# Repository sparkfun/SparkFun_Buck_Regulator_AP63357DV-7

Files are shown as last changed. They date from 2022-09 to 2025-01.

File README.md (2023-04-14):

SparkFun 5V Buck Regulator Breakouts - AP63357
========================================

<p align="center">
  <a href="https://github.com/sparkfun/SparkFun_Buck_Regulator_AP63357DV-7/issues" alt="Issues">
    </a>
  <a href="https://github.com/sparkfun/SparkFun_Buck_Regulator_AP63357DV-7/actions" alt="Actions">
    </a>
  <a href="https://github.com/sparkfun/SparkFun_Buck_Regulator_AP63357DV-7/blob/main/LICENSE.md" alt="License">
    </a>
  <a href="https://twitter.com/intent/follow?screen_name=sparkfun">
    </a>
</p>

These buck regulator boards feature the AP63357 from [Diodes Inc.](https://www.diodes.com/), a 3.5A synchronous buck converter with a wide input voltage range of 3.8V to 32V. The fully integrated 74m&ohm; high-side power MOSFET/40m low-side power MOSFET provide a high-efficiency step-down DC/DC conversion. The boards are configured to provide a regulated **5V** output and feature a high-voltage `EN` *(enable)* control pin that is rated up to 32V. The boards also include 0.1" spaced PTH pins to connect the input and output power and a copper pad is provided to attach a heat sink to the bottom of the board; to dissipate excess heat.

| [5V Buck Regulator (COM-21255)](https://www.sparkfun.com/products/21255) | [5V BabyBuck Regulator (COM-21256)](https://www.sparkfun.com/products/21256) |
| --- | --- |
| SparkFun Buck Regulator Breakout - 5V (AP63357DV) (https://www.sparkfun.com/products/21255) | SparkFun BabyBuck Regulator Breakout - 5V (AP63357DV) (https://www.sparkfun.com/products/21256) |
| The [Buck regulator breakout board](https://www.sparkfun.com/products/21255), has additional options for connecting input and output power. There is a pre-assembled screw terminal for a non-permanent connection and the option to solder on a [barrel jack](https://www.sparkfun.com/products/119) for an [external power supply](https://www.sparkfun.com/categories/308). The board also includes and red, power indication LED for when the power output is enabled. | Unlike its sibling, the [BabyBuck](https://www.sparkfun.com/products/21256) is a minimalistic board that sacrifices the connection options for space. Don't worry, though, because the PTH pins are still available to connect the input and output power. All of this snuggled up in a low-profile, .63" x .52" board. |

Repository Contents
-------------------

* **[/docs](/docs/)** - Online documentation files
    * [board_files](/docs/board_files/) - Files for the product design
        * [Eagle design files](/docs/board_files/eagle_files.zip) (.zip)
        * [Schematic](/docs/board_files/schematic.pdf) (.pdf)
        * [Dimensions](/docs/board_files/dimensions.pdf) (.pdf)
    * [component_documentation](/docs/component_documentation/) - Datasheets for hardware components
    * [img/hookup_guide/](/docs/img/hookup_guide/) - Images for hookup guide documentation
* **[/Hardware](/Hardware/)** - Eagle design files (.brd, .sch)

Documentation
--------------
* **[Hookup Guide (mkdocs)](http://docs.sparkfun.com/SparkFun_Buck_Regulator_AP63357DV-7/)** - Hookup Guide for the 5V Buck Regulator Breakouts

Product Variants
----------------
* **AP63357 - 5V Buck Regulators**
    * COM-21255: [SparkFun Buck Regulator Breakout - 5V (AP63357DV)](https://www.sparkfun.com/products/21255)
    * COM-21256: [SparkFun BabyBuck Regulator Breakout - 5V (AP63357DV)](https://www.sparkfun.com/products/21256)
* **AP63203 - 3.3V Buck Regulators**
    * COM-18356: [SparkFun Buck Regulator Breakout - 3.3V (AP63203)](https://www.sparkfun.com/products/18356)
    * COM-18357: [SparkFun BabyBuck Regulator Breakout - 3.3V (AP63203)](https://www.sparkfun.com/products/18357)
* **AP3429A - 3.3V & 1.8V Buck Regulators**
    * COM-21337: [SparkFun Buck Regulator Breakout - 3.3V (AP63203)](https://www.sparkfun.com/products/21337)
    * COM-21338: [SparkFun Buck Regulator Breakout - 1.8V (AP63203)](https://www.sparkfun.com/products/21338)

Version History
---------------
* [v01](https://github.com/sparkfun/SparkFun_Buck_Regulator_AP63357DV-7/releases/tag/v01) - Initial Release

License Information
-------------------

This product is _**open source**_! 

Please review the LICENSE.md file for license information. 

If you have any questions or concerns about licensing, please contact technical support on our [SparkFun forums](https://forum.sparkfun.com/viewforum.php?f=152).

Distributed as-is; no warranty is given.

- Your friends at SparkFun.

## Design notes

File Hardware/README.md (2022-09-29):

SparkFun <PRODUCT NAME> Design Files
=====================================

The .sch and .brd files hare are Eagle CAD schematic and PCB design files from SparkFun Electronics.
A freeware version of Autodesk Eagle can be found [here](https://www.autodesk.com/products/eagle/free-download).

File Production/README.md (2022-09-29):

SparkFun <PRODUCT NAME> Production Files
=========================================

These are the production files SparkFun uses for printing PCBs.

License Information
-------------------
This product is open source! 

The hardware is released under [Creative Commons ShareAlike 4.0 International](https://creativecommons.org/licenses/by-sa/4.0/).

Please use, reuse, and modify these files as you see fit. Please maintain attribution to SparkFun Electronics and release anything derivative under the same license.

Distributed as-is; no warranty is given.

- Your friends at SparkFun.

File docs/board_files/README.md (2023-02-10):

board_files directory
====================

1. A `dimensions.pdf` file containing the boards' measurements.
2. A `schematic.pdf` file containing the boards' schematics.
3. An `eagle_files.zip` folder containing the Eagle CAD schematics (`*.sch`) and PCB design (`*.brd`) files.
    * A freeware version of Autodesk Eagle can be found [here](https://www.autodesk.com/products/eagle/free-download).

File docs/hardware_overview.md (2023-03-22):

---
icon: material/cog
---

!!! hot "**Danger:** These boards can get <span style="color: #ff1744;">extremely **HOT** :material-thermometer-alert:</span>"
	
	Please handle these boards with the utmost caution. Users can easily burn themselves when the board outputs anything over 2A. 

## Board Dimensions
The board dimensions are illustrated in the drawing below; the listed measurements are in inches.

<figure markdown>
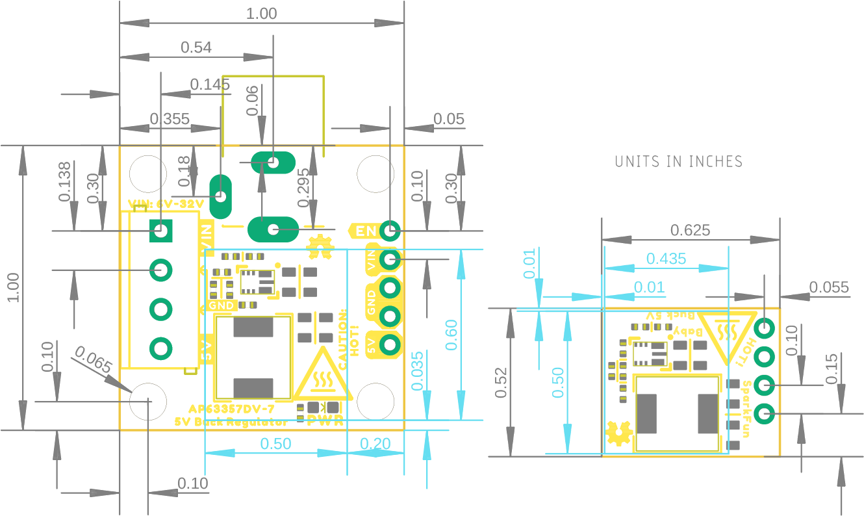
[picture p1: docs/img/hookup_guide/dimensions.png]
Board Dimensions

<figcaption markdown>
[Board dimensions (PDF)](../board_files/dimensions.pdf) for the 5V buck regulator breakouts (AP63357), in inches.
</figcaption>
</figure>

??? tip "Need more measurements?"
	For more information about the board's dimensions, users can download the [eagle files](../board_files/eagle_files.zip) for the board. These files can be opened in Eagle and additional measurements can be made with the dimensions tool.

	??? info ":octicons-download-16:{ .heart } Eagle - Free Download!"
		Eagle is a [CAD]("computer-aided design") program for electronics that is free to use for hobbyists and students. However, it does require an account registration to utilize the software.

		<center>
		[Download from<br>:autodesk-primary:{ .autodesk }](https://www.autodesk.com/products/eagle/free-download "Go to downloads page"){ .md-button .md-button--primary width="250px" }
		</center>
	
	??? info ":straight_ruler: Dimensions Tool"
		This video from Autodesk demonstrates how to utilize the dimensions tool in Eagle, to include additional measurements:

		<center>
		<div class="video">
		<iframe src="https://www.youtube.com/embed/dZLNd1FtNB8" title="EAGLE Dimension Tool" frameborder="0" allow="accelerometer; autoplay; clipboard-write; encrypted-media; gyroscope; picture-in-picture" allowfullscreen></iframe>
		</div>
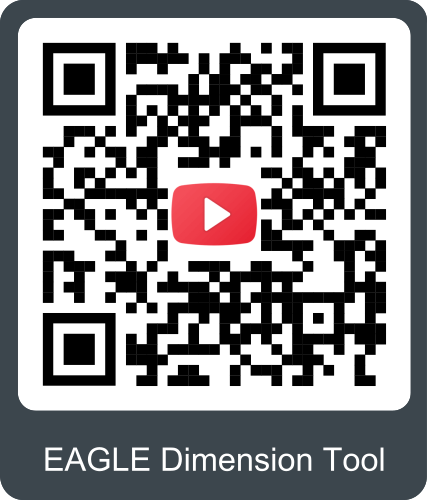
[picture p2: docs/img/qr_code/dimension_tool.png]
QR code to play video
		
		</center>

## Power
Users are provided with [PTH](https://en.wikipedia.org/wiki/Through-hole_technology "Plated Through Holes") to connect their external power supply, the output voltage from the board, and the [`EN`](#power-control "Enable") power control pin for the buck regulator. The AP63357 buck regulator has an input voltage range is **3.8V** to **32V**. However, the boards require a **6V** minimum power supply to operate; as it is a step-down DC/DC converter with a 5V output. *(i.e. The boards cannot step-up or boost the voltage output.)*

<center>
<table class="pdf">
	<tr>
		<td align="center">
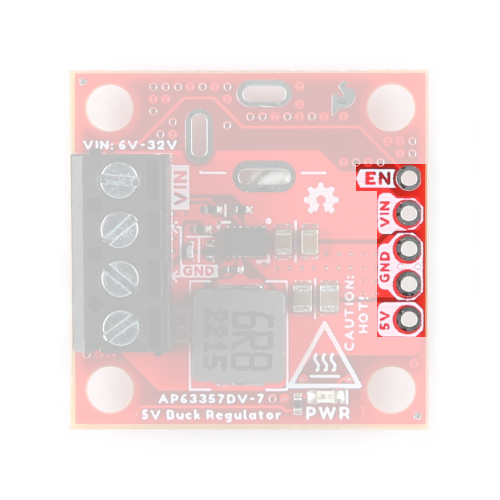
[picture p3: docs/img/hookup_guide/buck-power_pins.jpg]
			<br>
			<i>The PTH power pins on the 5V Buck Regulator (AP63357DV).</i>
		</td>
		<td align="center">
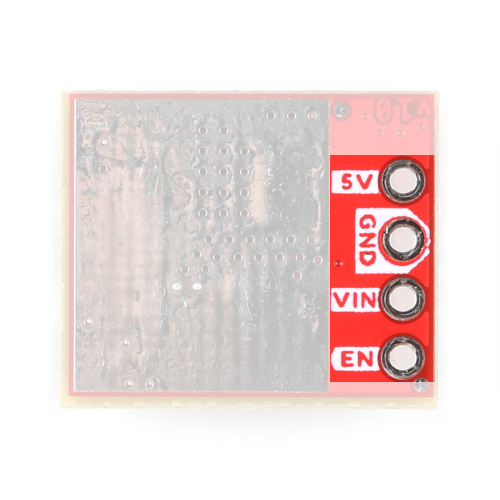
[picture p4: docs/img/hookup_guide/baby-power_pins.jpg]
			<br>
			<i>The PTH power pins on the 5V Baby Buck Regulator (AP63357DV), viewed from the bottom.</i>
		</td>
	<tr>
</table>
</center>

<div class="grid cards hide" markdown>

-   <figure markdown>
	
	<figcaption markdown>
	The PTH power pins on the 5V Buck Regulator (AP63357DV).
	</figcaption>
	</figure>

-   <figure markdown>
	
	<figcaption markdown>
	The PTH power pins the 5V Baby Buck Regulator (AP63357DV), viewed from the bottom.
	</figcaption>
	</figure>

</div>

Below, is a general summary of the circuitry on the board:

* **`VIN`** - Power supply input *(**6V to 32V**)*
    * The [undervoltage lockout](#undervoltage-lockout "UVLO") will engage intermittently if the input voltage is below **6V**.
* **`EN`** - Enables the power output of the board
	* Has an input voltage range up to **32V** 
	* Must be pulled `HIGH` above **1.18V** to enable the power output.
* **`5V`** - Regulated 5V output *(up to 3.5A)*
* **`GND`** - The common ground or the 0V reference for the board

!!! info
	For more details, users can reference the [schematic](../board_files/schematic.pdf) and the [datasheets of the individual components](../component_documentation.md) in the power circuitry.

!!! tip "Limitations - Load Current"
	* While the IC is rated up to 3.5A, users may experience thermal limitations towards that maximum.
		* Users should reasonably expect to be able to place a maximum 3A load on the boards when using a heat sink and active cooling (i.e. fan). 
		* At the peak load of 3.5A, users will need sufficient cooling to prevent the IC's [thermal shutdown](#thermal-characteristics "The AP63357 has a 170&deg;C (338&deg;F) thermal shutdown temperature.")
	* With a heat sink, we have found users can expect to draw up to 2.5A
	* Without a heat sink or active cooling, we recommend users not load the boards with more than 1.5A.

??? tip "Quiescent Current Draw"
    Users should expect a maximum quiescent current draw of ~365&micro;A from the board due to the voltage divider for the [UVLO](#undervoltage-lockout "Undervoltage Lockout"). For a lower quiescent current, users can modify the board by removing the voltage divider's resistors.

	<div class="grid cards" markdown>

	-	Measured Values

		---

		<center>
		
		| Input Voltage (V) | I~q~ (&micro;A) | I~q~ - Power Enabled (&micro;A) |
		| :-: | :-: | :-: |
		| 6 | 65 | 196 |
		| 12 | 129 | 209 |
		| 24 | 260 | 290.5 |
		| 32 | 330 | 355 |

		</center>

		!!! info
			For more information about the measured values for the quiescent current, please refer to this [GitHub issue](https://github.com/sparkfun/SparkFun_Buck_Regulator_AP63357DV-7/issues/1).

	-	=== "Buck Regulator"
			
			<figure markdown>
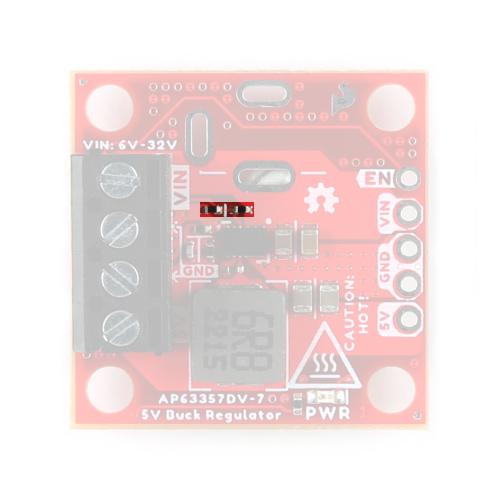
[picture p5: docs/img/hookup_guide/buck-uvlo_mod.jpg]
			
			<figcaption markdown>
			Resistors for the UVLO on the 5V Buck Regulator (AP63357DV).
			</figcaption>
			</figure>
	
		=== "BabyBuck Regulator"
			
			<figure markdown>
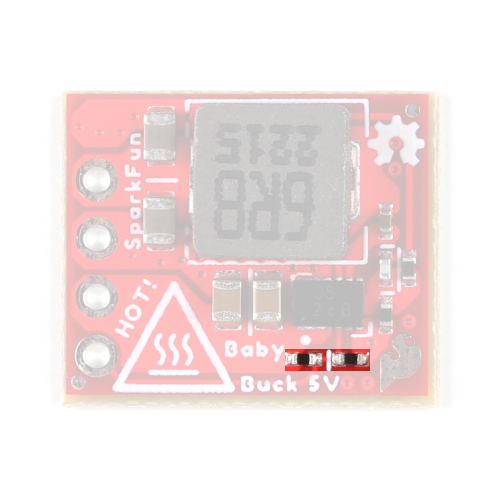
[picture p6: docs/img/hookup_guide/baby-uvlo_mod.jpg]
			
			<figcaption markdown>
			Resistors for the UVLO on the 5V Baby Buck Regulator (AP63357DV).
			</figcaption>
			</figure>
		
		!!! danger
			Modifying a board to remove the voltage divider, requires advanced soldering skills. Users should **not** attempt this modification unless it is absolutely, necessary and they are confident in their skills because the board can be permanently damaged.

	</div>

### Alternative Connections

!!! info  "Buck Regulator *(only)*"
	!!! warning "The following features are only available on the Buck Regulator and are <u>not</u> available on BabyBuck Regulator."

	=== "Barrel Jack"
		PTH *(slots)* are provided for users to add a [barrel jack connector](https://www.sparkfun.com/products/119) to the top or bottom of the board. This provides users with an alternative method to connect a power supply to their board.

		<figure markdown>
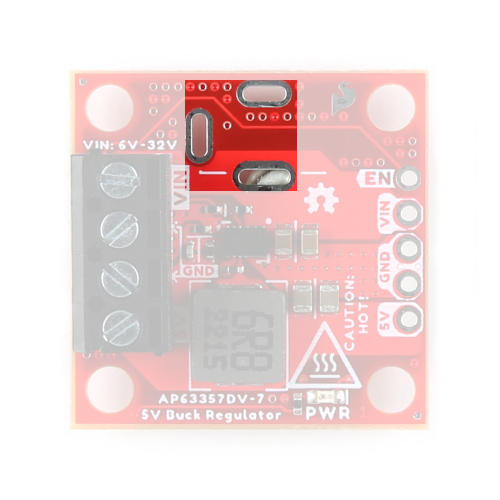
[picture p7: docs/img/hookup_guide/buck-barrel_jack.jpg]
		
		<figcaption markdown>The plated slots for a barrel jack connector on the 5V Buck Regulator (AP63357DV).</figcaption>
		</figure>

	=== "Screw Terminals"
		A screw terminal is provided for users, as a non-permanent solution, to easily connect wires to the board. The screw terminal is compatible with the following wire sizes from **26AWG** to **16AWG**.

		<figure markdown>
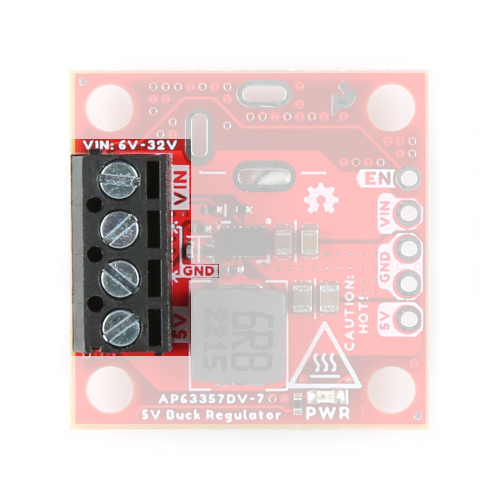
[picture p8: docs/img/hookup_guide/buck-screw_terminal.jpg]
		
		<figcaption markdown>The screw terminal on the 5V Buck Regulator (AP63357DV).</figcaption>
		</figure>

### Power LED
The red, power (`PWR`) LED will light up when the switching power output is enabled. *(Not available on baby buck regulator board.)*

<figure markdown>
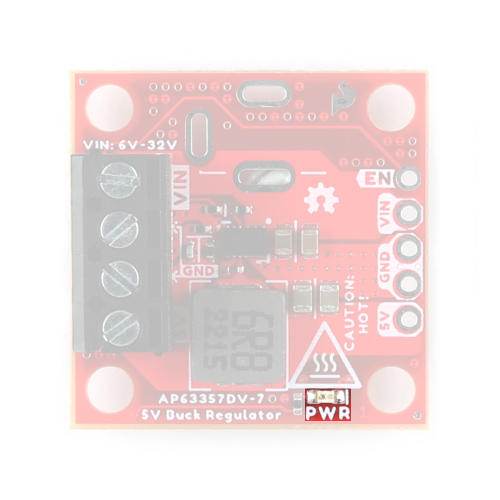
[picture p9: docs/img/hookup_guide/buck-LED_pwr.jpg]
Power LED

<figcaption markdown>
The `PWR` status LED indicator for the 5V Buck Regulator (AP63357DV).
</figcaption>
</figure>

### Power Control
There is a high-voltage enable pin (`EN`) to control the output voltage *(i.e. on/off)*, with a typical threshold voltage of **1.18V** and a range up to **32V**

* Users should pull the `EN` pin high *(above 1.18V)* to enable the switching power output and pull the pin low to disable it.
* As a high-voltage pin, users can also connect the `EN` pin to `VIN` to automatically start up the device.
* Users can also configure the `EN` pin to set the [UVLO](#undervoltage-lockout "Undervoltage Lockout") threshold.

!!! info "Default Configuration"
	On our boards, the `EN` pin is used to set the [UVLO](#undervoltage-lockout "Undervoltage Lockout") threshold. Therefore, the power output from the board is enabled by default.

<center>
<table class="pdf">
	<tr>
		<td align="center">
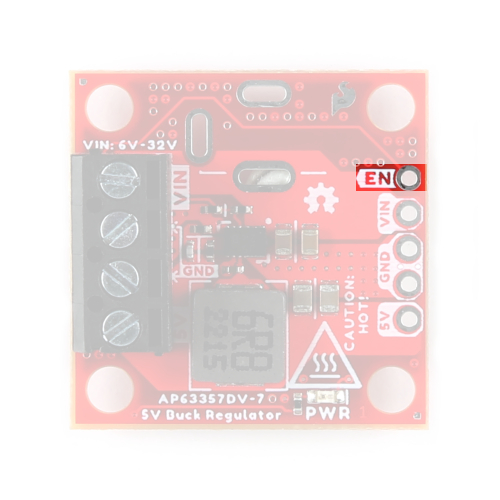
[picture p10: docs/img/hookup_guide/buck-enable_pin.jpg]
			<br>
			<i>Enable pin on the 5V Buck Regulator (AP63357DV).</i>
		</td>
		<td align="center">
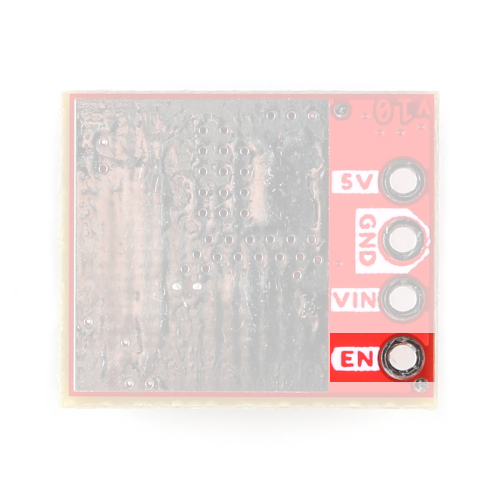
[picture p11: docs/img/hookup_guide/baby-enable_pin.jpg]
			<br>
			<i>Enable pin on the 5V Baby Buck Regulator (AP63357DV), viewed from the bottom.</i>
		</td>
	<tr>
</table>
</center>

<div class="grid cards hide" markdown>

-   <figure markdown>
	
	<figcaption markdown>
	Enable pin on the 5V Buck Regulator (AP63357DV).
	</figcaption>
	</figure>

-   <figure markdown>
	
	<figcaption markdown>
	Enable pin on the 5V Baby Buck Regulator (AP63357DV), viewed from the bottom.
	</figcaption>
	</figure>

</div>

## AP63357
The [AP63357](../component_documentation/AP63356-AP63357.pdf) from [Diodes Incorporated](https://www.diodes.com/), is a 3.5A, synchronous buck converter with a wide input voltage range of 3.8V to 32V. The device fully integrates a 74m&ohm; high-side power MOSFET and a 40m&ohm; low-side power MOSFET to provide high-efficiency step-down DC-DC conversion. When operating in PFM during light load conditions, the AP63357 can achieve a power efficiency of up to 86% with a 5mA load. Additionally, under a no-load, non-switching condition, the quiescent current is typically 22&micro;A; and when disabled, the device shutdown supply current is only 1μA.

The AP63357 features a high-voltage `EN` pin that can be directly connected to `VIN` to automatically start up the device. To prevent output voltage overshoot and inrush current, the AP63357 also has a built-in 4ms soft-start time. Users can also configure the `EN` pin to set the [undervoltage lockout](#undervoltage-lockout "UVLO") threshold.

<center>
<table class="pdf" markdown="1">
<tr markdown="1">
<td rowspan="2" markdown="block">
Features:

* VIN 3.8V to 32V
* 3.5A Continuous Output Current
* 0.8V ± 1% Reference Voltage
* 22&micro;A Low Quiescent Current (Pulse Frequency Modulation)
* 450kHz Switching Frequency
* Supports Pulse Frequency Modulation (PFM)
	* Up to 86% Efficiency at 5mA Light Load
* Proprietary Gate Driver Design for Best EMI Reduction
* Frequency Spread Spectrum (FSS) to Reduce EMI
* Low-Dropout (LDO) Mode
* Power Good Indicator with 5MΩ Internal Pull-up
* Precision Enable Threshold to Adjust UVLO
* Protection Circuitry
	* Undervoltage Lockout (UVLO)
	* Output Undervoltage Protection (UVP)
	* Cycle-by-Cycle Peak Current Limit
	* Thermal Shutdown
</td>
<td align="center">
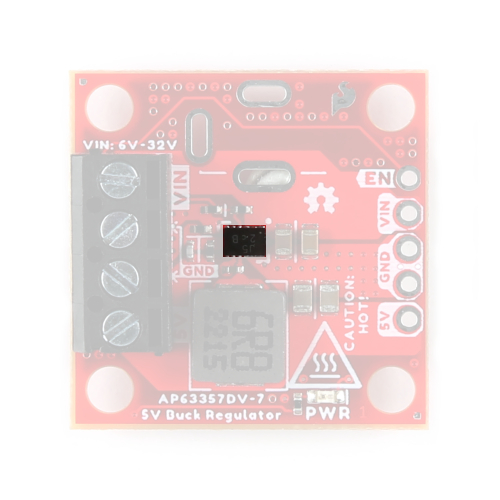
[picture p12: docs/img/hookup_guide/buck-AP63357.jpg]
<br>
<i>AP63357 chip on the 5V Buck Regulator (AP63357DV).</i>
</td>
</tr>
<tr>
<td align="center">
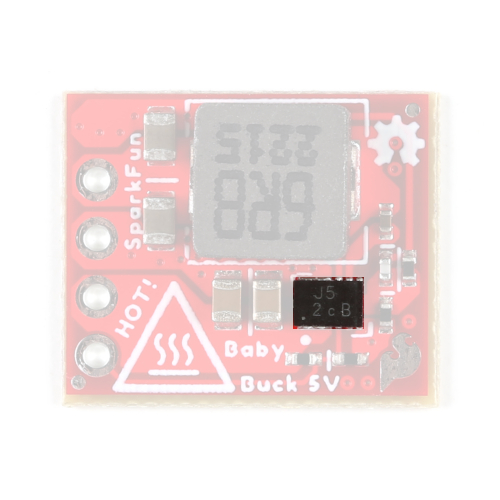
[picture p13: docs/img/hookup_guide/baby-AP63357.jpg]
<br>
<i>AP63357 chip on the 5V Baby Buck Regulator (AP63357DV).</i>
</td>
<tr>
</table>
</center>

<div class="grid cards hide" markdown>

-   Features:

	* VIN 3.8V to 32V
	* 3.5A Continuous Output Current
	* 0.8V ± 1% Reference Voltage
	* 22&micro;A Low Quiescent Current (Pulse Frequency Modulation)
	* 450kHz Switching Frequency
	* Supports Pulse Frequency Modulation (PFM)
		* Up to 86% Efficiency at 5mA Light Load
	* Proprietary Gate Driver Design for Best EMI Reduction
	* Frequency Spread Spectrum (FSS) to Reduce EMI
	* Low-Dropout (LDO) Mode
	* Power Good Indicator with 5MΩ Internal Pull-up
	* Precision Enable Threshold to Adjust UVLO
	* Protection Circuitry
		* Undervoltage Lockout (UVLO)
		* Output Undervoltage Protection (UVP)
		* Cycle-by-Cycle Peak Current Limit
		* Thermal Shutdown

<section class="grid cards" markdown>

-	<figure markdown>
	
	<figcaption markdown>
	AP63357 chip on the 5V Buck Regulator (AP63357DV).
	</figcaption>
	</figure>

-   <figure markdown>
	
	<figcaption markdown>
	AP63357 chip on the 5V Baby Buck Regulator (AP63357DV).
	</figcaption>
	</figure>

</section>

</div>

??? tip "Power Efficiency"
	Users should expect a power efficiency close to the charts presented in Figures 3, 25, and 26 in the [datasheet](../component_documentation/AP63356-AP63357.pdf) *(i.e. 70% with smaller loads and up to 95% with larger loads)*. While the efficiency varies with the load current and cooling, we didn't see anything below 85% for most of our [test cases](#thermal-characteristics "from 100 mA to 3A").

	<figure markdown>
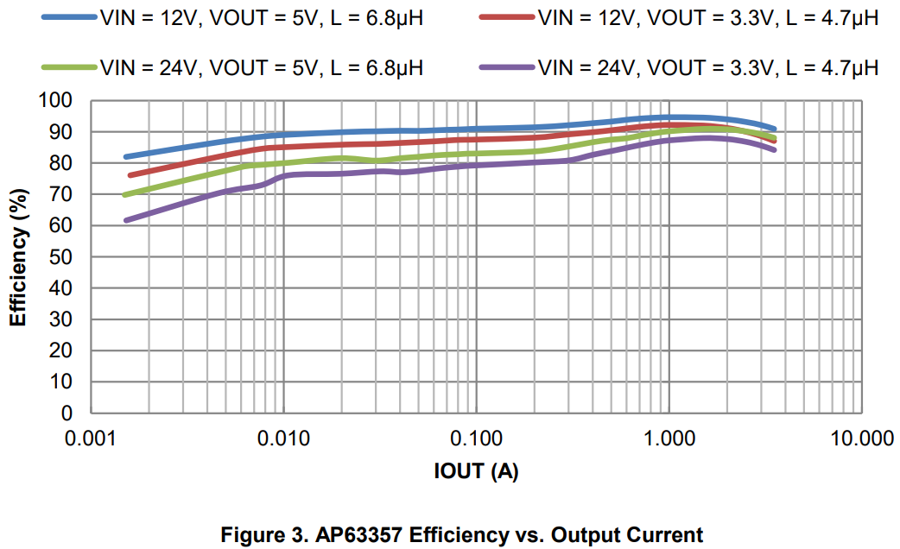
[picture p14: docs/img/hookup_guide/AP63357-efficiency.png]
	
	<figcaption markdown>
	Figure 3 from the [datasheet](../component_documentation/AP63356-AP63357.pdf).
	</figcaption>
	</figure>

??? tip "Line and Load Regulation"
	Users should expect a line and load regulation close to the charts presented in Figures 27 and 28 in the [datasheet](../component_documentation/AP63356-AP63357.pdf) *(i.e. 5.0 &plusmn;0.2V)*. While these vary with the load current and cooling, we didn't see an output voltage below 5V in our tests.
	
	Additionally, we will note that there is some noise in the output voltage, due to the switching of the regulator. While this increases with the load current, for most users it won't be relevant to their use case.

	<figure markdown>
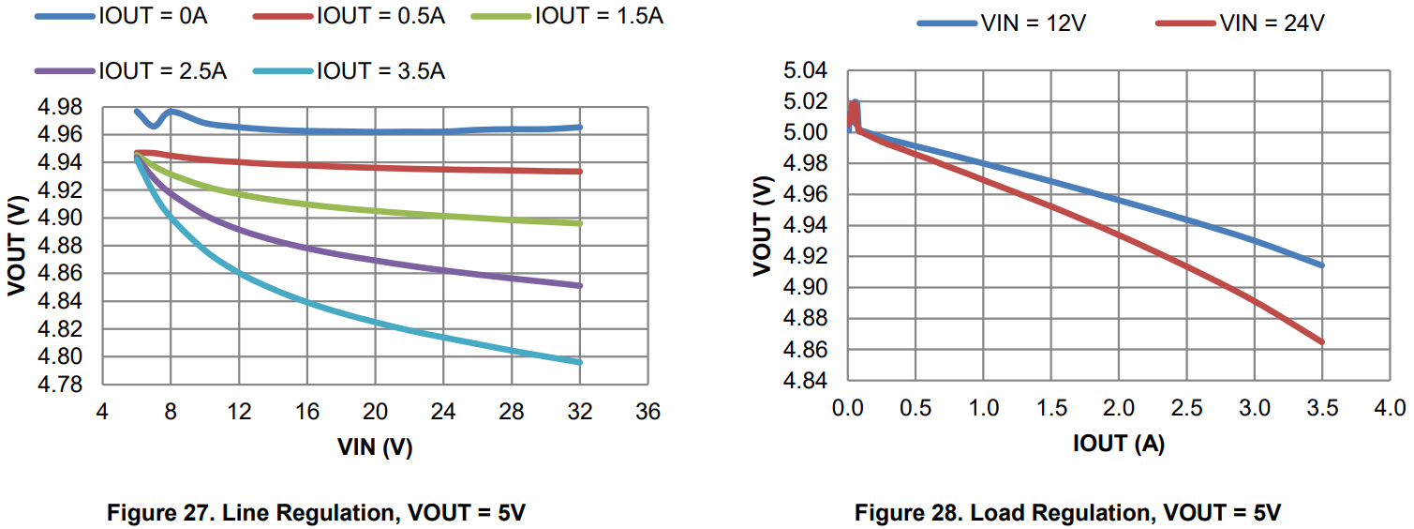
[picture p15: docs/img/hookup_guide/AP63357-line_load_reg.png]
	
	<figcaption markdown>
	Figures 27 and 28 from the [datasheet](../component_documentation/AP63356-AP63357.pdf).
	</figcaption>
	</figure>

###  Undervoltage Lockout
An undervoltage lockout is implemented to prevent the IC from insufficient input voltages. The AP63357 device has a UVLO comparator that monitors the input voltage and disables it when the input voltage falls below 3.08V. Some applications may desire higher `VIN` UVLO threshold voltages than is provided by the default setup. A pull-up current source on the `EN` pin, along with an external resistive divider (R3 and R4) configure the `VIN` UVLO threshold voltage, as shown in **Figure 37** of section **5 - Adjusting Undervoltage Lockout (UVLO)** of the [datasheet](../component_documentation/AP63356-AP63357.pdf).

The resistive divider's resistor values are calculated by:

\begin{align}
    R3 = \frac{ 0.915 * V_{ON} - V_{OFF} }{ 4.127 \mu A } \tag{ Eq. 2 } \label{eq:2} \\
    R4 = \frac{ 1.08 * R3 }{ V_{OFF} - 1.08V + 5.5 \mu A * R3 } \tag{ Eq. 3 } \label{eq:3}
\end{align}

Where:

(1) V~ON~ is the rising edge VIN voltage to enable the regulator and is greater than 3.6V<br>
(2) V~OFF~ is the falling edge VIN voltage to disable the regulator and is greater than 3.18V
{ .annotate }

1.	Configured at 5.6V
2.	Configured at 5.18V

!!! tip
	While the undervoltage lockout is configured for **5.6V** on the high end, users should provide at least **6V** for the input voltage. Based on testing, we found **6V** to be a more realistic expectation to avoid an undervoltage lockout from the boards.

## Heat Sink Pad
!!! hot "**Danger:** These boards can get <span style="color: #ff1744;">extremely **HOT** :material-thermometer-alert:</span>"
	
	Please handle these boards with the utmost caution. Users can easily burn themselves when the board outputs anything over 2A. 

A platted copper pad is provided on the back of the boards, where users can add a heat sink to dissipate excess heat generated by the AP63357. While the pad size is slightly different between each board, they both can accommodate the [copper heatsink](https://www.sparkfun.com/products/18704) in our catalog.

* Buck: 0.5" x 0.6"
* BabyBuck: 0.435" x 0.5"

<center>
<table class="pdf">
	<tr>
		<td align="center">
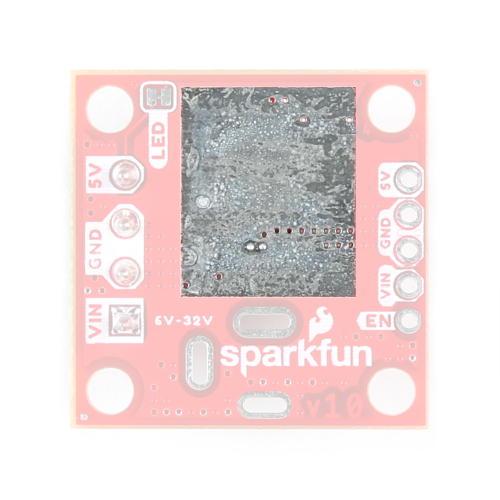
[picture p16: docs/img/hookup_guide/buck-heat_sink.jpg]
			<br>
			<i>Heat sink pad on the back of the 5V Buck Regulator (AP63357DV).</i>
		</td>
		<td align="center">
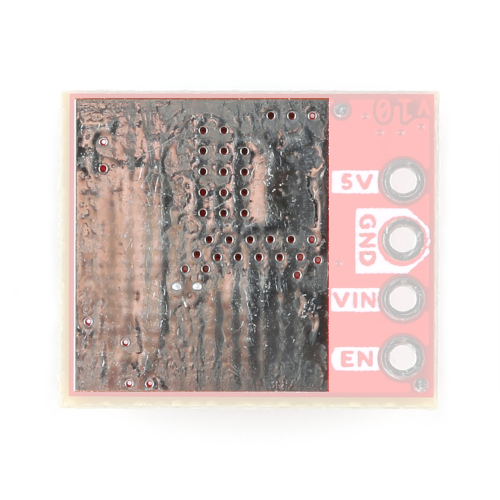
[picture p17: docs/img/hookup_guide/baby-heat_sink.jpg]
			<br>
			<i>Heat sink pad on the back of the 5V Baby Buck Regulator (AP63357DV).</i>
		</td>
	<tr>
</table>
</center>

<div class="grid cards hide" markdown>

-   <figure markdown>
	
	<figcaption markdown>
	Heat sink pad on the back of the 5V Buck Regulator (AP63357DV).
	</figcaption>
	</figure>

-   <figure markdown>
	
	<figcaption markdown>
	Heat sink pad on the back of the 5V Baby Buck Regulator (AP63357DV).
	</figcaption>
	</figure>

</div>

### Thermal Characteristics
??? info "Thermal Shutdown Temperature"
	The AP63357 has a 170&deg;C (338&deg;F) thermal shutdown temperature.

The thermal limitations of the board will dictate the maximum load current our boards can provide. Below is a chart of some testing we have performed using the full-size, [5V Baby Buck Regulator](https://www.sparkfun.com/products/21255) with a [heat sink](https://www.sparkfun.com/products/18704) attached to the back of the board.

<figure markdown>
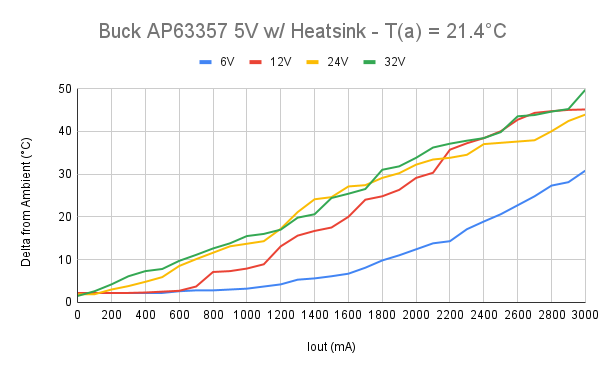
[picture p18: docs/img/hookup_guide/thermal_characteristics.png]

<figcaption markdown>
Thermal characteristics for the [5V Baby Buck Regulator](https://www.sparkfun.com/products/21255) with a [heat sink](https://www.sparkfun.com/products/18704).
</figcaption>
</figure>

!!! info
	For more information on the thermal characteristics of the AP63357, please refer to the [datasheet](../component_documentation/AP63356-AP63357.pdf).

	??? tip "Thermal Limitations on Load Current"
		* Without a heat sink or active cooling, we recommend users not load the boards with more than 1.5A.
		* With a heat sink, we have found users can expect to draw up to 2.5A
		* While the IC is rated up to 3.5A, users may experience thermal limitations towards that maximum.
			* Users should reasonably expect to be able to place a maximum 3A load on the boards when using a heat sink and active cooling (i.e. fan). 
			* At the peak load of 3.5A, users will need sufficient cooling to prevent the IC's [thermal shutdown](#thermal-characteristics "The AP63357 has a 170&deg;C (338&deg;F) thermal shutdown temperature.").

## Jumper
??? note "Never modified a jumper before?"
	Check out our <a href="https://learn.sparkfun.com/tutorials/664">Jumper Pads and PCB Traces tutorial</a> for a quick introduction!
	<p align="center">
		<a href="https://learn.sparkfun.com/tutorials/664">How to Work with Jumper Pads and PCB Traces<br>
		</a>
	</p>

There is a jumper on the back of the board that can be used to easily modify a hardware connection on the board. *(Not available on baby buck regulator board.)*

* **PWR** - This jumper can be used to remove power to the `PWR` LED. 

<figure markdown>
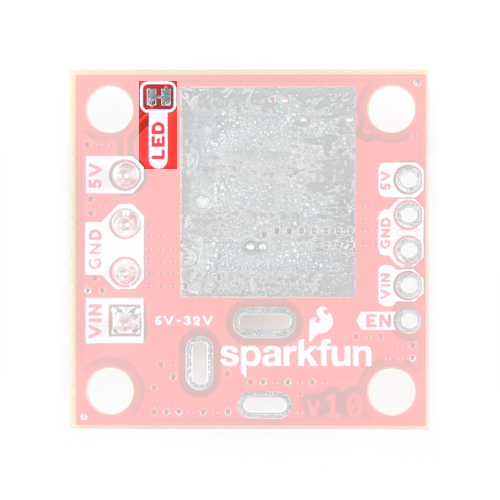
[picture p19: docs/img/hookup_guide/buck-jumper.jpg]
Jumpers

<figcaption markdown>
The LED jumper on the back of the 5V Buck Regulator (AP63357DV).
</figcaption>
</figure>

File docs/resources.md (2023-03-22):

## Product Resources

<section class="grid cards col-3" style="grid-template-columns: repeat(auto-fit,minmax(8rem,1fr));" markdown>

- **Composite (Both Boards)**

    ---

    * :sfe-logo: [Product Category](https://www.sparkfun.com/categories/tags/buck-)
    * :fontawesome-solid-file-pdf: [Board Dimensions](./board_files/dimensions.pdf)
    * :fontawesome-solid-file-pdf: [AP63357 Datasheet](./component_documentation/AP63356-AP63357.pdf)
    * :material-folder-cog: Design Files:
        * :fontawesome-solid-file-pdf: [Schematic](./board_files/schematic.pdf)
        * :material-folder-zip: [Eagle Files](./board_files/eagle_files.zip)

- **Buck Regulator Breakout - 5V (AP63357)**

    ---

    * :sfe-logo: [5V Buck Regulator](https://www.sparkfun.com/products/21255)
    * :fontawesome-solid-file-pdf: [Schematic](./board_files/schematic-Buck5V.pdf)
    * :material-folder-zip: [Eagle Files](./board_files/eagle_files-Buck5V.zip)
    * :fontawesome-solid-file-pdf: [Board Dimensions](./board_files/dimensions-Buck5V.pdf)

- **BabyBuck Regulator Breakout - 5V (AP63357)**

    ---

    * :sfe-logo: [5V BabyBuck Regulator](https://www.sparkfun.com/products/21256)
    * :fontawesome-solid-file-pdf: [Schematic](./board_files/schematic-BabyBuck5V.pdf)
    * :material-folder-zip: [Eagle Files](./board_files/eagle_files-BabyBuck5V.zip)
    * :fontawesome-solid-file-pdf: [Board Dimensions](./board_files/dimensions-BabyBuck5V.pdf)

</section>

* :material-youtube: [SFE Product Showcase Video](https://youtu.be/g2MgO2fjqsw)
* :material-github: [GitHub Hardware Repo](https://github.com/sparkfun/SparkFun_Buck_Regulator_AP63357DV-7)

## Additional Resources

* [DC/DC Converter Product Category](https://www.sparkfun.com/categories/tags/dc-dc-converter)
* :material-account-supervisor: [SparkFun Technical Assistance](https://www.sparkfun.com/technical_assistance)

## 🏭&nbsp;Manufacturer's Resources
Diodes Incorporated also provides great resources for the AP63357 Buck Regulator: 

* [AP63357 Product Page](https://www.diodes.com/part/view/AP63357/)
    * :material-file-document-multiple: [Technical Documentation](https://www.diodes.com/part/view/AP63357/#tab-details)
* :material-head-question: [Technical Support Page](https://www.diodes.com/about/contact-us/technical-support/)

<center>
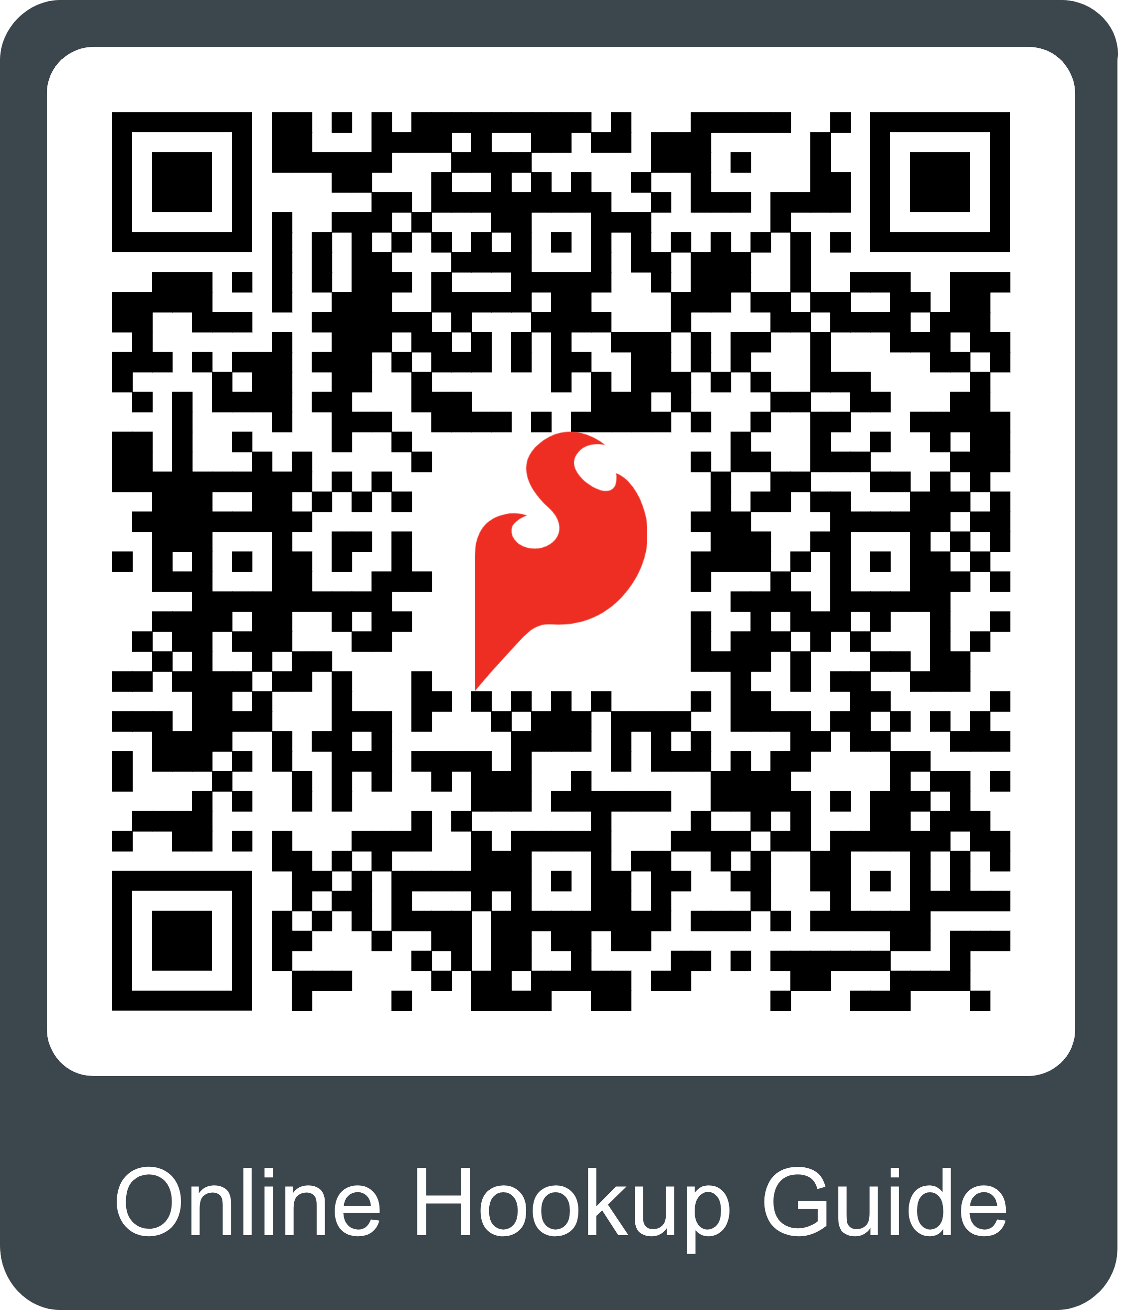
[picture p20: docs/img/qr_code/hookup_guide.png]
QR code to the hookup guide

</center>

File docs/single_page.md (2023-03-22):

---
hide:
  - navigation
  - toc
icon: fontawesome/solid/scroll
---

--8<-- "./docs/getting_started.md:5"

# Hardware Overview
--8<-- "./docs/hardware_overview.md:5"

# Hardware Assembly
--8<-- "./docs/hardware_assembly.md:5"

# Troubleshooting Tips
--8<-- "./docs/troubleshooting_tips.md:5"

# Test Setup
--8<-- "./docs/load_test.md:5"

# Resources:
--8<-- "./docs/resources.md"

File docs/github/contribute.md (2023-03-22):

# Contribute: Make an Augmentation!
Spot an improvement opportunity? Feel free to contribute to our open-source design and documentation. 

## :material-file-document-multiple:&nbsp;Improve our Documentation
All of this documentation can be modified by you! Please help us make it better.

* These pages are contained in the [`docs` folder](https://github.com/sparkfun/SparkFun_Buck_Regulator_AP63357DV-7/tree/main/docs) of the [SparkFun Buck Regulator AP63357DV-7 repository](https://github.com/sparkfun/SparkFun_Buck_Regulator_AP63357DV-7).

### Submit a Correction

1. With a GitHub account, [fork this repository](https://github.com/sparkfun/SparkFun_Buck_Regulator_AP63357DV-7/fork).
2. Add your corrections or improvements to the markdown file.
3. File a pull request with your changes, and enjoy making the ~~words~~ ~~worlds~~ world a better place.
	* Once received, the documentation specialist will automatically be notified.
	* We will review your suggested improvements to make sure they are correct and fit within our documentation standards.

## :material-cog:&nbsp;Improve our Hardware Design
All of our designs are open-source! Please help us make it better.

* Our board design files are contained in the [`Hardware` folder](https://github.com/sparkfun/SparkFun_Buck_Regulator_AP63357DV-7/tree/main/Hardware) of the [SparkFun Buck Regulator AP63357DV-7 repository](https://github.com/sparkfun/SparkFun_Buck_Regulator_AP63357DV-7).

1. With a GitHub account, [fork this repository](https://github.com/sparkfun/SparkFun_Buck_Regulator_AP63357DV-7/fork).
2. Add your design augmentation(s)
3. File a pull request with your changes, and enjoy making the ~~words~~ ~~worlds~~ world a better place.
	1. Once received, the engineer in charge of the original design will automatically be notified.
	2. We will review your suggested improvement(s) to verify that they are within our board design standards and meet our product design requirements.
	3. If approved, we will flag these changes for our next board revision. Congrats! 🍻

		!!! info
			Even if your suggestion is accepted, these changes may not be immediately available for purchase. We may have to cycle through our current product inventory first.

## Contributors&nbsp;:clap:
Let's provide some recognition to the contributors for this project!

GitHub Contributors Image
<br>


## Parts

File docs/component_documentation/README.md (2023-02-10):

component_documentation directory
====================

A copy of the datasheets, user manuals, programming guides, etc. of the major electrical components on the board.

* 5V Buck Regulator: [AP63357](../component_documentation/AP63356-AP63357.pdf) (PDF)

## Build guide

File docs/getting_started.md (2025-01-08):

---
icon: material/book-open-page-variant
---

# Getting Started

!!! hot "**Danger:** These boards can get <span style="color: #ff1744;">extremely **HOT** :material-thermometer-alert:</span>"
	
	Please handle these boards with the utmost caution. Users can easily burn themselves; especially, when the board outputs anything over 2A. 

!!! note
	The SparkFun [Buck Regulator Breakout - 5V (AP63357DV)](https://www.sparkfun.com/products/21255) and [BabyBuck Regulator Breakout - 5V (AP63357DV)](https://www.sparkfun.com/products/21256) have similar features to our previous [3.3V buck regulators (AP63203)](https://learn.sparkfun.com/tutorials/buck-regulator-hookup-guide).

## Introduction
These boards feature the AP63357 from [Diodes Inc.](https://www.diodes.com/), a 3.5A synchronous buck converter with a wide input voltage range of 3.8V to 32V. The fully integrated 74m&ohm; high-side power MOSFET/40m low-side power MOSFET provide a high-efficiency step-down DC/DC conversion. The boards are configured to provide a regulated **5V** output and feature a high-voltage `EN` *(enable)* control pin that is rated up to 32V. The boards also include 0.1" spaced PTH pins to connect the input and output power and a copper pad is provided to attach a heat sink to the bottom of the board; to dissipate excess heat.

<section class="grid cards" style="grid-template-columns: repeat(auto-fit,minmax(8rem,1fr));" markdown>

-	<a href="https://www.sparkfun.com/products/21255">
	**5V Buck Regulator**<br>
	**SKU:** COM-21255

	---

	<figure markdown>
	Product image
	</figure></a>

	The [Buck regulator breakout board](https://www.sparkfun.com/products/21255), has additional options for connecting input and output power. There is a pre-assembled screw terminal for a non-permanent connection and the option to solder on a [barrel jack](https://www.sparkfun.com/products/119) for an [external power supply](https://www.sparkfun.com/categories/308). The board also includes and red, power indication LED for when the power output is enabled.

	<center>
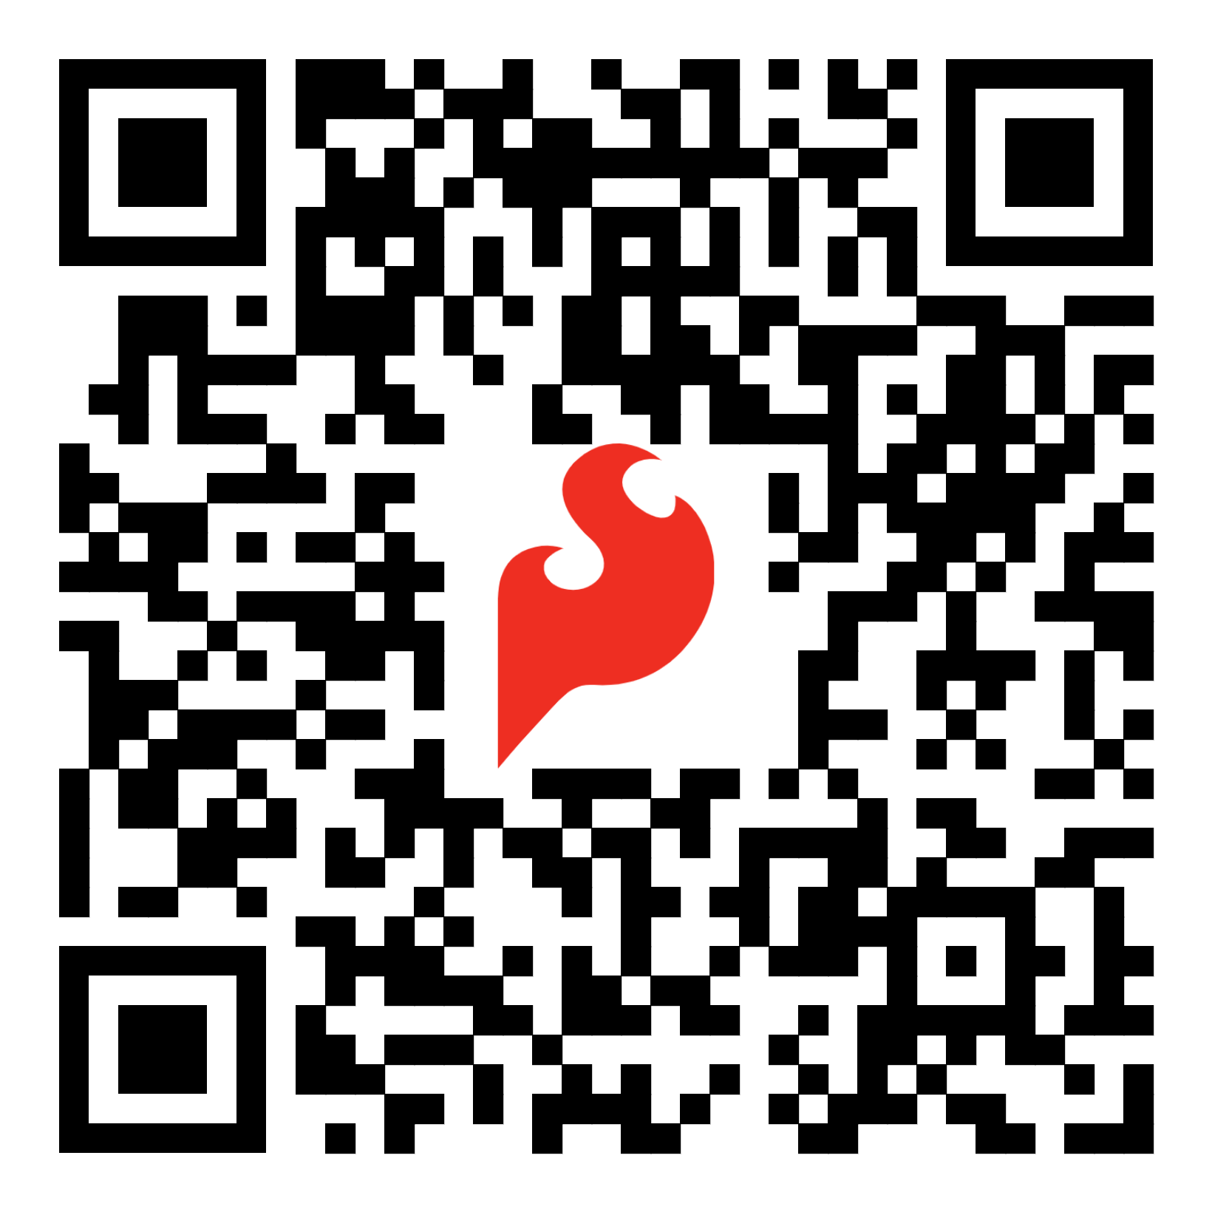
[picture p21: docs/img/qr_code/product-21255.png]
QR code to product page
	[&nbsp;&nbsp;&nbsp;Purchase from SparkFun :fontawesome-solid-cart-plus:{ .heart }](https://www.sparkfun.com/products/21255){ .md-button .md-button--primary }
	</center>

-	<a href="https://www.sparkfun.com/products/21256">
	**5V BabyBuck Regulator**<br>
	**SKU:** COM-21256

	---

	<figure markdown>
	Product image
	</figure></a>

	Unlike its sibling, the [BabyBuck](https://www.sparkfun.com/products/21256) is a minimalistic board that sacrifices the connection options for space. Don't worry, though, because the PTH pins are still available to connect the input and output power. All of this snuggled up in a low-profile, .63" x .52" board.

	<center>
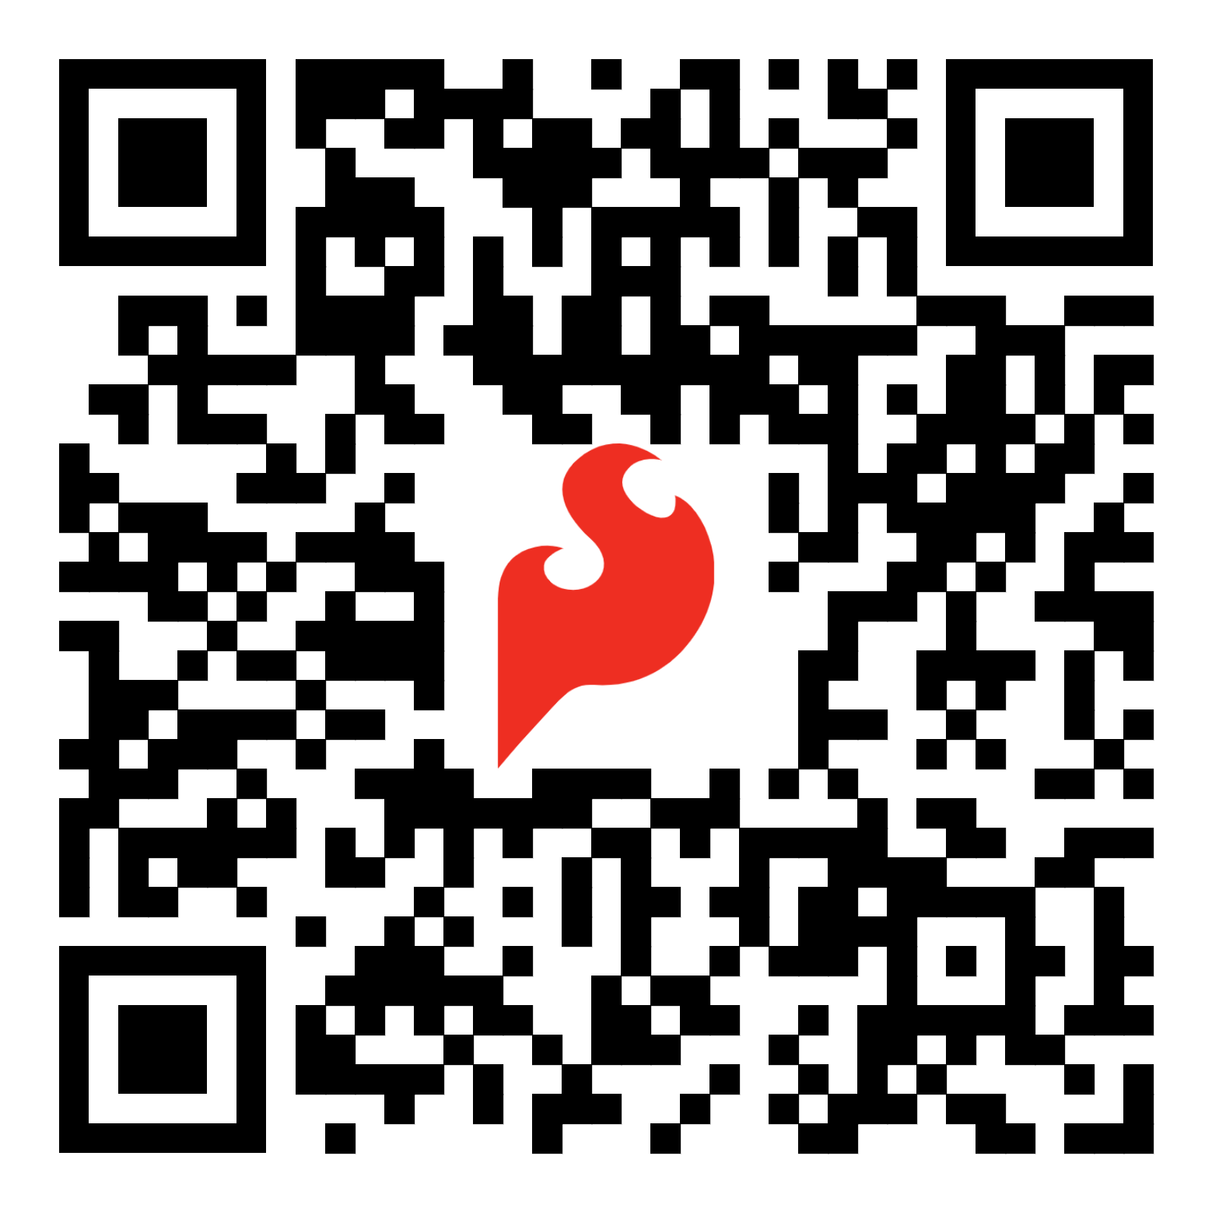
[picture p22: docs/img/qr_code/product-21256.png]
QR code to product page
	[&nbsp;&nbsp;&nbsp;Purchase from SparkFun :fontawesome-solid-cart-plus:{ .heart }](https://www.sparkfun.com/products/21256){ .md-button .md-button--primary }
	</center>

</section>

## :fontawesome-solid-list-check:&nbsp;Required Materials
To get started, users will need a few items. Now some users may already have a few of these items, feel free to modify your cart accordingly.

* [SparkFun Buck Regulator Breakout - 5V (AP63357DV)](https://www.sparkfun.com/products/21255)
* [Heat Sink](https://www.sparkfun.com/products/18704 "Thermal tape is included") - Used to help dissipate excess heat
    * [Thermal Tape](https://www.sparkfun.com/products/17054) - To attach a heat sink to the board
* [Power Supply](https://www.sparkfun.com/categories/307 "Click here for a full selection of our available power supplies")
* Soldering Tools (1)
{ .annotate }

	1.	Check out the beginner tool kit below; otherwise, click here for a full selection of our available [soldering tools](https://www.sparkfun.com/categories/49).

* [Hookup Wire](https://www.sparkfun.com/categories/141 "Click here for a full selection of our available wires") - May be used to connect the external power or power output
* [Headers](https://www.sparkfun.com/categories/381 "Click here for a full selection of our available headers")  - May be used to connect the external power or power output
* [DC Barrel Jack Adapter](https://www.sparkfun.com/products/119) - *(Optional - Not necessary for the BabyBuck Regulator)*
* [Small Flathead Screw Driver](https://www.sparkfun.com/categories/376 "Click here for a full selection of our available screwdrivers")  - *(Optional - Not necessary for the BabyBuck Regulator)*

<table class="pdf">
	<tr>
		<td>
			<a href="https://www.sparkfun.com/products/21256">
				<center>SparkFun Buck Regulator Breakout - 5V (AP63357DV)
				</center>
				<h3 class="title">SparkFun BabyBuck Regulator Breakout - 5V (AP63357DV)</h3>
			</a>
			COM-21256
		</td>
		<td>
			<a href="https://www.sparkfun.com/products/21255">
				<center>SparkFun Buck Regulator Breakout - 5V (AP63357DV)
				</center>
				<h3 class="title">SparkFun Buck Regulator Breakout - 5V (AP63357DV)</h3>
			</a>
			COM-21255
		</td>
		<td>
			<a href="https://www.sparkfun.com/products/18704">
				<center>
				Product image
				</center>
				<h3 class="title">Heatsink - 13.20 x 12.10 mm (Copper)</h3>
			</a>
			PRT-18704
		</td>
		<td>
			<a href="https://www.sparkfun.com/products/17054">
				<center>
				Product image
				</center>
				<h3 class="title">Thermal Tape 4x4" Square</h3>
			</a>
			PRT-17054
		</td>
	</tr>
	<tr>
		<td>
			<a href="https://www.sparkfun.com/products/14681">
				<center>
				Product image
				</center>
				<h3 class="title">SparkFun Beginner Tool Kit</h3>
			</a>
			TOL-14681
		</td>
		<td>
			<a href="https://www.sparkfun.com/products/11367">
				<center>
				Product image
				</center>
				<h3 class="title">Hook-Up Wire - Assortment (Solid Core, 22 AWG)</h3>
			</a>
			PRT-11367
		</td>
		<td>
			<a href="https://www.sparkfun.com/products/116">
				<center>
				Product image
				</center>
				<h3 class="title">Break Away Headers - Straight</h3>
			</a>
			PRT-00116
		</td>
		<td>
			<a href="https://www.sparkfun.com/products/119">
				<center>
				Product image
				</center>
				<h3 class="title">DC Barrel Power Jack/Connector</h3>
			</a>
			PRT-00119
		</td>
	</tr>
    <tr>
		<td>
			<a href="https://www.sparkfun.com/products/12891">
				<center>
				Product image
				</center>
				<h3 class="title">Pocket Screwdriver Set</h3>
			</a>
			TOL-12891
		</td>
    </tr>
</table>

<div class="pdf" markdown>
!!! note "New to soldering?"
	Check out our [Through-Hole Soldering Tutorial](https://learn.sparkfun.com/tutorials/5) for a quick introduction!
	<p align="center">
		<a href="https://learn.sparkfun.com/tutorials/5">How to Solder: Through-Hole Soldering<br>
		Tutorial's thumbnail</a>
	</p>
</div>

<div class="grid cards hide col-4" markdown>

-   <a href="https://www.sparkfun.com/products/21255">
	**Buck Regulator Breakout - 5V (AP63357DV)**<br>
	COM-21255

	---

	<figure markdown>
	SparkFun Buck Regulator Breakout - 5V (AP63357DV)
	</figure></a>

-   <a href="https://www.sparkfun.com/products/21256">
	**BabyBuck Regulator Breakout - 5V (AP63357DV)**<br>
	COM-21256

	---

	<figure markdown>
	SparkFun BabyBuck Regulator Breakout - 5V (AP63357DV)
	</figure></a>

-   <a href="https://www.sparkfun.com/products/18704">
	**Heatsink - 13.20 x 12.10 mm (Copper)**<br>
	PRT-18704

	---

	<figure markdown>
	Product image
	</figure></a>

	!!! tip "Fits both boards"
	!!! info "Thermal tape is included"

-   <a href="https://www.sparkfun.com/products/17054">
	**Thermal Tape 4x4" Square**<br>
	PRT-17054

	---

	<figure markdown>
	Product image
	</figure></a>

-   <a href="https://www.sparkfun.com/products/14681">
	**SparkFun Beginner Tool Kit**<br>
	TOL-14681

	---

	<figure markdown>
	Product image
	</figure></a>

	??? note "New to soldering?"
		Check out our [Through-Hole Soldering Tutorial](https://learn.sparkfun.com/tutorials/5) for a quick introduction!
		<p align="center">
			<a href="https://learn.sparkfun.com/tutorials/5">How to Solder: Through-Hole Soldering<br>
			Tutorial's thumbnail</a>
		</p>

-   <a href="https://www.sparkfun.com/products/11367">
	**Hook-Up Wire - Assortment (Solid Core, 22 AWG)**<br>
	PRT-11367

	---

	<figure markdown>
	Product image
	</figure>
	</a>

-   <a href="https://www.sparkfun.com/products/116">
	**Break Away Headers - Straight**<br>
	PRT-00116

	---

	<figure markdown>
	Product image
	</figure>
	</a>

-   <a href="https://www.sparkfun.com/products/119">
	**DC Barrel Power Jack/Connector**<br>
	PRT-00119

	---

	<figure markdown>
	Product image
	</figure>
	</a>

-   <a href="https://www.sparkfun.com/products/12891">
	**Pocket Screwdriver Set**<br>
	TOL-12891

	---

	<figure markdown>
	Product image
	</figure>
	</a>

</div>

??? note "Jumper Modification"
	!!! tip "New to jumper pads?"
		Check out our [Jumper Pads and PCB Traces Tutorial](https://learn.sparkfun.com/tutorials/664) for a quick introduction!
		<p align="center">
			<a href="https://learn.sparkfun.com/tutorials/664">How to Work with Jumper Pads and PCB Traces<br>
			Tutorial's thumbnail</a>
		</p>

	To modify the [jumper](hardware_overview/#jumper), users will need [soldering equipment](https://www.sparkfun.com/categories/49) and/or a [hobby knife](https://www.sparkfun.com/categories/379).

	<table class="pdf">
		<tr>
			<td>
				<a href="https://www.sparkfun.com/products/9325">
					<center>
					Product image
					</center>
					<h3 class="title">Solder Lead Free - 100-gram Spool</h3>
				</a>
				TOL-09325
			</td>
			<td>
				<a href="https://www.sparkfun.com/products/14228">
					<center>
					Product image
					</center>
					<h3 class="title">Weller WLC100 Soldering Station</h3>
				</a>
				TOL-14228
			</td>
			<td>
				<a href="https://www.sparkfun.com/products/14579">
					<center>
					Product image
					</center>
					<h3 class="title">Chip Quik No-Clean Flux Pen - 10mL</h3>
				</a>
				TOL-14579
			</td>
			<td>
				<a href="https://www.sparkfun.com/products/9200">
					<center>
					Product image
					</center>
					<h3 class="title">Hobby Knife</h3>
				</a>
				TOL-09200
			</td>
		</tr>
	</table>

	<div class="grid cards hide col-4" markdown>

	-   <a href="https://www.sparkfun.com/products/9325">
		**Solder Lead Free - 100-gram Spool**<br>
		TOL-09325

		---

		<figure markdown>
		Product image
		</figure></a>

	-   <a href="https://www.sparkfun.com/products/14228">**Weller WLC100 Soldering Station**<br>
		TOL-14228

		---
		
		<figure markdown>
		Product image
		</figure></a>

	-   <a href="https://www.sparkfun.com/products/14579">
		**Chip Quik No-Clean Flux Pen - 10mL**<br>
		TOL-14579

		---

		<figure markdown>
		Product image
		</figure></a>

	-   <a href="https://www.sparkfun.com/products/9200">
		**Hobby Knife**<br>
		TOL-09200

		---

		<figure markdown>
		Product image
		</figure>
		</a>
	</div>

## :material-bookshelf:&nbsp;Suggested Reading

Below, are a few tutorials that may help users familiarize themselves with various aspects of this product:

<table class="pdf">
	<tr>
		<td align="center">
			<a href="https://learn.sparkfun.com/tutorials/72">Electric Power<br>
			</a>
		</td>
		<td align="center">
			<a href="https://learn.sparkfun.com/tutorials/18">Connector Basics<br>
			</a>
		</td>
        <td align="center">
			<a href="https://learn.sparkfun.com/tutorials/41">Working with Wire<br>
			</a>
		</td>
		<td align="center">
			<a href="https://learn.sparkfun.com/tutorials/36">How to Power a Project<br>
			</a>
		</td>
    </tr>
	<tr>
		<td align="center">
			<a href="https://learn.sparkfun.com/tutorials/26">What is a Circuit?<br>
			</a>
		</td>
		<td align="center">
			<a href="https://learn.sparkfun.com/tutorials/115">Alternating Current (AC) vs. Direct Current (DC)<br>
			</a>
		</td>
        <td align="center">
			<a href="https://learn.sparkfun.com/tutorials/75">Polarity<br>
			</a>
		</td>
		<td align="center">
			<a href="https://learn.sparkfun.com/tutorials/62">Logic Levels<br>
			</a>
		</td>
	</tr>
    <tr>
		<td align="center">
			<a href="https://learn.sparkfun.com/tutorials/1890">Buck Regulator Hookup Guide<br>
			</a>
		</td>
		<td align="center">
			<a href="https://docs.sparkfun.com/SparkFun_Buck_Regulator_AP3429A">AP3429A - 1.8/3.3V Buck Regulator Hookup Guide<br>
			</a>
		</td>
		<td align="center">
			<a href="https://learn.sparkfun.com/tutorials/5">How to Solder: Through-Hole Soldering<br>
			Tutorial's thumbnail</a>
		</td>
		<td align="center">
			<a href="https://learn.sparkfun.com/tutorials/664">How to Work with Jumper Pads and PCB Traces<br>
			Tutorial's thumbnail</a>
		</td>
	</tr>
</table>

<div class="grid cards hide col-4" markdown align="center">

-   <a href="https://learn.sparkfun.com/tutorials/72">
	**Electric Power**

	---
	
	<figure markdown>
	Electric Power
	</figure></a>

-   <a href="https://learn.sparkfun.com/tutorials/18">
	**Connector Basics**

	---
	
	<figure markdown>
	Connector Basics
	</figure></a>

-   <a href="https://learn.sparkfun.com/tutorials/41">
	**Working with Wire**

	---
	
	<figure markdown>
	Working with Wire
	</figure></a>

-   <a href="https://learn.sparkfun.com/tutorials/36">
	**How to Power a Project**

	---
	
	<figure markdown>
	IHow to Power a Project
	</figure></a>

-   <a href="https://learn.sparkfun.com/tutorials/26">
	**What is a Circuit?**

	---
	
	<figure markdown>
	What is a Circuit?
	</figure></a>

-   <a href="https://learn.sparkfun.com/tutorials/115">
	**Alternating Current (AC) vs. Direct Current (DC)**

	---
	
	<figure markdown>
	Alternating Current (AC) vs. Direct Current (DC)
	</figure></a>

-   <a href="https://learn.sparkfun.com/tutorials/75">
	**Polarity**

	---
	
	<figure markdown>
	Polarity
	</figure></a>

-   <a href="https://learn.sparkfun.com/tutorials/62">
	**Logic Levels**

	---
	
	<figure markdown>
	Logic Levels
	</figure></a>

-   <a href="https://learn.sparkfun.com/tutorials/1890">
	**Buck Regulator Hookup Guide**

	---

	<figure markdown>
	Buck Regulator Hookup Guide
	</figure></a>

-   <a href="https://docs.sparkfun.com/SparkFun_Buck_Regulator_AP3429A">
	**AP3429A - 1.8/3.3V Buck Regulator Hookup Guide**

	---

	<figure markdown>
	AP3429A Buck Regulators Hookup Guide
	</figure></a>

-   <a href="https://learn.sparkfun.com/tutorials/5">
	**How to Solder: Through-Hole Soldering**

	---
	
	<figure markdown>
	How to Solder: Through-Hole Soldering
	</figure></a>

-   <a href="https://learn.sparkfun.com/tutorials/664">
	**How to Work with Jumper Pads and PCB Traces**

	---
	
	<figure markdown>
	How to Work with Jumper Pads and PCB Traces
	</figure></a>

</div>

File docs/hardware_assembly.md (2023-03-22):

---
icon: material/tools
---

!!! hot "**Danger:** These boards can get <span style="color: #ff1744;">extremely **HOT** :material-thermometer-alert:</span>"
	
	Please handle these boards with the utmost caution. Users can easily burn themselves when the board outputs anything over 2A. 

## :material-soldering-iron:&nbsp;Headers

??? note "New to soldering?"
	If you have never soldered before or need a quick refresher, check out our [How to Solder: Through-Hole Soldering](https://learn.sparkfun.com/tutorials/how-to-solder-through-hole-soldering) guide.
	<p align="center">
		<a href="https://learn.sparkfun.com/tutorials/5">How to Solder: Through-Hole Soldering<br>
		</a>
	</p>

The pins for the SparkFun **5V** Buck Regulator Breakout boards are broken out to 0.1"-spaced pins on the outer edges of the board. When selecting headers, be sure you are aware of the functionality and board orientation required.

<center>
<table class="pdf">
	<tr>
		<td align="center">
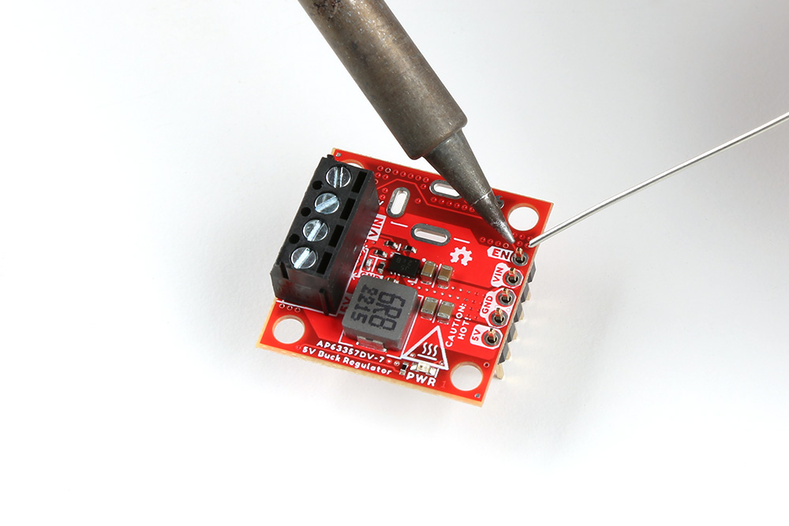
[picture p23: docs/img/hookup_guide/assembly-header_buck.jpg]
			<br>
			<i>Soldering headers to the 5V Buck Regulator (AP63357DV).</i>
		</td>
		<td align="center">
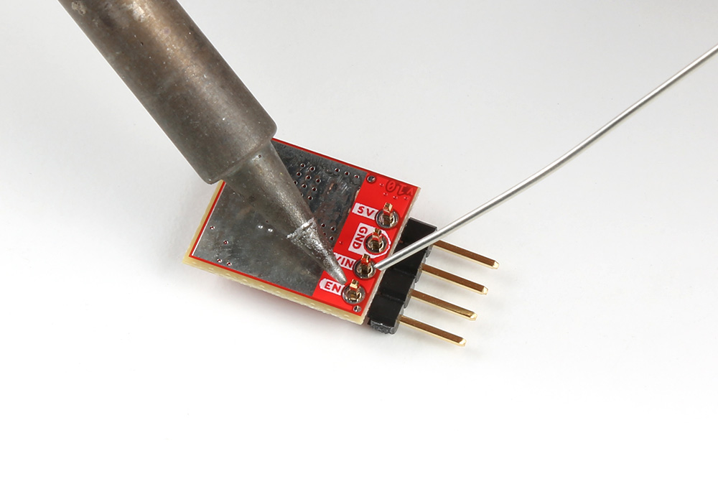
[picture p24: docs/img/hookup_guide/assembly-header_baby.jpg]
			<br>
			<i>Soldering headers to the 5V Baby Buck Regulator (AP63357DV).</i>
		</td>
	<tr>
</table>
</center>

<div class="grid cards hide" markdown>

-   <figure markdown>
	
	<figcaption markdown>
	Soldering headers to the 5V Buck Regulator (AP63357DV).
	</figcaption>
	</figure>

	??? tip "Bypass the UVLO"
		!!! info "Default Configuration"
			On our boards, the `EN` pin is used to configure the [UVLO](../hardware_overview/#undervoltage-lockout "Undervoltage Lockout") threshold. Therefore, the power output from the board is enabled by default.

		On the 5V Buck Regulator, users can short the [`VIN`](../hardware_overview/#power "Input Voltage") and [`EN`](../hardware_overview/#power-control "Enable Pin") pins with a [2-pin jumper](https://www.sparkfun.com/products/9044). This will allow users to bypass the [UVLO](../hardware_overview/#undervoltage-lockout "Undervoltage Lockout") threshold and force the power output to be enabled.

		<figure markdown>
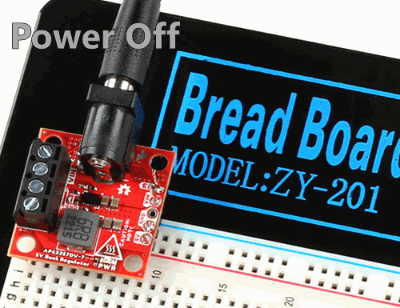
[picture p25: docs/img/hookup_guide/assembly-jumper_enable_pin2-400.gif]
		
		<figcaption markdown>
		Headers soldered to the `EN` and `VIN` pins on the 5V Buck Regulator and bypassing the UVLO.
		</figcaption>
		</figure>

		With the 6V undervoltage lockout bypassed, a lower input voltage can be utilized. However, it should be noted that because this is a step-down converter, the output voltage will be limited to the voltage of the power supply and may not be 5V.

-   <figure markdown>
	
	<figcaption markdown>
	Soldering headers to the 5V Baby Buck Regulator (AP63357DV).
	</figcaption>
	</figure>

	??? tip "Breadboard Use"
		When selecting headers for the BabyBuck regulator, the [right-angle headers](https://www.sparkfun.com/products/553) work great with breadboards.

		<figure markdown>
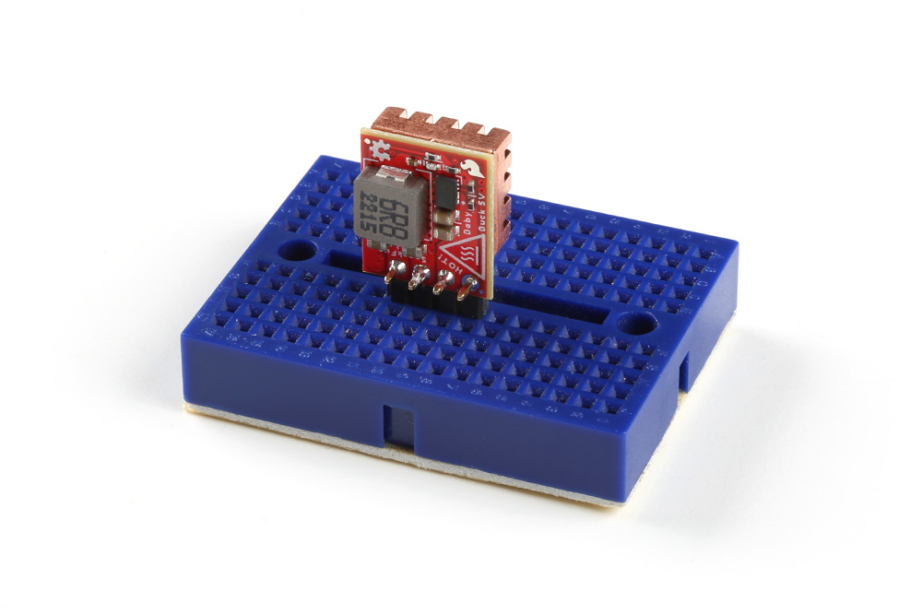
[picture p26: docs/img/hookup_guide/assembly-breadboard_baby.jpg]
		
		<figcaption markdown>
		The 5V Baby Buck Regulator with right-angle headers and a heat sink on a breadboard.
		</figcaption>
		</figure>

</div>

## :material-soldering-iron:&nbsp;Hookup Wire
??? note "New to soldering?"
	If you have never soldered before or need a quick refresher, check out our [How to Solder: Through-Hole Soldering](https://learn.sparkfun.com/tutorials/how-to-solder-through-hole-soldering) guide.
	<p align="center">
		<a href="https://learn.sparkfun.com/tutorials/5">How to Solder: Through-Hole Soldering<br>
		</a>
	</p>

Users can also solder their wire connections directly to the pins of the SparkFun **5V** Buck Regulator Breakout boards. When planning out the connections, be sure you are aware of the functionality required.

!!! danger
	With higher current applications, users should ensure the wires can handle the current load. *(i.e. A 32AWG wire probably won't be able to handle 3.5A)*

<center>
<table class="pdf">
	<tr>
		<td align="center">
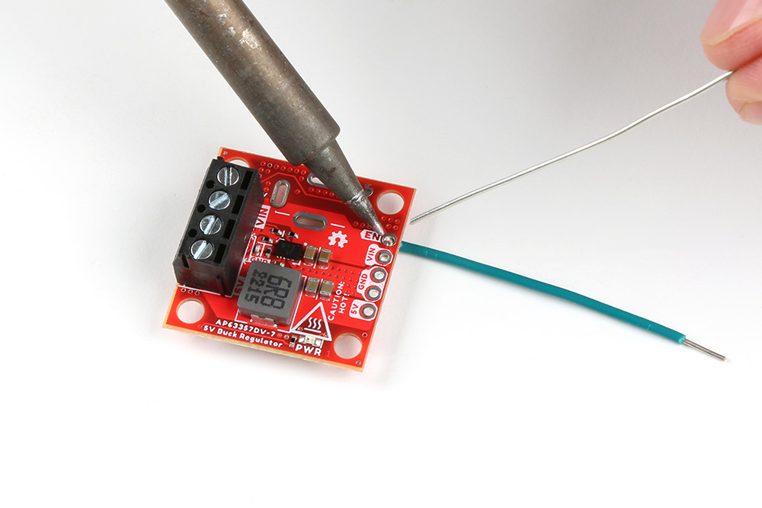
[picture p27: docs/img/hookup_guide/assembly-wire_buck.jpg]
			<br>
			<i>Soldering wires to the 5V Buck Regulator (AP63357DV).</i>
		</td>
		<td align="center">
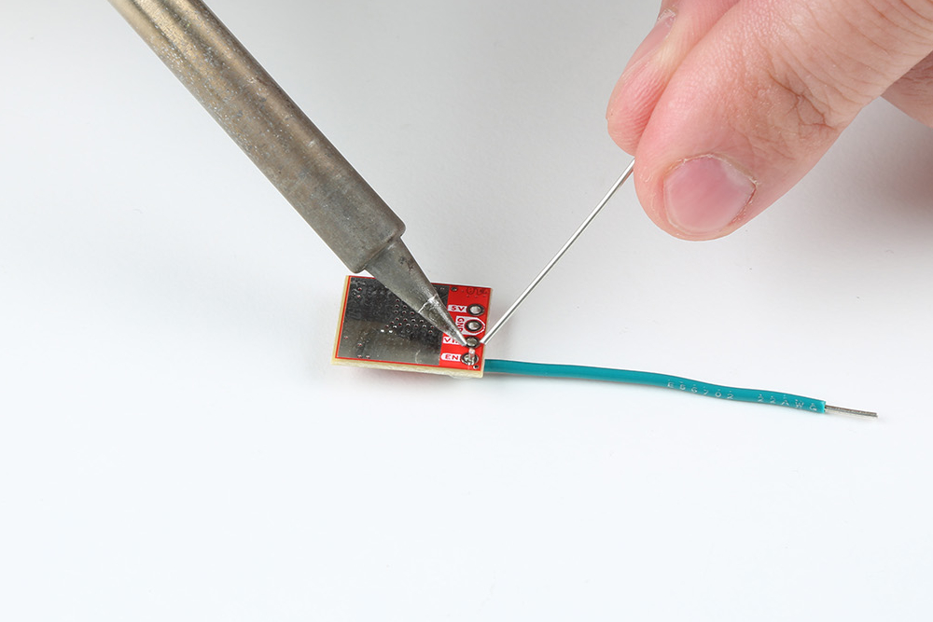
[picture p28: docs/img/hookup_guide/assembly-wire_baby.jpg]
			<br>
			<i>Soldering wires to the 5V Baby Buck Regulator (AP63357DV).</i>
		</td>
	<tr>
</table>
</center>

<div class="grid cards hide" markdown>

-   <figure markdown>
	
	<figcaption markdown>
	Soldering wires to the 5V Buck Regulator (AP63357DV).
	</figcaption>
	</figure>

-   <figure markdown>
	
	<figcaption markdown>
	Soldering wires to the 5V Baby Buck Regulator (AP63357DV).
	</figcaption>
	</figure>

</div>

## Alternative Connections
!!! info  "Buck Regulator *(only)*"
	!!! warning "The following features are only available on the Buck Regulator and are <u>not</u> available on BabyBuck Regulator."

	=== ":material-soldering-iron:&nbsp;Barrel Jack PTH"
		??? note "New to soldering?"
			If you have never soldered before or need a quick refresher, check out our [How to Solder: Through-Hole Soldering](https://learn.sparkfun.com/tutorials/how-to-solder-through-hole-soldering) guide.
			<p align="center">
				<a href="https://learn.sparkfun.com/tutorials/5">How to Solder: Through-Hole Soldering<br>
				</a>
			</p>

		To add a [barrel jack connector](https://www.sparkfun.com/products/119) to their board, users will need to solder it to the provided plated through hole slots.

		<figure markdown>
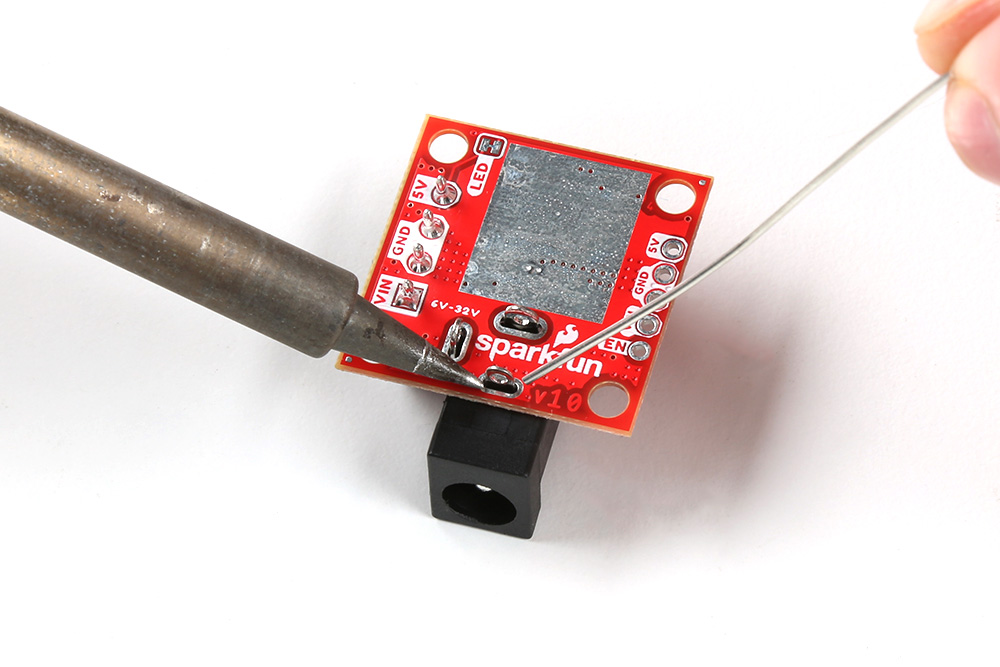
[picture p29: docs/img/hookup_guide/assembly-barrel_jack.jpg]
		
		<figcaption markdown>Soldering a [barrel jack connector](https://www.sparkfun.com/products/119) onto the 5V Buck Regulator.</figcaption>
		</figure>

	=== "Screw Terminals"
		A screw terminal is a great non-permanent solution, to connect the board. To use the screw terminals, simply insert the correct wires into the screw terminal opening and tighten the screw with a small flathead screwdriver for a firm connection.

		<figure markdown>
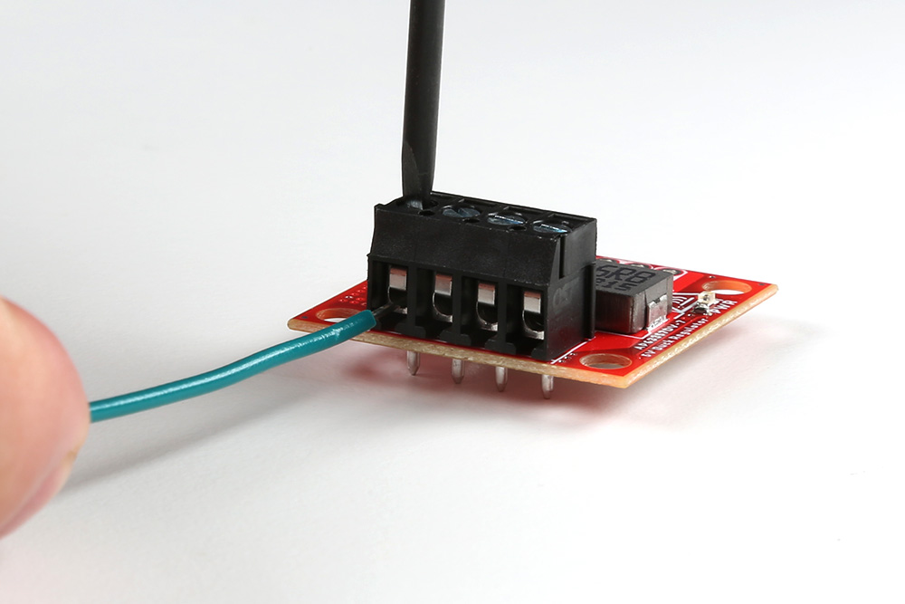
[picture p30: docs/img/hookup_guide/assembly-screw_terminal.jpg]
		
		<figcaption markdown>Connecting a wire to the 5V Buck Regulator's' screw terminal.</figcaption>
		</figure>

## Heat Sink
!!! tip
    With larger heat sinks, we recommend a test fit and attaching it last to avoid conflicts with other parts of the board. For example, the heat sink could block the PTH pins/slots or access to the jumper pad.

To attach a [heat sink](https://www.sparkfun.com/products/18704) to the board, users will also need a piece of [thermal tape](https://www.sparkfun.com/products/17054). We recommend the following procedure:

1. Cut out a piece of [thermal tape](https://www.sparkfun.com/products/17054) to fit the bottom of the [heat sink](https://www.sparkfun.com/products/18704).
	
	!!! tip
		Covering the entire bottom of the heat sink can insulate the electrical contacts on the board from shorting.

    * For a perfect fit, users can place the heat sink over the tape and trace the outline to cut with scissors.
    * For a perfect fit, users can also place the heat sink over the tape and cut the outline with a [hobby knife](https://www.sparkfun.com/products/9200).

2. Place the piece of thermal tape on the bottom of the heat sink.

	!!! tip
		We recommend peeling off just one side of the backing sheet or [release liner](https://en.wikipedia.org/wiki/Release_liner) to place the thermal tape on the heat sink. Users can then peel the other side off when they are ready to place the heat sink on their board.
	
3. Attach the heat sink to the board.
    * Make sure to make any jumper modifications and/or solder any connections before placing the heat sink on the board.
    * Make sure to avoid any electrical contact with the sides of the heat sink.

<center>
<table class="pdf">
	<tr>
		<td align="center">
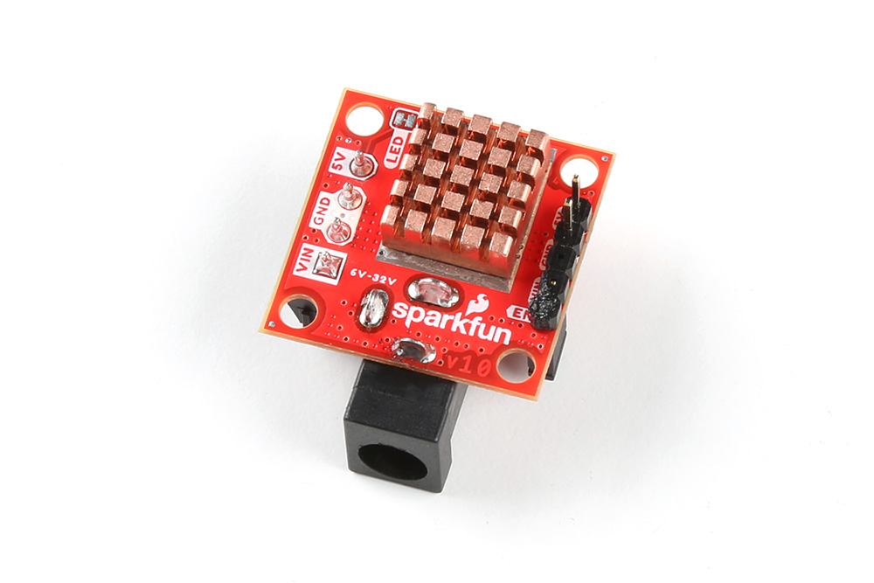
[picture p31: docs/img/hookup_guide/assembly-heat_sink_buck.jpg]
			<br>
			<i><a href="https://www.sparkfun.com/products/18704">Heat sink</a> attached to the 5V Buck Regulator (AP63357DV).</i>
		</td>
		<td align="center">
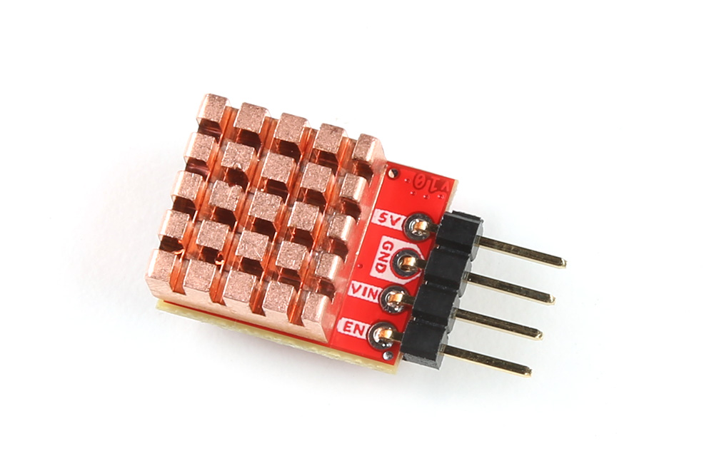
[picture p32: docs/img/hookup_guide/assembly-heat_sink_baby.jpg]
			<br>
			<i><a href="https://www.sparkfun.com/products/18704">Heat sink</a> attached to the 5V Baby Buck Regulator (AP63357DV).</i>
		</td>
	<tr>
</table>
</center>

<div class="grid cards hide" markdown>

-   <figure markdown>
	
	<figcaption markdown>
	[Heat sink](https://www.sparkfun.com/products/18704) attached to the 5V Buck Regulator (AP63357DV).
	</figcaption>
	</figure>

-   <figure markdown>
	
	<figcaption markdown>
	[Heat sink](https://www.sparkfun.com/products/18704) attached to the 5V Baby Buck Regulator (AP63357DV).
	</figcaption>
	</figure>

</div>

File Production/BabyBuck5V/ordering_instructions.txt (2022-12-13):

panel size, 145x96mm
PCB thickness, 0.8mm
number of layers, 4
soldermask color, Red
silkscreen color, White
oz copper, 1oz
finish, HASL lead free
stencils, top
pcs per panel, 48
min trace width, 0.2032mm / 0.0080in
min drill size, 0.3810mm / 0.0150in
filename to layer stackup 1/2/3/4: GTL, GL2, GL3, GBL

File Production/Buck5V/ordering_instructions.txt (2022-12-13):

panel size, 169x117mm
PCB thickness, 0.8mm
number of layers, 4
soldermask color, Red
silkscreen color, White
oz copper, 1oz
finish, HASL lead free
stencils, top
pcs per panel, 24
min trace width, 0.2032mm / 0.0080in
min drill size, 0.3500mm / 0.0138in
filename to layer stackup 1/2/3/4: GTL, GL2, GL3, GBL

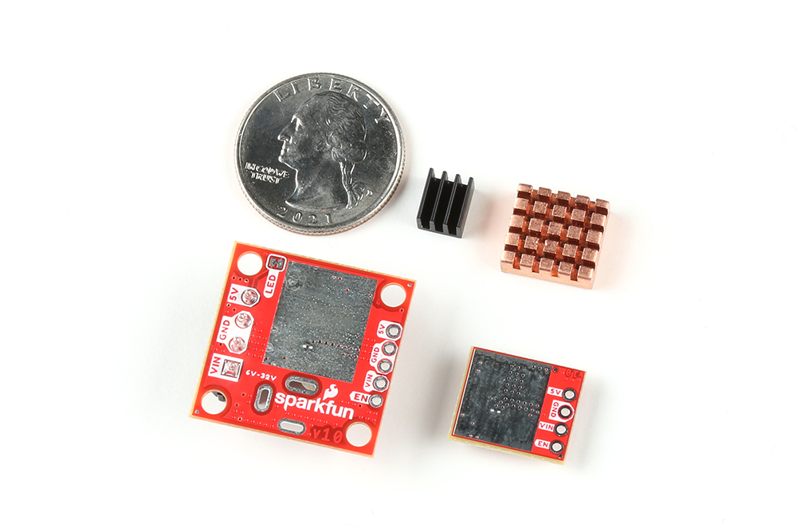
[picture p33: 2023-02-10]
docs/img/hookup_guide/assembly-heat_sink.jpg

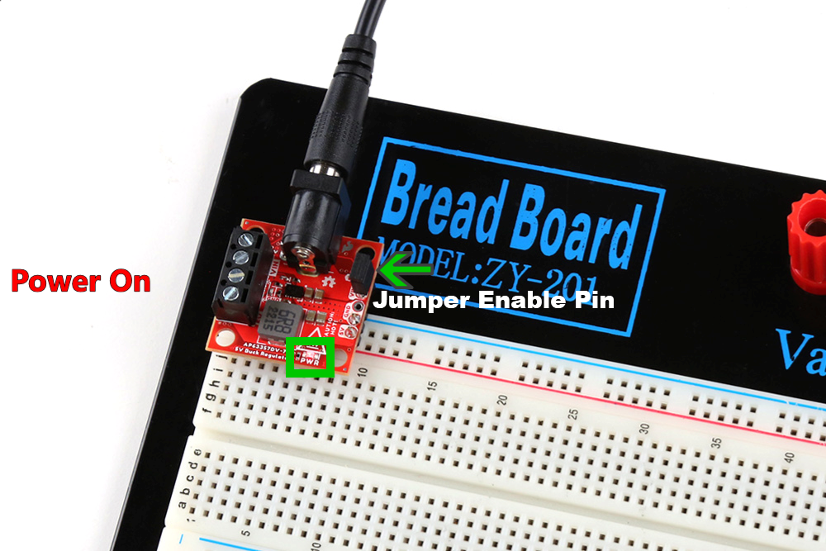
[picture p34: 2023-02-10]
docs/img/hookup_guide/assembly-jumper_on.png

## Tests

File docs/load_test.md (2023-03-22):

---
icon: material/speedometer
---

For users who would like to test their buck regulators, this page demonstrates a simple load test on the [5V buck regulator board](https://www.sparkfun.com/products/21255).

!!! note
	Users who wish to test the maximum parameters of their board will need to consider the thermal and current limitations of the hardware. At minimum:
	
	* A professional/benchtop DC electric load tester should be used instead of the [variable load kit](https://www.sparkfun.com/products/14449).
	* Active cooling should be provided to the buck regulator. 

## Required Hardware
To test the buck regulator boards, users will need the following hardware:

* DC Electric Load Tester
	* We are using the [SparkFun Variable Load Kit](https://www.sparkfun.com/products/14449)
* Power Supply
    * Use a benchtop-style power supply where you can configure the output voltage and see the current draw when loaded.
	* We are using the [80W DC Power Supply](https://www.sparkfun.com/products/retired/9291) *(retired product)*

<table class="pdf">
	<tr>
		<td>
			<a href="https://www.sparkfun.com/products/retired/9291">
				
				<h3 class="title">Power Supply - 80W DC Switching Mode</h3>
			</a>
			TOL-09291
		</td>
		<td>
			<a href="https://www.sparkfun.com/products/14449">
				
				<h3 class="title">SparkFun Variable Load Kit</h3>
			</a>
			KIT-14449
		</td>
    </tr>
</table>

<div class="grid cards hide" markdown>

-   <a href="https://www.sparkfun.com/products/retired/9291">**Power Supply - 80W DC Switching Mode**<br>
	TOL-09291

	---

	<figure markdown>
	
	</figure></a>

-   <a href="https://www.sparkfun.com/products/14449">**SparkFun Variable Load Kit**<br>
	KIT-14449

	---

	<figure markdown>
	
	</figure>
	</a>

</div>

## Hardware Setup
For this test, the hardware was setup up as follows:

* Power was supplied to the buck regulator through the soldered barrel jack.
* The output power from the buck regulator was connected to the variable load kit, through the screw terminal.
* Power was enabled using a jumper on the headers, soldered to the `VIN` and `EN` PTH pins.
* No heat sink was attached to the buck regulator.

## Test
To perform the test, the power supply was set to provide 6.08V at up to 4A. Meanwhile, the SparkFun variable load kit was configured to draw 1A(1).
{ .annotate }

1. For current draws over 1.5A, users should include a heat sink; and active cooling for loads over 2.5A.

<figure markdown>
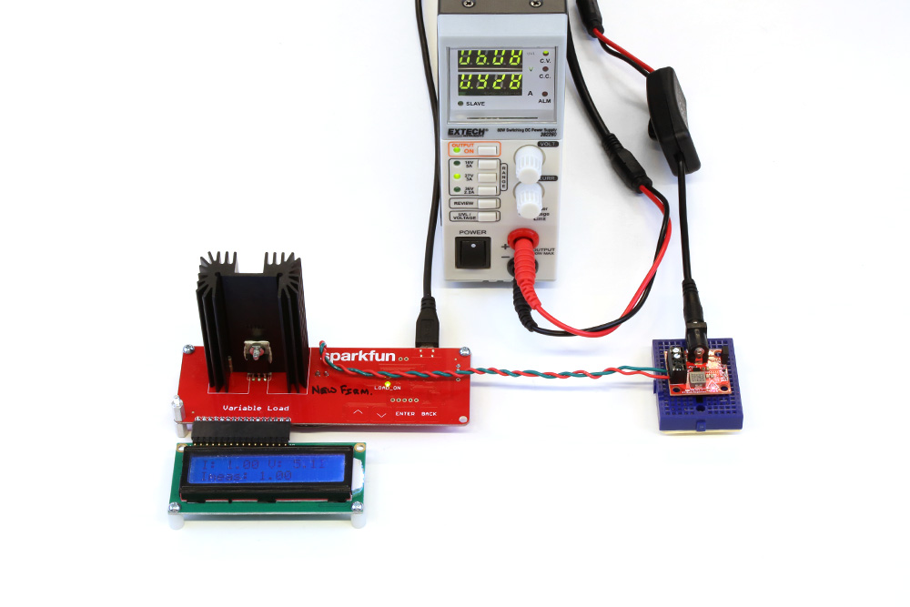
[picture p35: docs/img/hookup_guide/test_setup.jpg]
<br>
<figcaption markdown>Setup for a basic load test on the 5V Buck Regulator (AP63357DV).</figcaption>
</figure>

Although it is a little hard to see in the picture, the power supply is providing 6.08V with a 928mA current draw to the buck regulator. The variable load kit is drawing 1A with the 5.11V output voltage from the buck regulator.

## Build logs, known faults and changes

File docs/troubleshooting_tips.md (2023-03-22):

---
icon: sfe-logo
---

!!! hot "**Danger:** These boards can get <span style="color: #ff1744;">extremely **HOT** :material-thermometer-alert:</span>"
	
	Please handle these boards with the utmost caution. Users can easily burn themselves when the board outputs anything over 2A. 

!!! warning "Need Help?"
    If you need technical assistance or more information on a product that is not working as you expected, we recommend heading on over to the [SparkFun Technical Assistance](https://www.sparkfun.com/technical_assistanc) page for some initial troubleshooting.

    <center>
    [SparkFun Technical Assistance Page](https://www.sparkfun.com/technical_assistance){ .md-button .md-button--primary }
    </center>
    
    If you can't find what you need there, the [SparkFun Forums](https://forum.sparkfun.com/index.php) is a great place to search product forums and ask questions.
    
    !!! info "Account Registration Required"
        If this is your first visit to our forum, you'll need to create a [Forum Account](https://forum.sparkfun.com/ucp.php?mode=register) to post questions.

## Maximum Current
While the AP6337 is rated up to 3.5A, users may experience thermal limitations towards that maximum.

* Users should reasonably expect to be able to place a maximum 3A load on the boards when using a heat sink and active cooling. 
* At the peak load of 3.5A, users will need sufficient cooling to prevent the IC's [thermal shutdown](#thermal-characteristics "The AP63357 has a 170&deg;C (338&deg;F) thermal shutdown temperature.").

!!! note
    * Without a heat sink or active cooling, we recommend users not load the boards with more than 1.5A.
    * With a heat sink, we have found users can expect to draw up to 2.5A
		
## Connecting Batteries
For lower current applications, users can connect a battery as the power source. However, we would only recommend using the 9V [battery products](https://www.sparkfun.com/categories/54) from our catalog.

!!! warning
    Other products such as the [coin cell battery holder](https://www.sparkfun.com/products/12618), [2x18650 battery holder](https://www.sparkfun.com/products/12900), and any of the 4xAA battery holders could technically work. However, we would advise against them for the following reasons:

    * For the [coin cell battery holder](https://www.sparkfun.com/products/12618) and any of the 4xAA battery holders (using [alkaline batteries](https://www.sparkfun.com/products/15201)), users wouldn't be able to use the full capacity of their batteries.
        * The initial total voltage of the batteries would typically be above the nominal 6V and potentially work. However, as the batteries discharged they would eventually cross the 6V UVLO threshold of the buck converter well before they were completely depleted.
        * In short, users would maybe be using ~85% of their battery's total capacity at best.
    * The [18650 lithium-ion batteries](https://www.sparkfun.com/products/12895) in our catalog don't include a battery protection circuit. With two batteries in series, they would bypass their cutoff voltage (~3.2V). This would permanently damage the batteries and render them useless.

### Automobile Batteries
While users could connect a 12V car, motorcycle, marine, etc. battery for higher current applications, users may find this [5V/3A Buck Converter](https://www.sparkfun.com/products/18375) easier to mount and connect.

<div class="grid cards" markdown>

-   <a href="https://www.sparkfun.com/products/18375">**Buck Converter - 8-20V to 5V/3A**<br>
	COM-18375

	---

	<figure markdown>
	Buck Converter - 8-20V to 5V/3A
	</figure></a>

</div>

## Bypass the UVLO
!!! info "Default Configuration"
    On our boards, the `EN` pin is used to configure the [UVLO](../hardware_overview/#undervoltage-lockout "Undervoltage Lockout") threshold. Therefore, the power output from the board is enabled by default.

On the 5V Buck Regulator, users can short/jumper the [`VIN`](../hardware_overview/#power "Input Voltage") and [`EN`](../hardware_overview/#power-control "Enable Pin") pins. This will bypass the 6V undervoltage lockout setting and allow users to provide a lower input voltage. However, it should be noted that because this is a step-down converter, the output voltage will then be limited to the voltage of the power supply and may not be 5V *(if the input voltage ≤5V)*.

<figure markdown>

<figcaption markdown>
Jumpering the `EN` and `VIN` pins on the 5V Buck Regulator to bypass the UVLO to use an input voltage below 6V.
</figcaption>
</figure>

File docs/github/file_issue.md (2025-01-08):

# Did we make a mistake?

Spot something wrong? Please let us know. 

<!-- Technical Assistance Box -->
!!! warning "Need Help?"
    If you need technical assistance or more information on a product that is not working as you expected, we recommend heading on over to the [SparkFun Technical Assistance](https://www.sparkfun.com/technical_assistance) page for some initial troubleshooting. This **Submit Issues** page is not where users should seek assistance.

    <center>
    [SparkFun Technical Assistance Page](https://www.sparkfun.com/technical_assistance){ .md-button .md-button--primary }
    </center>
    
    If you can't find what you need there, the [SparkFun Forums](https://forum.sparkfun.com/index.php) is a great place to search the product forums and ask questions.
    
    !!! info "Account Registration Required"
        For your first visit to our forum, you'll need to create a [Forum Account](https://forum.sparkfun.com/ucp.php?mode=register) to post questions.

## Discrepancies in the Documentation

All of our documentation can be modified by you! Please help us make it better.

* The documentation files for these pages are contained in the [`docs` folder](https://github.com/sparkfun/SparkFun_Buck_Regulator_AP63357DV-7/tree/main/docs) of the [SparkFun Buck Regulator AP63357DV-7 repository](https://github.com/sparkfun/SparkFun_Buck_Regulator_AP63357DV-7).

### 🔍 Spot something wrong?
If a section of the documentation is incorrect, please [open an issue](https://github.com/sparkfun/SparkFun_Buck_Regulator_AP63357DV-7/issues) and let us know.

### Do you have a suggested correction?
1. With a GitHub account, [fork this repository](https://github.com/sparkfun/SparkFun_Buck_Regulator_AP63357DV-7/fork).
2. Add your correction(s) or improvement(s) to the markdown file(s)
3. File a pull request with your changes, and enjoy making the ~~words~~ ~~worlds~~ world a better place.
	* Once received, the documentation specialist will automatically be notified.
	* We will review your suggested improvement(s) to make sure they are correct and fit within our documentation standards.

## Problems in the Hardware Design

All of our designs are open-source! Please help us make it better.

* Our board design files are contained in the [`Hardware` folder](https://github.com/sparkfun/SparkFun_Buck_Regulator_AP63357DV-7/tree/main/Hardware) of the [SparkFun Buck Regulator AP63357DV-7 repository](https://github.com/sparkfun/SparkFun_Buck_Regulator_AP63357DV-7).

### Did we forget to include an important function of the board? 🤦

If part of the board's functionality is missing, please [open an issue](https://github.com/sparkfun/SparkFun_Buck_Regulator_AP63357DV-7/issues) and file a feature request.

### Does something not make sense? 🤔
If part of the design is confusing, please [open an issue](https://github.com/sparkfun/SparkFun_Buck_Regulator_AP63357DV-7/issues) and let us know.

!!! tip "Design Considerations"
	Please keep in mind that we may intentionally exclude certain functions of the board to meet our product design requirements.
	
	* *For example, our Qwiic Micro boards are intended to fit on a small board layout and only use I<sup>2</sup>C communication; therefore, we may not have the SPI and interrupt pins available for users.*

### Do you wish to contribute directly to improving the board design?
1. With a GitHub account, [fork this repository](https://github.com/sparkfun/SparkFun_Buck_Regulator_AP63357DV-7/fork).
2. Add your design augmentation(s)
3. File a pull request with your changes, and enjoy making the ~~words~~ ~~worlds~~ world a better place.
	1. Once received, the engineer in charge of the original design will automatically be notified.
	2. We will review your suggested improvement(s) to verify that they are within our board design standards and meet our product design requirements.
	3. If approved, we will flag these changes for our next board revision. Congrats! 🍻

		!!! info
			Even if your suggestion is accepted, these changes may not be immediately available for purchase. We may have to cycle through our current product inventory first.

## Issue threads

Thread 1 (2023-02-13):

Request: Quiescent draw measurement

adamgarbo, 2023-02-13:
@SFE-Brudnerd can you measure the quiescent draw of this board without a load?

Looking at the schematic, I'm worried about the voltage divider on VEN. Can you clarify again its purpose?

Cheers,
Adam

SFE-Brudnerd, 2023-02-14:
Hey @adamgarbo, here are the results for the two BabyBucks I had laying around. My recommendation to you would again be to remove the resistors modifying the UVLO if you require a lower quiescent current. Hope this was helpful.

| Input Voltage (V) | Dev 1 Iq (uA) | Dev 2 Iq (uA) | Average (uA) |
| - | - | - | - |
| 6 | 194 | 198 | 196 |
| 12 | 198 | 220 | 209 |
| 24 | 281 | 300 | 290.5 |
| 32 | 347 | 363 | 355 |

adamgarbo, 2023-02-14:
Thanks @SFE-Brudnerd!

Did you happen to measure Iq when EN was disabled?

Cheers,
Adam

SFE-Brudnerd, 2023-02-14:
I hadn't, however it was easy enough to set it back up.

| Input Voltage (V) | Dev 1 (uA) |
| - | - |
| 6 | 65 |
| 12 | 129 |
| 24 | 260 |
| 32 | 330 |

Closed 2023-02-14.

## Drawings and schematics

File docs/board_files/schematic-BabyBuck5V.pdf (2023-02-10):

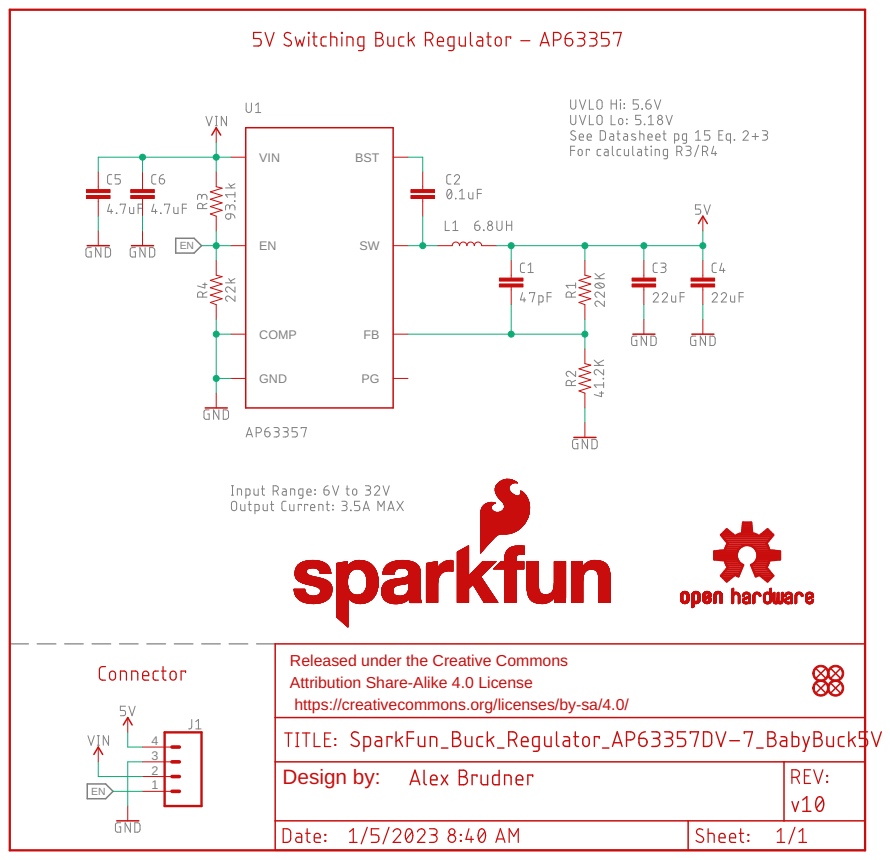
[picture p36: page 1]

Released under the Creative Commons
Attribution Share-Alike 4.0 License
https://creativecommons.org/licenses/by-sa/4.0/

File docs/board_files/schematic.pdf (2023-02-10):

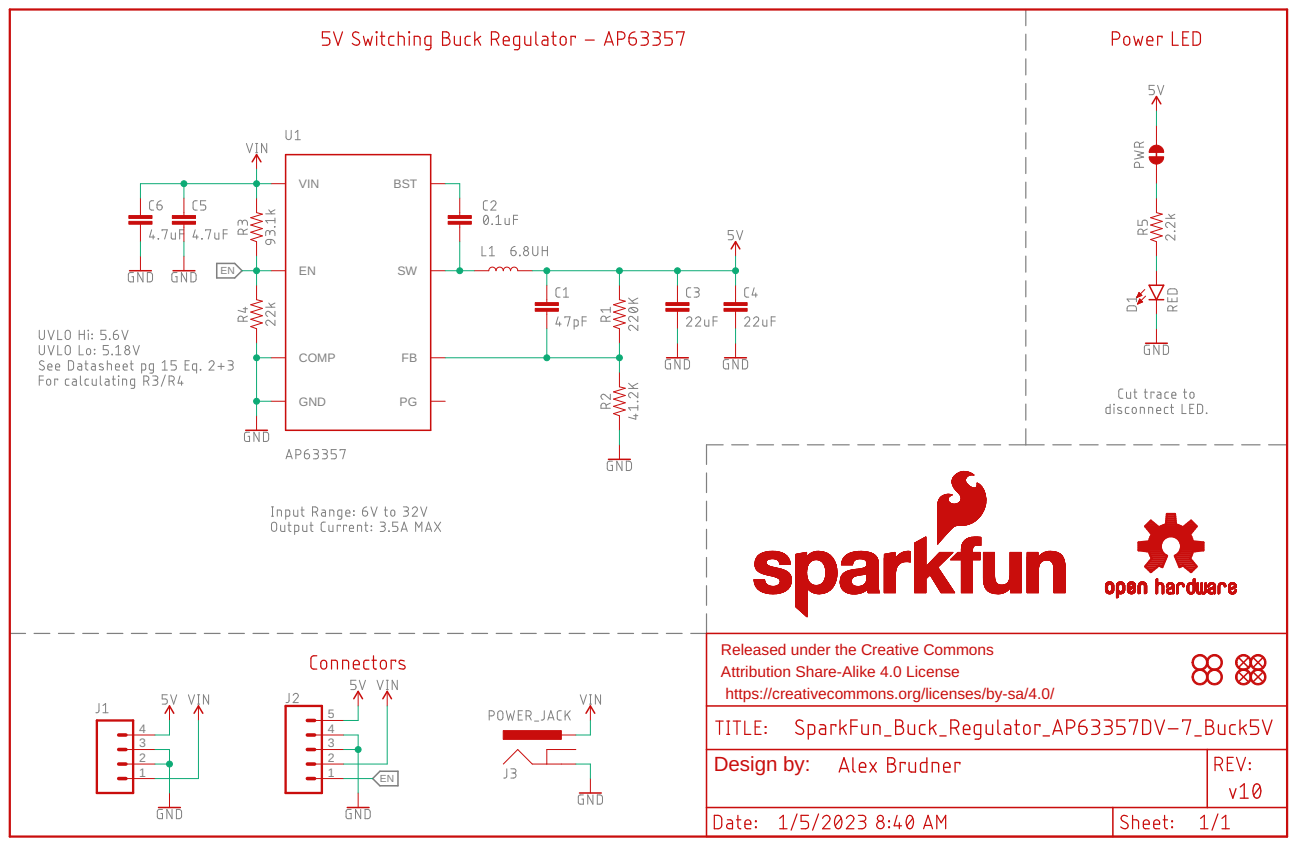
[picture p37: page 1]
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

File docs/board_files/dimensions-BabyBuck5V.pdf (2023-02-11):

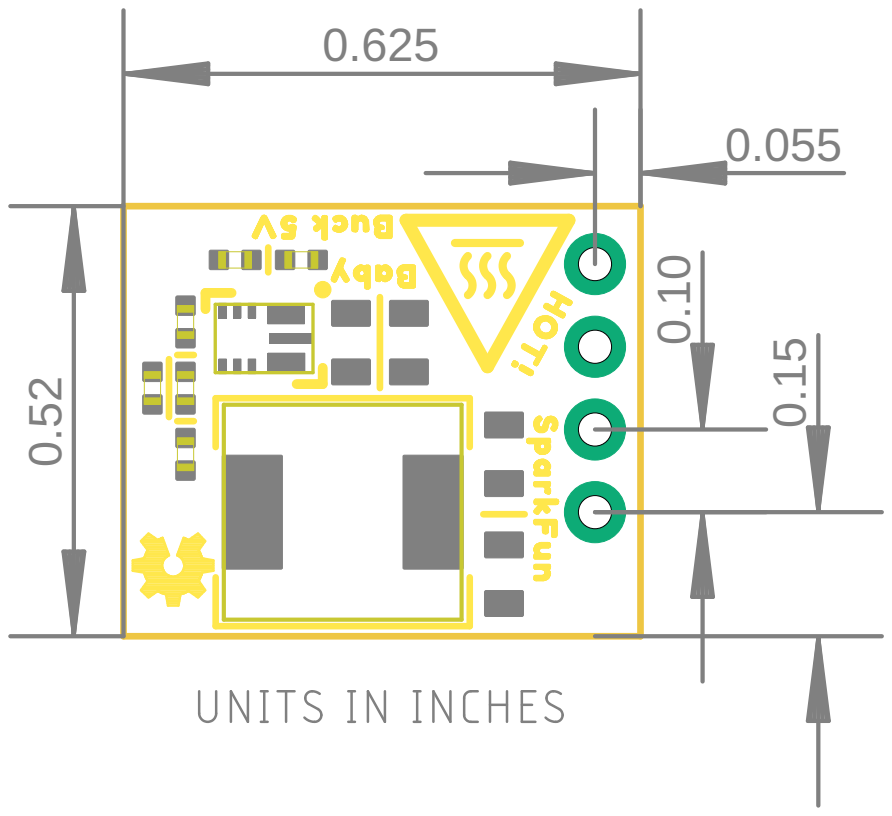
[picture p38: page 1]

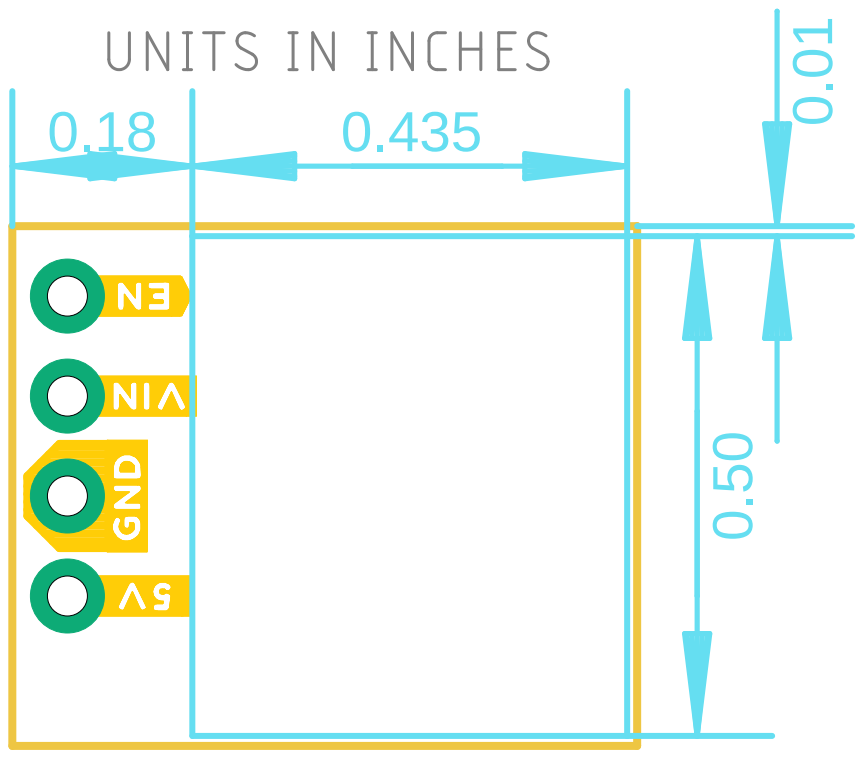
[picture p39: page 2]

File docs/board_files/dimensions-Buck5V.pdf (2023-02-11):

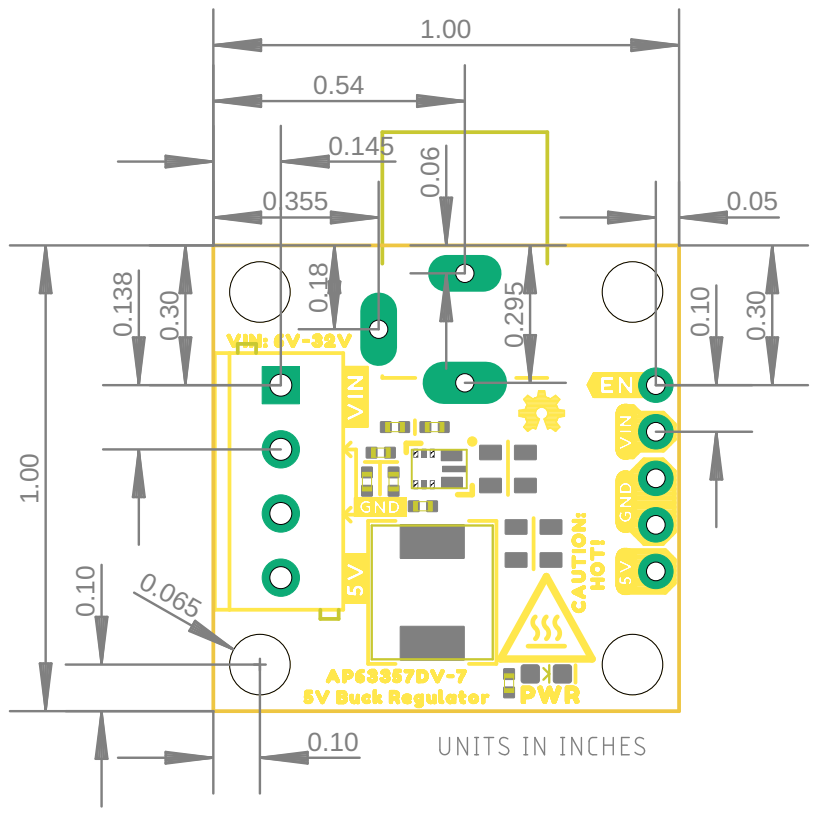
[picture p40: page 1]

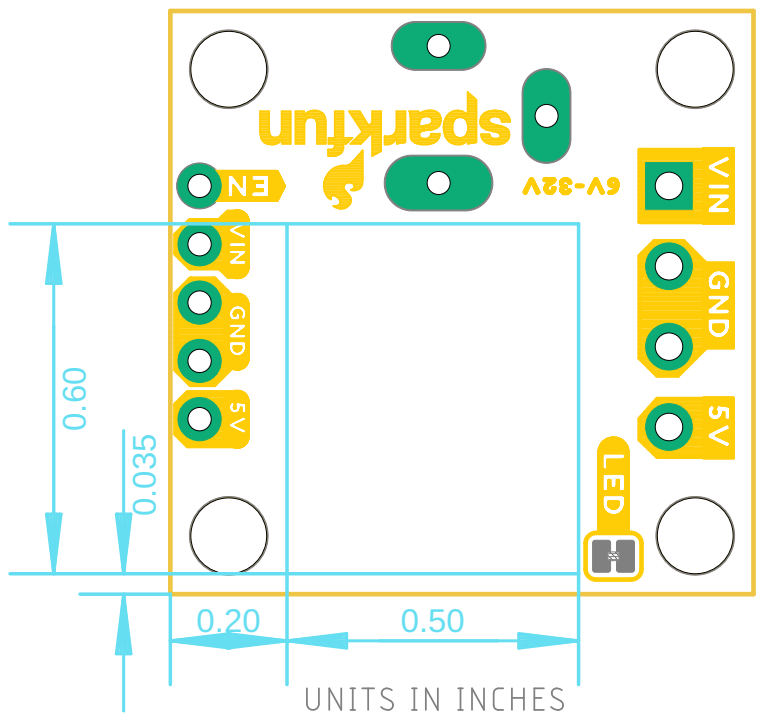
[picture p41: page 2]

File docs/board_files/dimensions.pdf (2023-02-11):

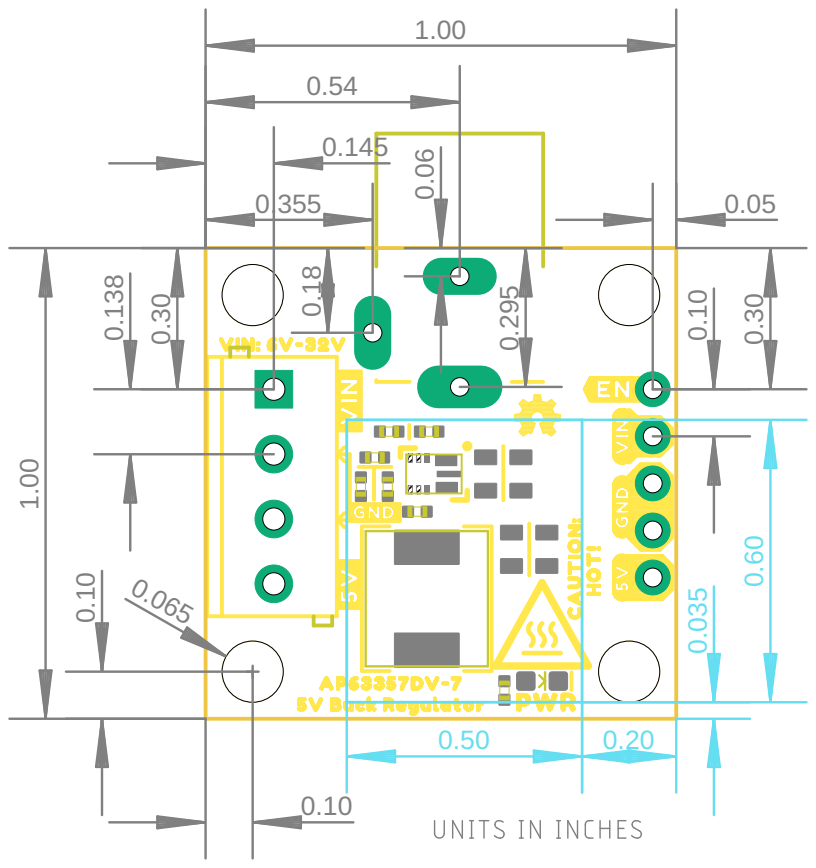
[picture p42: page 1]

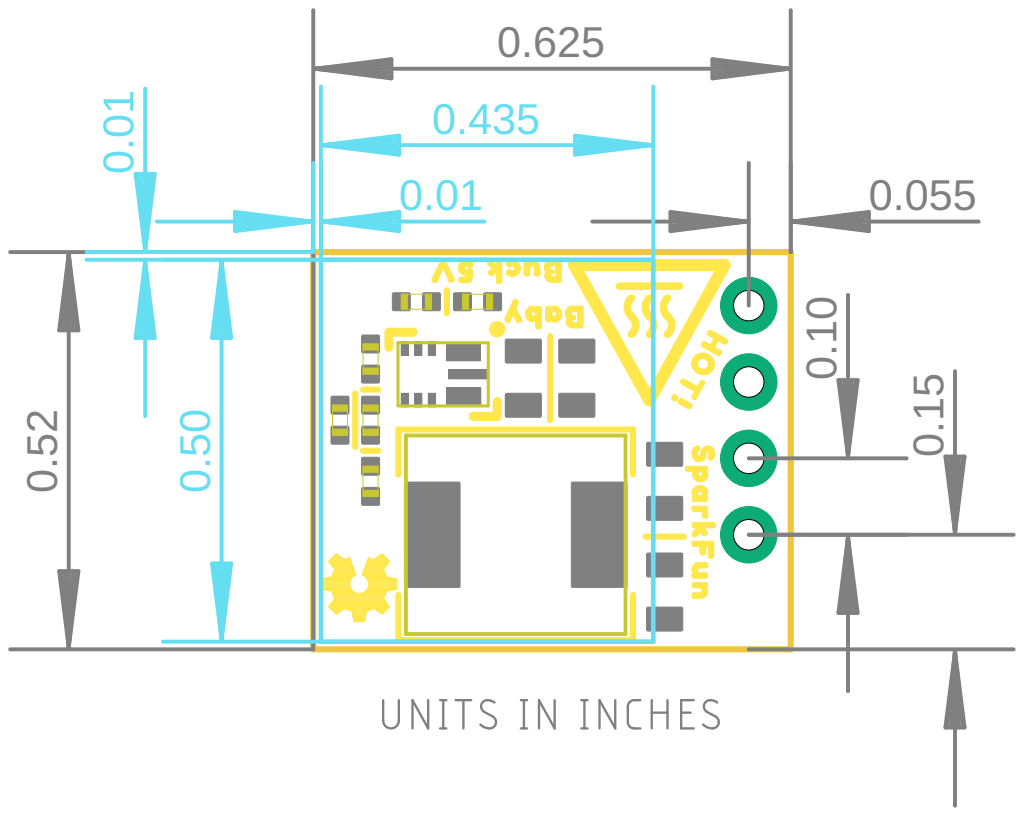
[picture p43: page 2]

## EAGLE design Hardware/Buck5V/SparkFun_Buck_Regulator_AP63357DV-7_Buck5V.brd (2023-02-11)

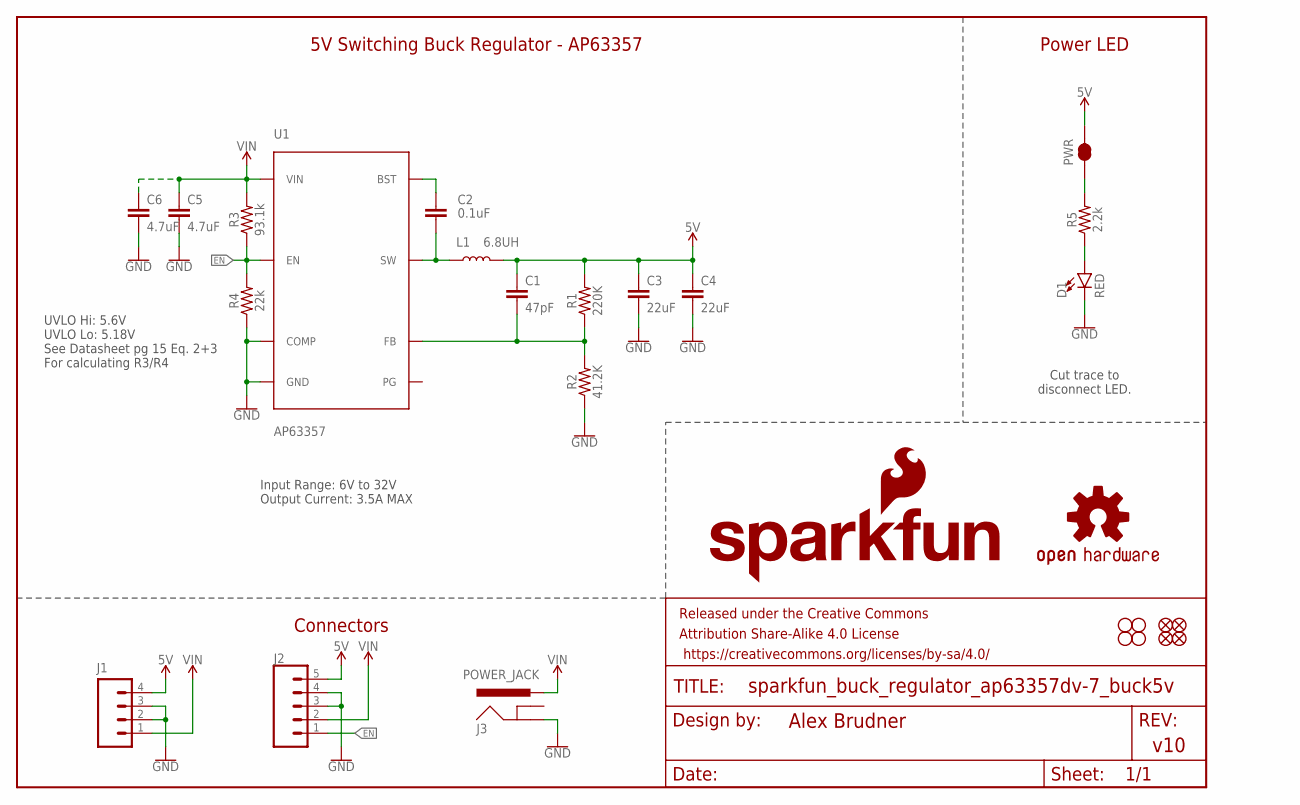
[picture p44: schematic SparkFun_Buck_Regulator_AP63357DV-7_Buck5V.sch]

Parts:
C1: 47pF; 0402-TIGHT
C2: 0.1uF; 0402-TIGHT
C3, C4: 22uF; 0805
C5, C6: 4.7uF; 0805
D1: RED; LED-0603
FD1, FD2, FD3, FD4: FIDUCIALUFIDUCIAL; FIDUCIAL-MICRO
FRAME1: FRAME-LEDGER; CREATIVE_COMMONS
H1, H2, H3, H4: STAND-OFF
J1: CONN_04SCREW; SCREWTERMINAL-3.5MM-4
J2: CONN_05NO_SILK; 1X05_NO_SILK
J3: POWER_JACK; POWER_JACK_PTH_SLOT_NO_OVRHNG_SILK
L1: 6.8UH; 07A7_6U8H
LOGO1: OSHW-LOGOMINI; OSHW-LOGO-MINI
LOGO2: SFE_LOGO_NAME_FLAME.1_INCH; SFE_LOGO_NAME_FLAME_.1
PWR: JUMPER-SMT_2_NC_TRACE_SILK; SMT-JUMPER_2_NC_TRACE_SILK
R1: 220K; 0402-TIGHT
R2: 41.2K; 0402-TIGHT
R3: 93.1k; 0402-TIGHT
R4: 22k; 0402-TIGHT
R5: 2.2k; 0402-TIGHT
U1: AP63357; V-DFN3020-13

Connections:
5V: C1.1, C3.1, C4.1, J1.4, J2.5, L1.P$2 (2), PWR.2, R1.2
EN: J2.1, R3.1, R4.2, U1.P$2 (EN)
FB: C1.2, R1.1, R2.2, U1.P$3 (FB)
GND: C3.2, C4.2, C5.2, C6.2, D1.C, J1.2, J1.3, J2.3, J2.4, J3.GND, R2.1, R4.1, U1.P$4 (COMP), U1.P$8 (GND)
unnamed: D1.A, R5.1
unnamed: C2.1, U1.P$6 (BST)
unnamed: PWR.1, R5.2
SW: C2.2, L1.P$1 (1), U1.P$7 (SW), U1.P$9 (SW)
VIN: C5.1, C6.1, J1.1, J2.2, J3.PWR, R3.2, U1.P$1 (VIN)

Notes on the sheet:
Power LED
Connectors
5V Switching Buck Regulator - AP63357
Input Range: 6V to 32V Output Current: 3.5A MAX
Cut trace to disconnect LED.
UVLO Hi: 5.6V UVLO Lo: 5.18V See Datasheet pg 15 Eq. 2+3 For calculating R3/R4

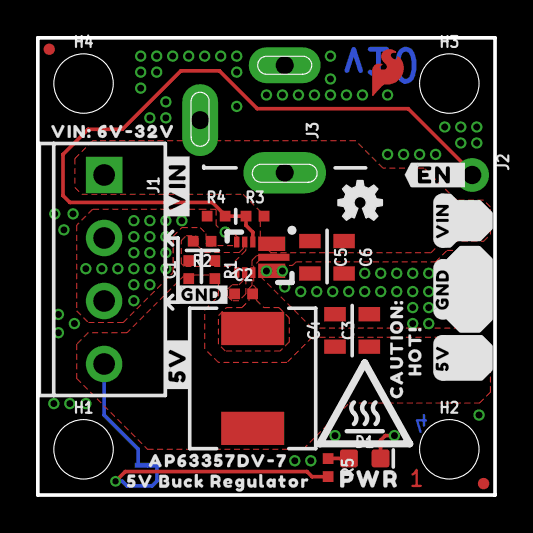
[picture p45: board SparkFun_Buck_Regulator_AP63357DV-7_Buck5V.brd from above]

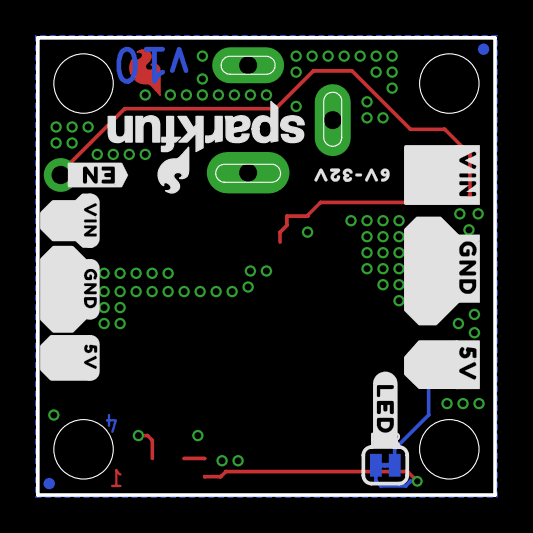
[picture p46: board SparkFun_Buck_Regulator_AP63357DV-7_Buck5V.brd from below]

Board: 4 copper layers, 25.4 x 25.4 mm, 54 parts (13 on the bottom side), 9 nets.

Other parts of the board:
U$1: AP63357DV#70
U$2: 5V_BUCK_REGULATOR0
U$3: #5V#4
U$4: #VIN#8
U$5, U$13: #VIN#0
U$6, U$7: #GND#0
U$8, U$19: #EN_#0
U$9: #GND#9
U$10: #5V#10
U$11: 6V#32V10
U$12: HOT##0
U$14, U$24: #5V#0
U$15: #LED_#0
U$16: CAUTION#0
U$17: SFE_LOGO_FLAME_COPPER_EXPOSED_.1
U$18: VIN#_6V#32V0
U$20: PWR0
U$21: #GND#1
U$22: HIGH_TEMP_WARNING
U$23: ORDERING_INSTRUCTIONS
U$26: #VIN#3

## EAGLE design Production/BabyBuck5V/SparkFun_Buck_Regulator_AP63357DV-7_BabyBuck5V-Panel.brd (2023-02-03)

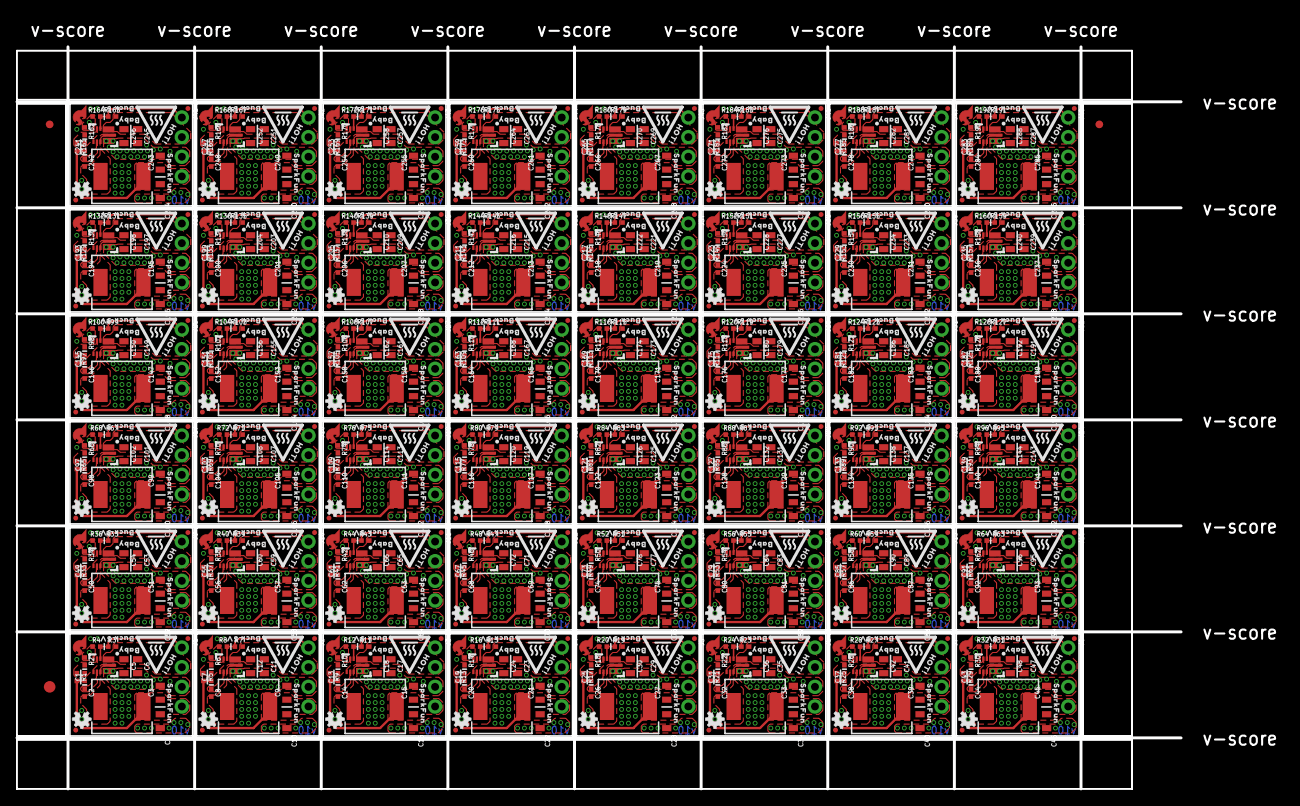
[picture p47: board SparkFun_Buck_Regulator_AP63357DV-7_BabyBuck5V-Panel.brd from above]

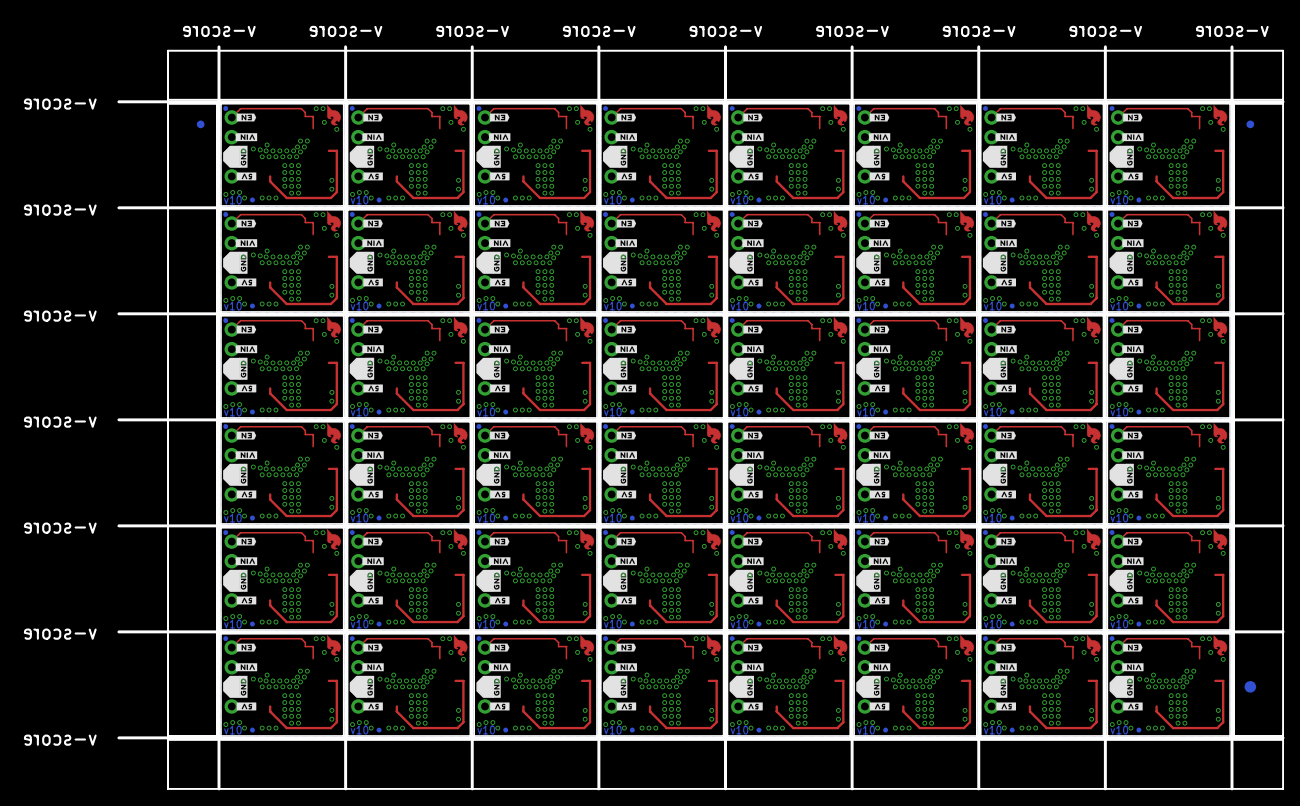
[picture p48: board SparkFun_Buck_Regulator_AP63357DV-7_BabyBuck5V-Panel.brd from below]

Board: 4 copper layers, 150.6 x 96.0 mm, 1446 parts (291 on the bottom side), 336 nets.

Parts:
C1, C7, C13, C19, C25, C31, C37, C43, C49, C55, C61, C67, C73, C79, C85, C91, C97, C103, C109, C115, C121, C127, C133, C139, C145, C151, C157, C163, C169, C175, C181, C187, C193, C199, C205, C211, C217, C223, C229, C235, C241, C247, C253, C259, C265, C271, C277, C283: 47pF; 0402-TIGHT
C2, C8, C14, C20, C26, C32, C38, C44, C50, C56, C62, C68, C74, C80, C86, C92, C98, C104, C110, C116, C122, C128, C134, C140, C146, C152, C158, C164, C170, C176, C182, C188, C194, C200, C206, C212, C218, C224, C230, C236, C242, C248, C254, C260, C266, C272, C278, C284: 0.1uF; 0402-TIGHT
C3, C4, C9, C10, C15, C16, C21, C22, C27, C28, C33, C34, C39, C40, C45, C46, C51, C52, C57, C58, C63, C64, C69, C70, C75, C76, C81, C82, C87, C88, C93, C94, C99, C100, C105, C106, C111, C112, C117, C118, C123, C124, C129, C130, C135, C136, C141, C142, C147, C148, C153, C154, C159, C160, C165, C166, C171, C172, C177, C178, C183, C184, C189, C190, C195, C196, C201, C202, C207, C208, C213, C214, C219, C220, C225, C226, C231, C232, C237, C238, C243, C244, C249, C250, C255, C256, C261, C262, C267, C268, C273, C274, C279, C280, C285, C286: 22uF; 0805
C5, C6, C11, C12, C17, C18, C23, C24, C29, C30, C35, C36, C41, C42, C47, C48, C53, C54, C59, C60, C65, C66, C71, C72, C77, C78, C83, C84, C89, C90, C95, C96, C101, C102, C107, C108, C113, C114, C119, C120, C125, C126, C131, C132, C137, C138, C143, C144, C149, C150, C155, C156, C161, C162, C167, C168, C173, C174, C179, C180, C185, C186, C191, C192, C197, C198, C203, C204, C209, C210, C215, C216, C221, C222, C227, C228, C233, C234, C239, C240, C245, C246, C251, C252, C257, C258, C263, C264, C269, C270, C275, C276, C281, C282, C287, C288: 4.7uF; 0805
E$1, E$2, E$3, E$4: FIDUCIAL-1X2
E$5, E$6: FIDUCIAL-1.5X3
FD1, FD2, FD3, FD4, FD5, FD6, FD7, FD8, FD9, FD10, FD11, FD12, FD13, FD14, FD15, FD16, FD17, FD18, FD19, FD20, FD21, FD22, FD23, FD24, FD25, FD26, FD27, FD28, FD29, FD30, FD31, FD32, FD33, FD34, FD35, FD36, FD37, FD38, FD39, FD40, FD41, FD42, FD43, FD44, FD45, FD46, FD47, FD48, FD49, FD50, FD51, FD52, FD53, FD54, FD55, FD56, FD57, FD58, FD59, FD60, FD61, FD62, FD63, FD64, FD65, FD66, FD67, FD68, FD69, FD70, FD71, FD72, FD73, FD74, FD75, FD76, FD77, FD78, FD79, FD80, FD81, FD82, FD83, FD84, FD85, FD86, FD87, FD88, FD89, FD90, FD91, FD92, FD93, FD94, FD95, FD96, FD97, FD98, FD99, FD100, FD101, FD102, FD103, FD104, FD105, FD106, FD107, FD108, FD109, FD110, FD111, FD112, FD113, FD114, FD115, FD116, FD117, FD118, FD119, FD120, FD121, FD122, FD123, FD124, FD125, FD126, FD127, FD128, FD129, FD130, FD131, FD132, FD133, FD134, FD135, FD136, FD137, FD138, FD139, FD140, FD141, FD142, FD143, FD144, FD145, FD146, FD147, FD148, FD149, FD150, FD151, FD152, FD153, FD154, FD155, FD156, FD157, FD158, FD159, FD160, FD161, FD162, FD163, FD164, FD165, FD166, FD167, FD168, FD169, FD170, FD171, FD172, FD173, FD174, FD175, FD176, FD177, FD178, FD179, FD180, FD181, FD182, FD183, FD184, FD185, FD186, FD187, FD188, FD189, FD190, FD191, FD192: FIDUCIALUFIDUCIAL; FIDUCIAL-MICRO
J1, J2, J3, J4, J5, J6, J7, J8, J9, J10, J11, J12, J13, J14, J15, J16, J17, J18, J19, J20, J21, J22, J23, J24, J25, J26, J27, J28, J29, J30, J31, J32, J33, J34, J35, J36, J37, J38, J39, J40, J41, J42, J43, J44, J45, J46, J47, J48: 1X04_NO_SILK
L1, L2, L3, L4, L5, L6, L7, L8, L9, L10, L11, L12, L13, L14, L15, L16, L17, L18, L19, L20, L21, L22, L23, L24, L25, L26, L27, L28, L29, L30, L31, L32, L33, L34, L35, L36, L37, L38, L39, L40, L41, L42, L43, L44, L45, L46, L47, L48: 6.8UH; 07A7_6U8H
LOGO1, LOGO4, LOGO6, LOGO8, LOGO10, LOGO12, LOGO14, LOGO16, LOGO18, LOGO20, LOGO22, LOGO24, LOGO26, LOGO28, LOGO30, LOGO32, LOGO34, LOGO36, LOGO38, LOGO40, LOGO42, LOGO44, LOGO46, LOGO48, LOGO50, LOGO52, LOGO54, LOGO56, LOGO58, LOGO60, LOGO62, LOGO64, LOGO66, LOGO68, LOGO70, LOGO72, LOGO74, LOGO76, LOGO78, LOGO80, LOGO82, LOGO84, LOGO86, LOGO88, LOGO90, LOGO92, LOGO94, LOGO96: SFE_LOGO_NAME_FLAMEBLANK; BLANK
LOGO2, LOGO3, LOGO5, LOGO7, LOGO9, LOGO11, LOGO13, LOGO15, LOGO17, LOGO19, LOGO21, LOGO23, LOGO25, LOGO27, LOGO29, LOGO31, LOGO33, LOGO35, LOGO37, LOGO39, LOGO41, LOGO43, LOGO45, LOGO47, LOGO49, LOGO51, LOGO53, LOGO55, LOGO57, LOGO59, LOGO61, LOGO63, LOGO65, LOGO67, LOGO69, LOGO71, LOGO73, LOGO75, LOGO77, LOGO79, LOGO81, LOGO83, LOGO85, LOGO87, LOGO89, LOGO91, LOGO93, LOGO95: OSHW-LOGOMINI; OSHW-LOGO-MINI
R1, R5, R9, R13, R17, R21, R25, R29, R33, R37, R41, R45, R49, R53, R57, R61, R65, R69, R73, R77, R81, R85, R89, R93, R97, R101, R105, R109, R113, R117, R121, R125, R129, R133, R137, R141, R145, R149, R153, R157, R161, R165, R169, R173, R177, R181, R185, R189: 220K; 0402-TIGHT
R2, R6, R10, R14, R18, R22, R26, R30, R34, R38, R42, R46, R50, R54, R58, R62, R66, R70, R74, R78, R82, R86, R90, R94, R98, R102, R106, R110, R114, R118, R122, R126, R130, R134, R138, R142, R146, R150, R154, R158, R162, R166, R170, R174, R178, R182, R186, R190: 41.2K; 0402-TIGHT
R3, R7, R11, R15, R19, R23, R27, R31, R35, R39, R43, R47, R51, R55, R59, R63, R67, R71, R75, R79, R83, R87, R91, R95, R99, R103, R107, R111, R115, R119, R123, R127, R131, R135, R139, R143, R147, R151, R155, R159, R163, R167, R171, R175, R179, R183, R187, R191: 93.1k; 0402-TIGHT
R4, R8, R12, R16, R20, R24, R28, R32, R36, R40, R44, R48, R52, R56, R60, R64, R68, R72, R76, R80, R84, R88, R92, R96, R100, R104, R108, R112, R116, R120, R124, R128, R132, R136, R140, R144, R148, R152, R156, R160, R164, R168, R172, R176, R180, R184, R188, R192: 22k; 0402-TIGHT
U1, U2, U3, U4, U5, U6, U7, U8, U9, U10, U11, U12, U13, U14, U15, U16, U17, U18, U19, U20, U21, U22, U23, U24, U25, U26, U27, U28, U29, U30, U31, U32, U33, U34, U35, U36, U37, U38, U39, U40, U41, U42, U43, U44, U45, U46, U47, U48: AP63357; V-DFN3020-13
U$1, U$11, U$23, U$34, U$45, U$56, U$67, U$78, U$89, U$100, U$111, U$122, U$133, U$144, U$155, U$166, U$177, U$188, U$199, U$210, U$221, U$232, U$243, U$254, U$265, U$276, U$287, U$298, U$309, U$320, U$331, U$342, U$353, U$364, U$375, U$386, U$397, U$408, U$419, U$430, U$441, U$452, U$463, U$474, U$485, U$496, U$507, U$518: SFE_LOGO_FLAME_COPPER_EXPOSED_.1
U$2, U$18, U$29, U$40, U$51, U$62, U$73, U$84, U$95, U$106, U$117, U$128, U$139, U$150, U$161, U$172, U$183, U$194, U$205, U$216, U$227, U$238, U$249, U$260, U$271, U$282, U$293, U$304, U$315, U$326, U$337, U$348, U$359, U$370, U$381, U$392, U$403, U$414, U$425, U$436, U$447, U$458, U$469, U$480, U$491, U$502, U$513, U$524: #EN_#10
U$3, U$19, U$30, U$41, U$52, U$63, U$74, U$85, U$96, U$107, U$118, U$129, U$140, U$151, U$162, U$173, U$184, U$195, U$206, U$217, U$228, U$239, U$250, U$261, U$272, U$283, U$294, U$305, U$316, U$327, U$338, U$349, U$360, U$371, U$382, U$393, U$404, U$415, U$426, U$437, U$448, U$459, U$470, U$481, U$492, U$503, U$514, U$525: #VIN_#11
U$4, U$20, U$31, U$42, U$53, U$64, U$75, U$86, U$97, U$108, U$119, U$130, U$141, U$152, U$163, U$174, U$185, U$196, U$207, U$218, U$229, U$240, U$251, U$262, U$273, U$284, U$295, U$306, U$317, U$328, U$339, U$350, U$361, U$372, U$383, U$394, U$405, U$416, U$427, U$438, U$449, U$460, U$471, U$482, U$493, U$504, U$515, U$526: #GND#13
U$5, U$21, U$32, U$43, U$54, U$65, U$76, U$87, U$98, U$109, U$120, U$131, U$142, U$153, U$164, U$175, U$186, U$197, U$208, U$219, U$230, U$241, U$252, U$263, U$274, U$285, U$296, U$307, U$318, U$329, U$340, U$351, U$362, U$373, U$384, U$395, U$406, U$417, U$428, U$439, U$450, U$461, U$472, U$483, U$494, U$505, U$516, U$527: #_5V_#6
U$6, U$13, U$25, U$36, U$47, U$58, U$69, U$80, U$91, U$102, U$113, U$124, U$135, U$146, U$157, U$168, U$179, U$190, U$201, U$212, U$223, U$234, U$245, U$256, U$267, U$278, U$289, U$300, U$311, U$322, U$333, U$344, U$355, U$366, U$377, U$388, U$399, U$410, U$421, U$432, U$443, U$454, U$465, U$476, U$487, U$498, U$509, U$520: BABY0
U$7, U$15, U$26, U$37, U$48, U$59, U$70, U$81, U$92, U$103, U$114, U$125, U$136, U$147, U$158, U$169, U$180, U$191, U$202, U$213, U$224, U$235, U$246, U$257, U$268, U$279, U$290, U$301, U$312, U$323, U$334, U$345, U$356, U$367, U$378, U$389, U$400, U$411, U$422, U$433, U$444, U$455, U$466, U$477, U$488, U$499, U$510, U$521: BUCK0
U$8, U$12, U$24, U$35, U$46, U$57, U$68, U$79, U$90, U$101, U$112, U$123, U$134, U$145, U$156, U$167, U$178, U$189, U$200, U$211, U$222, U$233, U$244, U$255, U$266, U$277, U$288, U$299, U$310, U$321, U$332, U$343, U$354, U$365, U$376, U$387, U$398, U$409, U$420, U$431, U$442, U$453, U$464, U$475, U$486, U$497, U$508, U$519: HIGH_TEMP_WARNING
U$9, U$16, U$27, U$38, U$49, U$60, U$71, U$82, U$93, U$104, U$115, U$126, U$137, U$148, U$159, U$170, U$181, U$192, U$203, U$214, U$225, U$236, U$247, U$258, U$269, U$280, U$291, U$302, U$313, U$324, U$335, U$346, U$357, U$368, U$379, U$390, U$401, U$412, U$423, U$434, U$445, U$456, U$467, U$478, U$489, U$500, U$511, U$522: 5V0
U$10, U$22, U$33, U$44, U$55, U$66, U$77, U$88, U$99, U$110, U$121, U$132, U$143, U$154, U$165, U$176, U$187, U$198, U$209, U$220, U$231, U$242, U$253, U$264, U$275, U$286, U$297, U$308, U$319, U$330, U$341, U$352, U$363, U$374, U$385, U$396, U$407, U$418, U$429, U$440, U$451, U$462, U$473, U$484, U$495, U$506, U$517, U$528: HOT##7
U$14, U$17, U$28, U$39, U$50, U$61, U$72, U$83, U$94, U$105, U$116, U$127, U$138, U$149, U$160, U$171, U$182, U$193, U$204, U$215, U$226, U$237, U$248, U$259, U$270, U$281, U$292, U$303, U$314, U$325, U$336, U$347, U$358, U$369, U$380, U$391, U$402, U$413, U$424, U$435, U$446, U$457, U$468, U$479, U$490, U$501, U$512, U$523: SPARKFUN0

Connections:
5V: C1.1, C3.1, C4.1, J1.4, L1.P$2, R1.2
5V1: C7.1, C9.1, C10.1, J2.4, L2.P$2, R5.2
5V2: C13.1, C15.1, C16.1, J3.4, L3.P$2, R9.2
5V3: C19.1, C21.1, C22.1, J4.4, L4.P$2, R13.2
5V4: C25.1, C27.1, C28.1, J5.4, L5.P$2, R17.2
5V5: C31.1, C33.1, C34.1, J6.4, L6.P$2, R21.2
5V6: C37.1, C39.1, C40.1, J7.4, L7.P$2, R25.2
5V7: C43.1, C45.1, C46.1, J8.4, L8.P$2, R29.2
5V8: C49.1, C51.1, C52.1, J9.4, L9.P$2, R33.2
5V9: C55.1, C57.1, C58.1, J10.4, L10.P$2, R37.2
5V10: C61.1, C63.1, C64.1, J11.4, L11.P$2, R41.2
5V11: C67.1, C69.1, C70.1, J12.4, L12.P$2, R45.2
5V12: C73.1, C75.1, C76.1, J13.4, L13.P$2, R49.2
5V13: C79.1, C81.1, C82.1, J14.4, L14.P$2, R53.2
5V14: C85.1, C87.1, C88.1, J15.4, L15.P$2, R57.2
5V15: C91.1, C93.1, C94.1, J16.4, L16.P$2, R61.2
5V16: C97.1, C99.1, C100.1, J17.4, L17.P$2, R65.2
5V17: C103.1, C105.1, C106.1, J18.4, L18.P$2, R69.2
5V18: C109.1, C111.1, C112.1, J19.4, L19.P$2, R73.2
5V19: C115.1, C117.1, C118.1, J20.4, L20.P$2, R77.2
5V20: C121.1, C123.1, C124.1, J21.4, L21.P$2, R81.2
5V21: C127.1, C129.1, C130.1, J22.4, L22.P$2, R85.2
5V22: C133.1, C135.1, C136.1, J23.4, L23.P$2, R89.2
5V23: C139.1, C141.1, C142.1, J24.4, L24.P$2, R93.2
5V24: C145.1, C147.1, C148.1, J25.4, L25.P$2, R97.2
5V25: C151.1, C153.1, C154.1, J26.4, L26.P$2, R101.2
5V26: C157.1, C159.1, C160.1, J27.4, L27.P$2, R105.2
5V27: C163.1, C165.1, C166.1, J28.4, L28.P$2, R109.2
5V28: C169.1, C171.1, C172.1, J29.4, L29.P$2, R113.2
5V29: C175.1, C177.1, C178.1, J30.4, L30.P$2, R117.2
5V30: C181.1, C183.1, C184.1, J31.4, L31.P$2, R121.2
5V31: C187.1, C189.1, C190.1, J32.4, L32.P$2, R125.2
5V32: C193.1, C195.1, C196.1, J33.4, L33.P$2, R129.2
5V33: C199.1, C201.1, C202.1, J34.4, L34.P$2, R133.2
5V34: C205.1, C207.1, C208.1, J35.4, L35.P$2, R137.2
5V35: C211.1, C213.1, C214.1, J36.4, L36.P$2, R141.2
5V36: C217.1, C219.1, C220.1, J37.4, L37.P$2, R145.2
5V37: C223.1, C225.1, C226.1, J38.4, L38.P$2, R149.2
5V38: C229.1, C231.1, C232.1, J39.4, L39.P$2, R153.2
5V39: C235.1, C237.1, C238.1, J40.4, L40.P$2, R157.2
5V40: C241.1, C243.1, C244.1, J41.4, L41.P$2, R161.2
5V41: C247.1, C249.1, C250.1, J42.4, L42.P$2, R165.2
5V42: C253.1, C255.1, C256.1, J43.4, L43.P$2, R169.2
5V43: C259.1, C261.1, C262.1, J44.4, L44.P$2, R173.2
5V44: C265.1, C267.1, C268.1, J45.4, L45.P$2, R177.2
5V45: C271.1, C273.1, C274.1, J46.4, L46.P$2, R181.2
5V46: C277.1, C279.1, C280.1, J47.4, L47.P$2, R185.2
5V47: C283.1, C285.1, C286.1, J48.4, L48.P$2, R189.2
EN: J1.1, R3.1, R4.2, U1.P$2
EN1: J2.1, R7.1, R8.2, U2.P$2
EN2: J3.1, R11.1, R12.2, U3.P$2
EN3: J4.1, R15.1, R16.2, U4.P$2
EN4: J5.1, R19.1, R20.2, U5.P$2
EN5: J6.1, R23.1, R24.2, U6.P$2
EN6: J7.1, R27.1, R28.2, U7.P$2
EN7: J8.1, R31.1, R32.2, U8.P$2
EN8: J9.1, R35.1, R36.2, U9.P$2
EN9: J10.1, R39.1, R40.2, U10.P$2
EN10: J11.1, R43.1, R44.2, U11.P$2
EN11: J12.1, R47.1, R48.2, U12.P$2
EN12: J13.1, R51.1, R52.2, U13.P$2
EN13: J14.1, R55.1, R56.2, U14.P$2
EN14: J15.1, R59.1, R60.2, U15.P$2
EN15: J16.1, R63.1, R64.2, U16.P$2
EN16: J17.1, R67.1, R68.2, U17.P$2
EN17: J18.1, R71.1, R72.2, U18.P$2
EN18: J19.1, R75.1, R76.2, U19.P$2
EN19: J20.1, R79.1, R80.2, U20.P$2
EN20: J21.1, R83.1, R84.2, U21.P$2
EN21: J22.1, R87.1, R88.2, U22.P$2
EN22: J23.1, R91.1, R92.2, U23.P$2
EN23: J24.1, R95.1, R96.2, U24.P$2
EN24: J25.1, R99.1, R100.2, U25.P$2
EN25: J26.1, R103.1, R104.2, U26.P$2
EN26: J27.1, R107.1, R108.2, U27.P$2
EN27: J28.1, R111.1, R112.2, U28.P$2
EN28: J29.1, R115.1, R116.2, U29.P$2
EN29: J30.1, R119.1, R120.2, U30.P$2
EN30: J31.1, R123.1, R124.2, U31.P$2
EN31: J32.1, R127.1, R128.2, U32.P$2
EN32: J33.1, R131.1, R132.2, U33.P$2
EN33: J34.1, R135.1, R136.2, U34.P$2
EN34: J35.1, R139.1, R140.2, U35.P$2
EN35: J36.1, R143.1, R144.2, U36.P$2
EN36: J37.1, R147.1, R148.2, U37.P$2
EN37: J38.1, R151.1, R152.2, U38.P$2
EN38: J39.1, R155.1, R156.2, U39.P$2
EN39: J40.1, R159.1, R160.2, U40.P$2
EN40: J41.1, R163.1, R164.2, U41.P$2
EN41: J42.1, R167.1, R168.2, U42.P$2
EN42: J43.1, R171.1, R172.2, U43.P$2
EN43: J44.1, R175.1, R176.2, U44.P$2
EN44: J45.1, R179.1, R180.2, U45.P$2
EN45: J46.1, R183.1, R184.2, U46.P$2
EN46: J47.1, R187.1, R188.2, U47.P$2
EN47: J48.1, R191.1, R192.2, U48.P$2
FB: C1.2, R1.1, R2.2, U1.P$3
FB1: C7.2, R5.1, R6.2, U2.P$3
FB2: C13.2, R9.1, R10.2, U3.P$3
FB3: C19.2, R13.1, R14.2, U4.P$3
FB4: C25.2, R17.1, R18.2, U5.P$3
FB5: C31.2, R21.1, R22.2, U6.P$3
FB6: C37.2, R25.1, R26.2, U7.P$3
FB7: C43.2, R29.1, R30.2, U8.P$3
FB8: C49.2, R33.1, R34.2, U9.P$3
FB9: C55.2, R37.1, R38.2, U10.P$3
FB10: C61.2, R41.1, R42.2, U11.P$3
FB11: C67.2, R45.1, R46.2, U12.P$3
FB12: C73.2, R49.1, R50.2, U13.P$3
FB13: C79.2, R53.1, R54.2, U14.P$3
FB14: C85.2, R57.1, R58.2, U15.P$3
FB15: C91.2, R61.1, R62.2, U16.P$3
FB16: C97.2, R65.1, R66.2, U17.P$3
FB17: C103.2, R69.1, R70.2, U18.P$3
FB18: C109.2, R73.1, R74.2, U19.P$3
FB19: C115.2, R77.1, R78.2, U20.P$3
FB20: C121.2, R81.1, R82.2, U21.P$3
FB21: C127.2, R85.1, R86.2, U22.P$3
FB22: C133.2, R89.1, R90.2, U23.P$3
FB23: C139.2, R93.1, R94.2, U24.P$3
FB24: C145.2, R97.1, R98.2, U25.P$3
FB25: C151.2, R101.1, R102.2, U26.P$3
FB26: C157.2, R105.1, R106.2, U27.P$3
FB27: C163.2, R109.1, R110.2, U28.P$3
FB28: C169.2, R113.1, R114.2, U29.P$3
FB29: C175.2, R117.1, R118.2, U30.P$3
FB30: C181.2, R121.1, R122.2, U31.P$3
FB31: C187.2, R125.1, R126.2, U32.P$3
FB32: C193.2, R129.1, R130.2, U33.P$3
FB33: C199.2, R133.1, R134.2, U34.P$3
FB34: C205.2, R137.1, R138.2, U35.P$3
FB35: C211.2, R141.1, R142.2, U36.P$3
FB36: C217.2, R145.1, R146.2, U37.P$3
FB37: C223.2, R149.1, R150.2, U38.P$3
FB38: C229.2, R153.1, R154.2, U39.P$3
FB39: C235.2, R157.1, R158.2, U40.P$3
FB40: C241.2, R161.1, R162.2, U41.P$3
FB41: C247.2, R165.1, R166.2, U42.P$3
FB42: C253.2, R169.1, R170.2, U43.P$3
FB43: C259.2, R173.1, R174.2, U44.P$3
FB44: C265.2, R177.1, R178.2, U45.P$3
FB45: C271.2, R181.1, R182.2, U46.P$3
FB46: C277.2, R185.1, R186.2, U47.P$3
FB47: C283.2, R189.1, R190.2, U48.P$3
GND: C3.2, C4.2, C5.2, C6.2, J1.3, R2.1, R4.1, U1.P$4, U1.P$8
GND1: C9.2, C10.2, C11.2, C12.2, J2.3, R6.1, R8.1, U2.P$4, U2.P$8
GND2: C15.2, C16.2, C17.2, C18.2, J3.3, R10.1, R12.1, U3.P$4, U3.P$8
GND3: C21.2, C22.2, C23.2, C24.2, J4.3, R14.1, R16.1, U4.P$4, U4.P$8
GND4: C27.2, C28.2, C29.2, C30.2, J5.3, R18.1, R20.1, U5.P$4, U5.P$8
GND5: C33.2, C34.2, C35.2, C36.2, J6.3, R22.1, R24.1, U6.P$4, U6.P$8
GND6: C39.2, C40.2, C41.2, C42.2, J7.3, R26.1, R28.1, U7.P$4, U7.P$8
GND7: C45.2, C46.2, C47.2, C48.2, J8.3, R30.1, R32.1, U8.P$4, U8.P$8
GND8: C51.2, C52.2, C53.2, C54.2, J9.3, R34.1, R36.1, U9.P$4, U9.P$8
GND9: C57.2, C58.2, C59.2, C60.2, J10.3, R38.1, R40.1, U10.P$4, U10.P$8
GND10: C63.2, C64.2, C65.2, C66.2, J11.3, R42.1, R44.1, U11.P$4, U11.P$8
GND11: C69.2, C70.2, C71.2, C72.2, J12.3, R46.1, R48.1, U12.P$4, U12.P$8
GND12: C75.2, C76.2, C77.2, C78.2, J13.3, R50.1, R52.1, U13.P$4, U13.P$8
GND13: C81.2, C82.2, C83.2, C84.2, J14.3, R54.1, R56.1, U14.P$4, U14.P$8
GND14: C87.2, C88.2, C89.2, C90.2, J15.3, R58.1, R60.1, U15.P$4, U15.P$8
GND15: C93.2, C94.2, C95.2, C96.2, J16.3, R62.1, R64.1, U16.P$4, U16.P$8
GND16: C99.2, C100.2, C101.2, C102.2, J17.3, R66.1, R68.1, U17.P$4, U17.P$8
GND17: C105.2, C106.2, C107.2, C108.2, J18.3, R70.1, R72.1, U18.P$4, U18.P$8
GND18: C111.2, C112.2, C113.2, C114.2, J19.3, R74.1, R76.1, U19.P$4, U19.P$8
GND19: C117.2, C118.2, C119.2, C120.2, J20.3, R78.1, R80.1, U20.P$4, U20.P$8
GND20: C123.2, C124.2, C125.2, C126.2, J21.3, R82.1, R84.1, U21.P$4, U21.P$8
GND21: C129.2, C130.2, C131.2, C132.2, J22.3, R86.1, R88.1, U22.P$4, U22.P$8
GND22: C135.2, C136.2, C137.2, C138.2, J23.3, R90.1, R92.1, U23.P$4, U23.P$8
GND23: C141.2, C142.2, C143.2, C144.2, J24.3, R94.1, R96.1, U24.P$4, U24.P$8
GND24: C147.2, C148.2, C149.2, C150.2, J25.3, R98.1, R100.1, U25.P$4, U25.P$8
GND25: C153.2, C154.2, C155.2, C156.2, J26.3, R102.1, R104.1, U26.P$4, U26.P$8
GND26: C159.2, C160.2, C161.2, C162.2, J27.3, R106.1, R108.1, U27.P$4, U27.P$8
GND27: C165.2, C166.2, C167.2, C168.2, J28.3, R110.1, R112.1, U28.P$4, U28.P$8
GND28: C171.2, C172.2, C173.2, C174.2, J29.3, R114.1, R116.1, U29.P$4, U29.P$8
GND29: C177.2, C178.2, C179.2, C180.2, J30.3, R118.1, R120.1, U30.P$4, U30.P$8
GND30: C183.2, C184.2, C185.2, C186.2, J31.3, R122.1, R124.1, U31.P$4, U31.P$8
GND31: C189.2, C190.2, C191.2, C192.2, J32.3, R126.1, R128.1, U32.P$4, U32.P$8
GND32: C195.2, C196.2, C197.2, C198.2, J33.3, R130.1, R132.1, U33.P$4, U33.P$8
GND33: C201.2, C202.2, C203.2, C204.2, J34.3, R134.1, R136.1, U34.P$4, U34.P$8
GND34: C207.2, C208.2, C209.2, C210.2, J35.3, R138.1, R140.1, U35.P$4, U35.P$8
GND35: C213.2, C214.2, C215.2, C216.2, J36.3, R142.1, R144.1, U36.P$4, U36.P$8
GND36: C219.2, C220.2, C221.2, C222.2, J37.3, R146.1, R148.1, U37.P$4, U37.P$8
GND37: C225.2, C226.2, C227.2, C228.2, J38.3, R150.1, R152.1, U38.P$4, U38.P$8
GND38: C231.2, C232.2, C233.2, C234.2, J39.3, R154.1, R156.1, U39.P$4, U39.P$8
GND39: C237.2, C238.2, C239.2, C240.2, J40.3, R158.1, R160.1, U40.P$4, U40.P$8
GND40: C243.2, C244.2, C245.2, C246.2, J41.3, R162.1, R164.1, U41.P$4, U41.P$8
GND41: C249.2, C250.2, C251.2, C252.2, J42.3, R166.1, R168.1, U42.P$4, U42.P$8
GND42: C255.2, C256.2, C257.2, C258.2, J43.3, R170.1, R172.1, U43.P$4, U43.P$8
GND43: C261.2, C262.2, C263.2, C264.2, J44.3, R174.1, R176.1, U44.P$4, U44.P$8
GND44: C267.2, C268.2, C269.2, C270.2, J45.3, R178.1, R180.1, U45.P$4, U45.P$8
GND45: C273.2, C274.2, C275.2, C276.2, J46.3, R182.1, R184.1, U46.P$4, U46.P$8
GND46: C279.2, C280.2, C281.2, C282.2, J47.3, R186.1, R188.1, U47.P$4, U47.P$8
GND47: C285.2, C286.2, C287.2, C288.2, J48.3, R190.1, R192.1, U48.P$4, U48.P$8
unnamed: C8.1, U2.P$6
unnamed: C14.1, U3.P$6
unnamed: C20.1, U4.P$6
unnamed: C2.1, U1.P$6
unnamed: C26.1, U5.P$6
unnamed: C32.1, U6.P$6
unnamed: C38.1, U7.P$6
unnamed: C44.1, U8.P$6
unnamed: C50.1, U9.P$6
unnamed: C56.1, U10.P$6
unnamed: C62.1, U11.P$6
unnamed: C68.1, U12.P$6
unnamed: C74.1, U13.P$6
unnamed: C80.1, U14.P$6
unnamed: C86.1, U15.P$6
unnamed: C92.1, U16.P$6
unnamed: C98.1, U17.P$6
unnamed: C104.1, U18.P$6
unnamed: C110.1, U19.P$6
unnamed: C116.1, U20.P$6
unnamed: C122.1, U21.P$6
unnamed: C128.1, U22.P$6
unnamed: C134.1, U23.P$6
unnamed: C140.1, U24.P$6
unnamed: C146.1, U25.P$6
unnamed: C152.1, U26.P$6
unnamed: C158.1, U27.P$6
unnamed: C164.1, U28.P$6
unnamed: C170.1, U29.P$6
unnamed: C176.1, U30.P$6
unnamed: C182.1, U31.P$6
unnamed: C188.1, U32.P$6
unnamed: C194.1, U33.P$6
unnamed: C200.1, U34.P$6
unnamed: C206.1, U35.P$6
unnamed: C212.1, U36.P$6
unnamed: C218.1, U37.P$6
unnamed: C224.1, U38.P$6
unnamed: C230.1, U39.P$6
unnamed: C236.1, U40.P$6
unnamed: C242.1, U41.P$6
unnamed: C248.1, U42.P$6
unnamed: C254.1, U43.P$6
unnamed: C260.1, U44.P$6
unnamed: C266.1, U45.P$6
unnamed: C272.1, U46.P$6
unnamed: C278.1, U47.P$6
unnamed: C284.1, U48.P$6
SW: C2.2, L1.P$1, U1.P$7, U1.P$9
SW1: C8.2, L2.P$1, U2.P$7, U2.P$9
SW2: C14.2, L3.P$1, U3.P$7, U3.P$9
SW3: C20.2, L4.P$1, U4.P$7, U4.P$9
SW4: C26.2, L5.P$1, U5.P$7, U5.P$9
SW5: C32.2, L6.P$1, U6.P$7, U6.P$9
SW6: C38.2, L7.P$1, U7.P$7, U7.P$9
SW7: C44.2, L8.P$1, U8.P$7, U8.P$9
SW8: C50.2, L9.P$1, U9.P$7, U9.P$9
SW9: C56.2, L10.P$1, U10.P$7, U10.P$9
SW10: C62.2, L11.P$1, U11.P$7, U11.P$9
SW11: C68.2, L12.P$1, U12.P$7, U12.P$9
SW12: C74.2, L13.P$1, U13.P$7, U13.P$9
SW13: C80.2, L14.P$1, U14.P$7, U14.P$9
SW14: C86.2, L15.P$1, U15.P$7, U15.P$9
SW15: C92.2, L16.P$1, U16.P$7, U16.P$9
SW16: C98.2, L17.P$1, U17.P$7, U17.P$9
SW17: C104.2, L18.P$1, U18.P$7, U18.P$9
SW18: C110.2, L19.P$1, U19.P$7, U19.P$9
SW19: C116.2, L20.P$1, U20.P$7, U20.P$9
SW20: C122.2, L21.P$1, U21.P$7, U21.P$9
SW21: C128.2, L22.P$1, U22.P$7, U22.P$9
SW22: C134.2, L23.P$1, U23.P$7, U23.P$9
SW23: C140.2, L24.P$1, U24.P$7, U24.P$9
SW24: C146.2, L25.P$1, U25.P$7, U25.P$9
SW25: C152.2, L26.P$1, U26.P$7, U26.P$9
SW26: C158.2, L27.P$1, U27.P$7, U27.P$9
SW27: C164.2, L28.P$1, U28.P$7, U28.P$9
SW28: C170.2, L29.P$1, U29.P$7, U29.P$9
SW29: C176.2, L30.P$1, U30.P$7, U30.P$9
SW30: C182.2, L31.P$1, U31.P$7, U31.P$9
SW31: C188.2, L32.P$1, U32.P$7, U32.P$9
SW32: C194.2, L33.P$1, U33.P$7, U33.P$9
SW33: C200.2, L34.P$1, U34.P$7, U34.P$9
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

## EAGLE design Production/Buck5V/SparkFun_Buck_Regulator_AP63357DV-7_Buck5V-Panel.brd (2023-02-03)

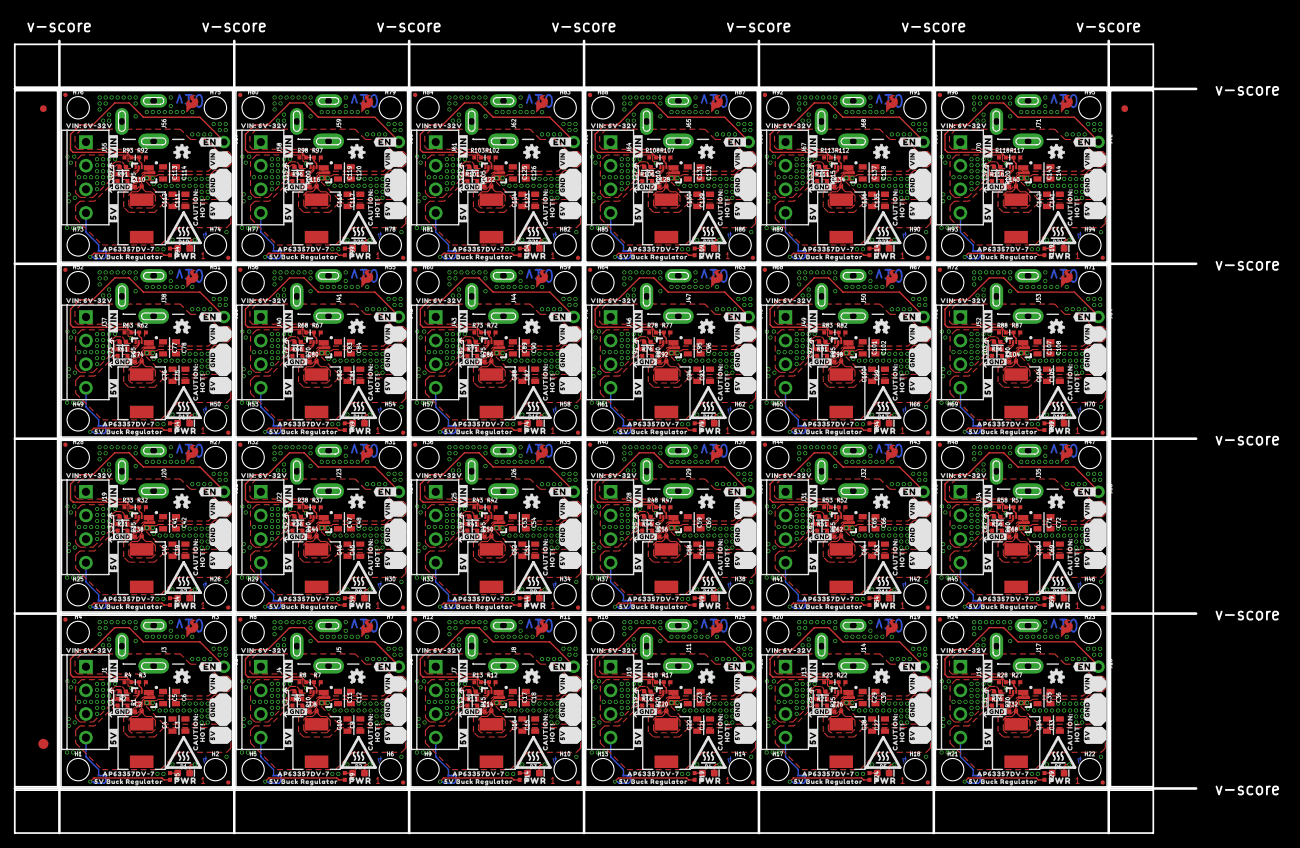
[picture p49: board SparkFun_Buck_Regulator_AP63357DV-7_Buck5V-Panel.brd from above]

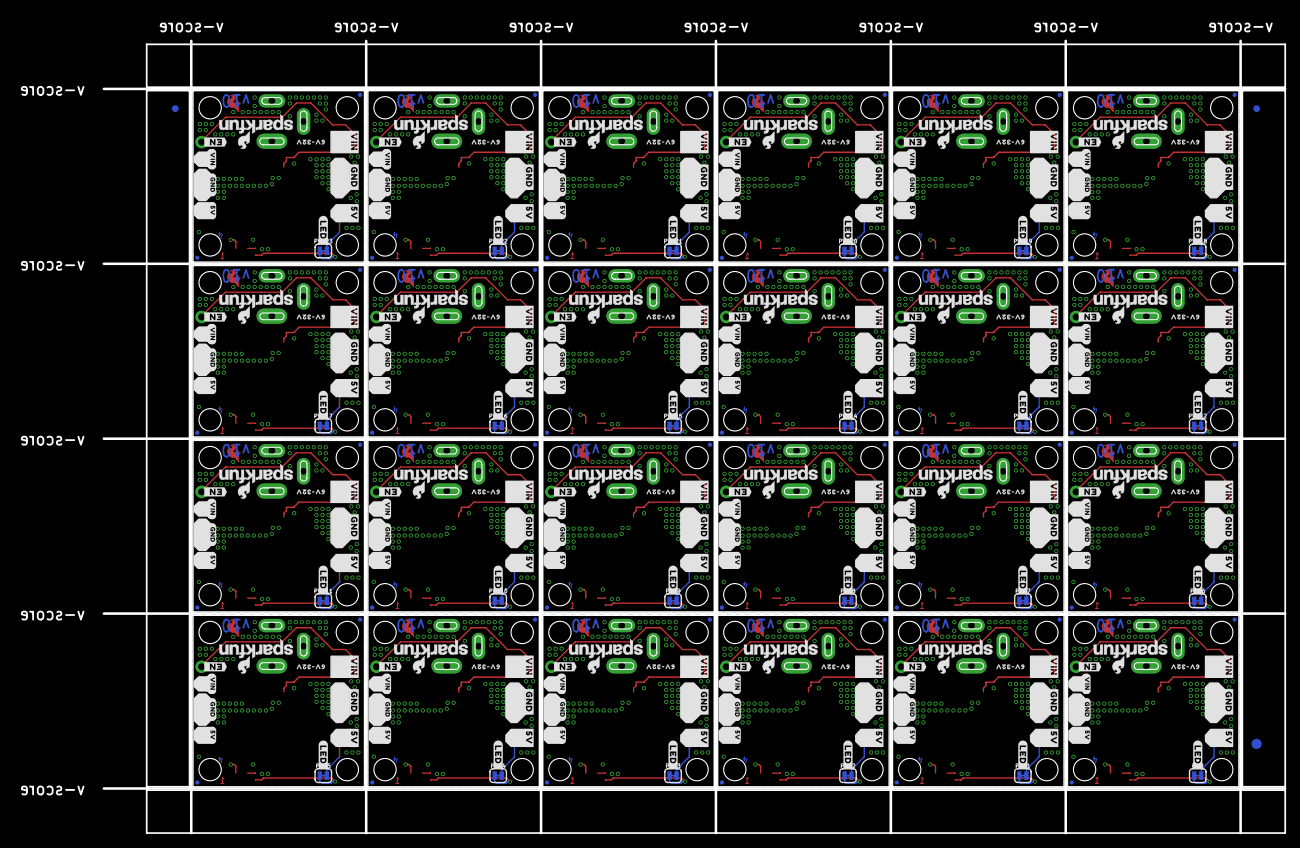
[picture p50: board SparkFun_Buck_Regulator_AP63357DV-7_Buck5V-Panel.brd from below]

Board: 4 copper layers, 175.0 x 117.3 mm, 1254 parts (315 on the bottom side), 216 nets.

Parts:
C1, C7, C13, C19, C25, C31, C37, C43, C49, C55, C61, C67, C73, C79, C85, C91, C97, C103, C109, C115, C121, C127, C133, C139: 47pF; 0402-TIGHT
C2, C8, C14, C20, C26, C32, C38, C44, C50, C56, C62, C68, C74, C80, C86, C92, C98, C104, C110, C116, C122, C128, C134, C140: 0.1uF; 0402-TIGHT
C3, C4, C9, C10, C15, C16, C21, C22, C27, C28, C33, C34, C39, C40, C45, C46, C51, C52, C57, C58, C63, C64, C69, C70, C75, C76, C81, C82, C87, C88, C93, C94, C99, C100, C105, C106, C111, C112, C117, C118, C123, C124, C129, C130, C135, C136, C141, C142: 22uF; 0805
C5, C6, C11, C12, C17, C18, C23, C24, C29, C30, C35, C36, C41, C42, C47, C48, C53, C54, C59, C60, C65, C66, C71, C72, C77, C78, C83, C84, C89, C90, C95, C96, C101, C102, C107, C108, C113, C114, C119, C120, C125, C126, C131, C132, C137, C138, C143, C144: 4.7uF; 0805
D1, D2, D3, D4, D5, D6, D7, D8, D9, D10, D11, D12, D13, D14, D15, D16, D17, D18, D19, D20, D21, D22, D23, D24: RED; LED-0603
E$1, E$2, E$3, E$4: FIDUCIAL-1X2
E$5, E$6: FIDUCIAL-1.5X3
FD1, FD2, FD3, FD4, FD5, FD6, FD7, FD8, FD9, FD10, FD11, FD12, FD13, FD14, FD15, FD16, FD17, FD18, FD19, FD20, FD21, FD22, FD23, FD24, FD25, FD26, FD27, FD28, FD29, FD30, FD31, FD32, FD33, FD34, FD35, FD36, FD37, FD38, FD39, FD40, FD41, FD42, FD43, FD44, FD45, FD46, FD47, FD48, FD49, FD50, FD51, FD52, FD53, FD54, FD55, FD56, FD57, FD58, FD59, FD60, FD61, FD62, FD63, FD64, FD65, FD66, FD67, FD68, FD69, FD70, FD71, FD72, FD73, FD74, FD75, FD76, FD77, FD78, FD79, FD80, FD81, FD82, FD83, FD84, FD85, FD86, FD87, FD88, FD89, FD90, FD91, FD92, FD93, FD94, FD95, FD96: FIDUCIALUFIDUCIAL; FIDUCIAL-MICRO
H1, H2, H3, H4, H5, H6, H7, H8, H9, H10, H11, H12, H13, H14, H15, H16, H17, H18, H19, H20, H21, H22, H23, H24, H25, H26, H27, H28, H29, H30, H31, H32, H33, H34, H35, H36, H37, H38, H39, H40, H41, H42, H43, H44, H45, H46, H47, H48, H49, H50, H51, H52, H53, H54, H55, H56, H57, H58, H59, H60, H61, H62, H63, H64, H65, H66, H67, H68, H69, H70, H71, H72, H73, H74, H75, H76, H77, H78, H79, H80, H81, H82, H83, H84, H85, H86, H87, H88, H89, H90, H91, H92, H93, H94, H95, H96: STAND-OFF
J1, J4, J7, J10, J13, J16, J19, J22, J25, J28, J31, J34, J37, J40, J43, J46, J49, J52, J55, J58, J61, J64, J67, J70: SCREWTERMINAL-3.5MM-4
J2, J6, J9, J12, J15, J18, J21, J24, J27, J30, J33, J36, J39, J42, J45, J48, J51, J54, J57, J60, J63, J66, J69, J72: 1X05_NO_SILK
J3, J5, J8, J11, J14, J17, J20, J23, J26, J29, J32, J35, J38, J41, J44, J47, J50, J53, J56, J59, J62, J65, J68, J71: POWER_JACK; POWER_JACK_PTH_SLOT_NO_OVRHNG_SILK
L1, L2, L3, L4, L5, L6, L7, L8, L9, L10, L11, L12, L13, L14, L15, L16, L17, L18, L19, L20, L21, L22, L23, L24: 6.8UH; 07A7_6U8H
LOGO1, LOGO3, LOGO5, LOGO7, LOGO9, LOGO11, LOGO13, LOGO15, LOGO17, LOGO19, LOGO21, LOGO23, LOGO25, LOGO27, LOGO29, LOGO31, LOGO33, LOGO35, LOGO37, LOGO39, LOGO41, LOGO43, LOGO45, LOGO47: OSHW-LOGOMINI; OSHW-LOGO-MINI
LOGO2, LOGO4, LOGO6, LOGO8, LOGO10, LOGO12, LOGO14, LOGO16, LOGO18, LOGO20, LOGO22, LOGO24, LOGO26, LOGO28, LOGO30, LOGO32, LOGO34, LOGO36, LOGO38, LOGO40, LOGO42, LOGO44, LOGO46, LOGO48: SFE_LOGO_NAME_FLAME.1_INCH; SFE_LOGO_NAME_FLAME_.1
PWR, PWR1, PWR2, PWR3, PWR4, PWR5, PWR6, PWR7, PWR8, PWR9, PWR10, PWR11, PWR12, PWR13, PWR14, PWR15, PWR16, PWR17, PWR18, PWR19, PWR20, PWR21, PWR22, PWR23: JUMPER-SMT_2_NC_TRACE_SILK; SMT-JUMPER_2_NC_TRACE_SILK
R1, R10, R15, R20, R25, R30, R35, R40, R45, R50, R55, R60, R65, R70, R75, R80, R85, R90, R95, R100, R105, R110, R115, R120: 220K; 0402-TIGHT
R2, R6, R11, R16, R21, R26, R31, R36, R41, R46, R51, R56, R61, R66, R71, R76, R81, R86, R91, R96, R101, R106, R111, R116: 41.2K; 0402-TIGHT
R3, R7, R12, R17, R22, R27, R32, R37, R42, R47, R52, R57, R62, R67, R72, R77, R82, R87, R92, R97, R102, R107, R112, R117: 93.1k; 0402-TIGHT
R4, R8, R13, R18, R23, R28, R33, R38, R43, R48, R53, R58, R63, R68, R73, R78, R83, R88, R93, R98, R103, R108, R113, R118: 22k; 0402-TIGHT
R5, R9, R14, R19, R24, R29, R34, R39, R44, R49, R54, R59, R64, R69, R74, R79, R84, R89, R94, R99, R104, R109, R114, R119: 2.2k; 0402-TIGHT
U1, U2, U3, U4, U5, U6, U7, U8, U9, U10, U11, U12, U13, U14, U15, U16, U17, U18, U19, U20, U21, U22, U23, U24: AP63357; V-DFN3020-13
U$1, U$25, U$50, U$74, U$98, U$122, U$146, U$170, U$194, U$218, U$242, U$266, U$290, U$314, U$338, U$362, U$386, U$410, U$434, U$458, U$482, U$506, U$530, U$554: AP63357DV#70
U$2, U$23, U$49, U$73, U$97, U$121, U$145, U$169, U$193, U$217, U$241, U$265, U$289, U$313, U$337, U$361, U$385, U$409, U$433, U$457, U$481, U$505, U$529, U$553: 5V_BUCK_REGULATOR0
U$3, U$43, U$67, U$91, U$115, U$139, U$163, U$187, U$211, U$235, U$259, U$283, U$307, U$331, U$355, U$379, U$403, U$427, U$451, U$475, U$499, U$523, U$547, U$571: #5V#4
U$4, U$44, U$68, U$92, U$116, U$140, U$164, U$188, U$212, U$236, U$260, U$284, U$308, U$332, U$356, U$380, U$404, U$428, U$452, U$476, U$500, U$524, U$548, U$572: #VIN#8
U$5, U$13, U$28, U$37, U$52, U$61, U$76, U$85, U$100, U$109, U$124, U$133, U$148, U$157, U$172, U$181, U$196, U$205, U$220, U$229, U$244, U$253, U$268, U$277, U$292, U$301, U$316, U$325, U$340, U$349, U$364, U$373, U$388, U$397, U$412, U$421, U$436, U$445, U$460, U$469, U$484, U$493, U$508, U$517, U$532, U$541, U$556, U$565: #VIN#0
U$6, U$7, U$38, U$39, U$62, U$63, U$86, U$87, U$110, U$111, U$134, U$135, U$158, U$159, U$182, U$183, U$206, U$207, U$230, U$231, U$254, U$255, U$278, U$279, U$302, U$303, U$326, U$327, U$350, U$351, U$374, U$375, U$398, U$399, U$422, U$423, U$446, U$447, U$470, U$471, U$494, U$495, U$518, U$519, U$542, U$543, U$566, U$567: #GND#0
U$8, U$19, U$27, U$31, U$51, U$55, U$75, U$79, U$99, U$103, U$123, U$127, U$147, U$151, U$171, U$175, U$195, U$199, U$219, U$223, U$243, U$247, U$267, U$271, U$291, U$295, U$315, U$319, U$339, U$343, U$363, U$367, U$387, U$391, U$411, U$415, U$435, U$439, U$459, U$463, U$483, U$487, U$507, U$511, U$531, U$535, U$555, U$559: #EN_#0
U$9, U$45, U$69, U$93, U$117, U$141, U$165, U$189, U$213, U$237, U$261, U$285, U$309, U$333, U$357, U$381, U$405, U$429, U$453, U$477, U$501, U$525, U$549, U$573: #GND#9
U$10, U$46, U$70, U$94, U$118, U$142, U$166, U$190, U$214, U$238, U$262, U$286, U$310, U$334, U$358, U$382, U$406, U$430, U$454, U$478, U$502, U$526, U$550, U$574: #5V#10
U$11, U$47, U$71, U$95, U$119, U$143, U$167, U$191, U$215, U$239, U$263, U$287, U$311, U$335, U$359, U$383, U$407, U$431, U$455, U$479, U$503, U$527, U$551, U$575: 6V#32V10
U$12, U$48, U$72, U$96, U$120, U$144, U$168, U$192, U$216, U$240, U$264, U$288, U$312, U$336, U$360, U$384, U$408, U$432, U$456, U$480, U$504, U$528, U$552, U$576: HOT##0
U$14, U$24, U$36, U$40, U$60, U$64, U$84, U$88, U$108, U$112, U$132, U$136, U$156, U$160, U$180, U$184, U$204, U$208, U$228, U$232, U$252, U$256, U$276, U$280, U$300, U$304, U$324, U$328, U$348, U$352, U$372, U$376, U$396, U$400, U$420, U$424, U$444, U$448, U$468, U$472, U$492, U$496, U$516, U$520, U$540, U$544, U$564, U$568: #5V#0
U$15, U$32, U$56, U$80, U$104, U$128, U$152, U$176, U$200, U$224, U$248, U$272, U$296, U$320, U$344, U$368, U$392, U$416, U$440, U$464, U$488, U$512, U$536, U$560: #LED_#0
U$16, U$41, U$65, U$89, U$113, U$137, U$161, U$185, U$209, U$233, U$257, U$281, U$305, U$329, U$353, U$377, U$401, U$425, U$449, U$473, U$497, U$521, U$545, U$569: CAUTION#0
U$17, U$29, U$53, U$77, U$101, U$125, U$149, U$173, U$197, U$221, U$245, U$269, U$293, U$317, U$341, U$365, U$389, U$413, U$437, U$461, U$485, U$509, U$533, U$557: SFE_LOGO_FLAME_COPPER_EXPOSED_.1
U$18, U$30, U$54, U$78, U$102, U$126, U$150, U$174, U$198, U$222, U$246, U$270, U$294, U$318, U$342, U$366, U$390, U$414, U$438, U$462, U$486, U$510, U$534, U$558: VIN#_6V#32V0
U$20, U$33, U$57, U$81, U$105, U$129, U$153, U$177, U$201, U$225, U$249, U$273, U$297, U$321, U$345, U$369, U$393, U$417, U$441, U$465, U$489, U$513, U$537, U$561: PWR0
U$21, U$34, U$58, U$82, U$106, U$130, U$154, U$178, U$202, U$226, U$250, U$274, U$298, U$322, U$346, U$370, U$394, U$418, U$442, U$466, U$490, U$514, U$538, U$562: #GND#1
U$22, U$35, U$59, U$83, U$107, U$131, U$155, U$179, U$203, U$227, U$251, U$275, U$299, U$323, U$347, U$371, U$395, U$419, U$443, U$467, U$491, U$515, U$539, U$563: HIGH_TEMP_WARNING
U$26, U$42, U$66, U$90, U$114, U$138, U$162, U$186, U$210, U$234, U$258, U$282, U$306, U$330, U$354, U$378, U$402, U$426, U$450, U$474, U$498, U$522, U$546, U$570: #VIN#3

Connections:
5V: C1.1, C3.1, C4.1, J1.4, J2.5, L1.P$2, PWR.2, R1.2
5V1: C7.1, C9.1, C10.1, J4.4, J6.5, L2.P$2, PWR1.2, R10.2
5V2: C13.1, C15.1, C16.1, J7.4, J9.5, L3.P$2, PWR2.2, R15.2
5V3: C19.1, C21.1, C22.1, J10.4, J12.5, L4.P$2, PWR3.2, R20.2
5V4: C25.1, C27.1, C28.1, J13.4, J15.5, L5.P$2, PWR4.2, R25.2
5V5: C31.1, C33.1, C34.1, J16.4, J18.5, L6.P$2, PWR5.2, R30.2
5V6: C37.1, C39.1, C40.1, J19.4, J21.5, L7.P$2, PWR6.2, R35.2
5V7: C43.1, C45.1, C46.1, J22.4, J24.5, L8.P$2, PWR7.2, R40.2
5V8: C49.1, C51.1, C52.1, J25.4, J27.5, L9.P$2, PWR8.2, R45.2
5V9: C55.1, C57.1, C58.1, J28.4, J30.5, L10.P$2, PWR9.2, R50.2
5V10: C61.1, C63.1, C64.1, J31.4, J33.5, L11.P$2, PWR10.2, R55.2
5V11: C67.1, C69.1, C70.1, J34.4, J36.5, L12.P$2, PWR11.2, R60.2
5V12: C73.1, C75.1, C76.1, J37.4, J39.5, L13.P$2, PWR12.2, R65.2
5V13: C79.1, C81.1, C82.1, J40.4, J42.5, L14.P$2, PWR13.2, R70.2
5V14: C85.1, C87.1, C88.1, J43.4, J45.5, L15.P$2, PWR14.2, R75.2
5V15: C91.1, C93.1, C94.1, J46.4, J48.5, L16.P$2, PWR15.2, R80.2
5V16: C97.1, C99.1, C100.1, J49.4, J51.5, L17.P$2, PWR16.2, R85.2
5V17: C103.1, C105.1, C106.1, J52.4, J54.5, L18.P$2, PWR17.2, R90.2
5V18: C109.1, C111.1, C112.1, J55.4, J57.5, L19.P$2, PWR18.2, R95.2
5V19: C115.1, C117.1, C118.1, J58.4, J60.5, L20.P$2, PWR19.2, R100.2
5V20: C121.1, C123.1, C124.1, J61.4, J63.5, L21.P$2, PWR20.2, R105.2
5V21: C127.1, C129.1, C130.1, J64.4, J66.5, L22.P$2, PWR21.2, R110.2
5V22: C133.1, C135.1, C136.1, J67.4, J69.5, L23.P$2, PWR22.2, R115.2
5V23: C139.1, C141.1, C142.1, J70.4, J72.5, L24.P$2, PWR23.2, R120.2
EN: J2.1, R3.1, R4.2, U1.P$2
EN1: J6.1, R7.1, R8.2, U2.P$2
EN2: J9.1, R12.1, R13.2, U3.P$2
EN3: J12.1, R17.1, R18.2, U4.P$2
EN4: J15.1, R22.1, R23.2, U5.P$2
EN5: J18.1, R27.1, R28.2, U6.P$2
EN6: J21.1, R32.1, R33.2, U7.P$2
EN7: J24.1, R37.1, R38.2, U8.P$2
EN8: J27.1, R42.1, R43.2, U9.P$2
EN9: J30.1, R47.1, R48.2, U10.P$2
EN10: J33.1, R52.1, R53.2, U11.P$2
EN11: J36.1, R57.1, R58.2, U12.P$2
EN12: J39.1, R62.1, R63.2, U13.P$2
EN13: J42.1, R67.1, R68.2, U14.P$2
EN14: J45.1, R72.1, R73.2, U15.P$2
EN15: J48.1, R77.1, R78.2, U16.P$2
EN16: J51.1, R82.1, R83.2, U17.P$2
EN17: J54.1, R87.1, R88.2, U18.P$2
EN18: J57.1, R92.1, R93.2, U19.P$2
EN19: J60.1, R97.1, R98.2, U20.P$2
EN20: J63.1, R102.1, R103.2, U21.P$2
EN21: J66.1, R107.1, R108.2, U22.P$2
EN22: J69.1, R112.1, R113.2, U23.P$2
EN23: J72.1, R117.1, R118.2, U24.P$2
FB: C1.2, R1.1, R2.2, U1.P$3
FB1: C7.2, R6.2, R10.1, U2.P$3
FB2: C13.2, R11.2, R15.1, U3.P$3
FB3: C19.2, R16.2, R20.1, U4.P$3
FB4: C25.2, R21.2, R25.1, U5.P$3
FB5: C31.2, R26.2, R30.1, U6.P$3
FB6: C37.2, R31.2, R35.1, U7.P$3
FB7: C43.2, R36.2, R40.1, U8.P$3
FB8: C49.2, R41.2, R45.1, U9.P$3
FB9: C55.2, R46.2, R50.1, U10.P$3
FB10: C61.2, R51.2, R55.1, U11.P$3
FB11: C67.2, R56.2, R60.1, U12.P$3
FB12: C73.2, R61.2, R65.1, U13.P$3
FB13: C79.2, R66.2, R70.1, U14.P$3
FB14: C85.2, R71.2, R75.1, U15.P$3
FB15: C91.2, R76.2, R80.1, U16.P$3
FB16: C97.2, R81.2, R85.1, U17.P$3
FB17: C103.2, R86.2, R90.1, U18.P$3
FB18: C109.2, R91.2, R95.1, U19.P$3
FB19: C115.2, R96.2, R100.1, U20.P$3
FB20: C121.2, R101.2, R105.1, U21.P$3
FB21: C127.2, R106.2, R110.1, U22.P$3
FB22: C133.2, R111.2, R115.1, U23.P$3
FB23: C139.2, R116.2, R120.1, U24.P$3
GND: C3.2, C4.2, C5.2, C6.2, D1.C, J1.2, J1.3, J2.3, J2.4, J3.GND, R2.1, R4.1, U1.P$4, U1.P$8
GND1: C9.2, C10.2, C11.2, C12.2, D2.C, J4.2, J4.3, J5.GND, J6.3, J6.4, R6.1, R8.1, U2.P$4, U2.P$8
GND2: C15.2, C16.2, C17.2, C18.2, D3.C, J7.2, J7.3, J8.GND, J9.3, J9.4, R11.1, R13.1, U3.P$4, U3.P$8
GND3: C21.2, C22.2, C23.2, C24.2, D4.C, J10.2, J10.3, J11.GND, J12.3, J12.4, R16.1, R18.1, U4.P$4, U4.P$8
GND4: C27.2, C28.2, C29.2, C30.2, D5.C, J13.2, J13.3, J14.GND, J15.3, J15.4, R21.1, R23.1, U5.P$4, U5.P$8
GND5: C33.2, C34.2, C35.2, C36.2, D6.C, J16.2, J16.3, J17.GND, J18.3, J18.4, R26.1, R28.1, U6.P$4, U6.P$8
GND6: C39.2, C40.2, C41.2, C42.2, D7.C, J19.2, J19.3, J20.GND, J21.3, J21.4, R31.1, R33.1, U7.P$4, U7.P$8
GND7: C45.2, C46.2, C47.2, C48.2, D8.C, J22.2, J22.3, J23.GND, J24.3, J24.4, R36.1, R38.1, U8.P$4, U8.P$8
GND8: C51.2, C52.2, C53.2, C54.2, D9.C, J25.2, J25.3, J26.GND, J27.3, J27.4, R41.1, R43.1, U9.P$4, U9.P$8
GND9: C57.2, C58.2, C59.2, C60.2, D10.C, J28.2, J28.3, J29.GND, J30.3, J30.4, R46.1, R48.1, U10.P$4, U10.P$8
GND10: C63.2, C64.2, C65.2, C66.2, D11.C, J31.2, J31.3, J32.GND, J33.3, J33.4, R51.1, R53.1, U11.P$4, U11.P$8
GND11: C69.2, C70.2, C71.2, C72.2, D12.C, J34.2, J34.3, J35.GND, J36.3, J36.4, R56.1, R58.1, U12.P$4, U12.P$8
GND12: C75.2, C76.2, C77.2, C78.2, D13.C, J37.2, J37.3, J38.GND, J39.3, J39.4, R61.1, R63.1, U13.P$4, U13.P$8
GND13: C81.2, C82.2, C83.2, C84.2, D14.C, J40.2, J40.3, J41.GND, J42.3, J42.4, R66.1, R68.1, U14.P$4, U14.P$8
GND14: C87.2, C88.2, C89.2, C90.2, D15.C, J43.2, J43.3, J44.GND, J45.3, J45.4, R71.1, R73.1, U15.P$4, U15.P$8
GND15: C93.2, C94.2, C95.2, C96.2, D16.C, J46.2, J46.3, J47.GND, J48.3, J48.4, R76.1, R78.1, U16.P$4, U16.P$8
GND16: C99.2, C100.2, C101.2, C102.2, D17.C, J49.2, J49.3, J50.GND, J51.3, J51.4, R81.1, R83.1, U17.P$4, U17.P$8
GND17: C105.2, C106.2, C107.2, C108.2, D18.C, J52.2, J52.3, J53.GND, J54.3, J54.4, R86.1, R88.1, U18.P$4, U18.P$8
GND18: C111.2, C112.2, C113.2, C114.2, D19.C, J55.2, J55.3, J56.GND, J57.3, J57.4, R91.1, R93.1, U19.P$4, U19.P$8
GND19: C117.2, C118.2, C119.2, C120.2, D20.C, J58.2, J58.3, J59.GND, J60.3, J60.4, R96.1, R98.1, U20.P$4, U20.P$8
GND20: C123.2, C124.2, C125.2, C126.2, D21.C, J61.2, J61.3, J62.GND, J63.3, J63.4, R101.1, R103.1, U21.P$4, U21.P$8
GND21: C129.2, C130.2, C131.2, C132.2, D22.C, J64.2, J64.3, J65.GND, J66.3, J66.4, R106.1, R108.1, U22.P$4, U22.P$8
GND22: C135.2, C136.2, C137.2, C138.2, D23.C, J67.2, J67.3, J68.GND, J69.3, J69.4, R111.1, R113.1, U23.P$4, U23.P$8
GND23: C141.2, C142.2, C143.2, C144.2, D24.C, J70.2, J70.3, J71.GND, J72.3, J72.4, R116.1, R118.1, U24.P$4, U24.P$8
unnamed: C8.1, U2.P$6
unnamed: D1.A, R5.1
unnamed: D2.A, R9.1
unnamed: C2.1, U1.P$6
unnamed: PWR.1, R5.2
unnamed: PWR1.1, R9.2
unnamed: C14.1, U3.P$6
unnamed: D3.A, R14.1
unnamed: PWR2.1, R14.2
unnamed: C20.1, U4.P$6
unnamed: D4.A, R19.1
unnamed: PWR3.1, R19.2
unnamed: C26.1, U5.P$6
unnamed: D5.A, R24.1
unnamed: PWR4.1, R24.2
unnamed: C32.1, U6.P$6
unnamed: D6.A, R29.1
unnamed: PWR5.1, R29.2
unnamed: C38.1, U7.P$6
unnamed: D7.A, R34.1
unnamed: PWR6.1, R34.2
unnamed: C44.1, U8.P$6
unnamed: D8.A, R39.1
unnamed: PWR7.1, R39.2
unnamed: C50.1, U9.P$6
unnamed: D9.A, R44.1
unnamed: PWR8.1, R44.2
unnamed: C56.1, U10.P$6
unnamed: D10.A, R49.1
unnamed: PWR9.1, R49.2
unnamed: C62.1, U11.P$6
unnamed: D11.A, R54.1
unnamed: PWR10.1, R54.2
unnamed: C68.1, U12.P$6
unnamed: D12.A, R59.1
unnamed: PWR11.1, R59.2
unnamed: C74.1, U13.P$6
unnamed: D13.A, R64.1
unnamed: PWR12.1, R64.2
unnamed: C80.1, U14.P$6
unnamed: D14.A, R69.1
unnamed: PWR13.1, R69.2
unnamed: C86.1, U15.P$6
unnamed: D15.A, R74.1
unnamed: PWR14.1, R74.2
unnamed: C92.1, U16.P$6
unnamed: D16.A, R79.1
unnamed: PWR15.1, R79.2
unnamed: C98.1, U17.P$6
unnamed: D17.A, R84.1
unnamed: PWR16.1, R84.2
unnamed: C104.1, U18.P$6
unnamed: D18.A, R89.1
unnamed: PWR17.1, R89.2
unnamed: C110.1, U19.P$6
unnamed: D19.A, R94.1
unnamed: PWR18.1, R94.2
unnamed: C116.1, U20.P$6
unnamed: D20.A, R99.1
unnamed: PWR19.1, R99.2
unnamed: C122.1, U21.P$6
unnamed: D21.A, R104.1
unnamed: PWR20.1, R104.2
unnamed: C128.1, U22.P$6
unnamed: D22.A, R109.1
unnamed: PWR21.1, R109.2
unnamed: C134.1, U23.P$6
unnamed: D23.A, R114.1
unnamed: PWR22.1, R114.2
unnamed: C140.1, U24.P$6
unnamed: D24.A, R119.1
unnamed: PWR23.1, R119.2
SW: C2.2, L1.P$1, U1.P$7, U1.P$9
SW1: C8.2, L2.P$1, U2.P$7, U2.P$9
SW2: C14.2, L3.P$1, U3.P$7, U3.P$9
SW3: C20.2, L4.P$1, U4.P$7, U4.P$9
SW4: C26.2, L5.P$1, U5.P$7, U5.P$9
SW5: C32.2, L6.P$1, U6.P$7, U6.P$9
SW6: C38.2, L7.P$1, U7.P$7, U7.P$9
SW7: C44.2, L8.P$1, U8.P$7, U8.P$9
SW8: C50.2, L9.P$1, U9.P$7, U9.P$9
SW9: C56.2, L10.P$1, U10.P$7, U10.P$9
SW10: C62.2, L11.P$1, U11.P$7, U11.P$9
SW11: C68.2, L12.P$1, U12.P$7, U12.P$9
SW12: C74.2, L13.P$1, U13.P$7, U13.P$9
SW13: C80.2, L14.P$1, U14.P$7, U14.P$9
SW14: C86.2, L15.P$1, U15.P$7, U15.P$9
SW15: C92.2, L16.P$1, U16.P$7, U16.P$9
SW16: C98.2, L17.P$1, U17.P$7, U17.P$9
SW17: C104.2, L18.P$1, U18.P$7, U18.P$9
SW18: C110.2, L19.P$1, U19.P$7, U19.P$9
SW19: C116.2, L20.P$1, U20.P$7, U20.P$9
SW20: C122.2, L21.P$1, U21.P$7, U21.P$9
SW21: C128.2, L22.P$1, U22.P$7, U22.P$9
SW22: C134.2, L23.P$1, U23.P$7, U23.P$9
SW23: C140.2, L24.P$1, U24.P$7, U24.P$9
VIN: C5.1, C6.1, J1.1, J2.2, J3.PWR, R3.2, U1.P$1
VIN1: C11.1, C12.1, J4.1, J5.PWR, J6.2, R7.2, U2.P$1
VIN2: C17.1, C18.1, J7.1, J8.PWR, J9.2, R12.2, U3.P$1
VIN3: C23.1, C24.1, J10.1, J11.PWR, J12.2, R17.2, U4.P$1
VIN4: C29.1, C30.1, J13.1, J14.PWR, J15.2, R22.2, U5.P$1
VIN5: C35.1, C36.1, J16.1, J17.PWR, J18.2, R27.2, U6.P$1
VIN6: C41.1, C42.1, J19.1, J20.PWR, J21.2, R32.2, U7.P$1
VIN7: C47.1, C48.1, J22.1, J23.PWR, J24.2, R37.2, U8.P$1
VIN8: C53.1, C54.1, J25.1, J26.PWR, J27.2, R42.2, U9.P$1
VIN9: C59.1, C60.1, J28.1, J29.PWR, J30.2, R47.2, U10.P$1
VIN10: C65.1, C66.1, J31.1, J32.PWR, J33.2, R52.2, U11.P$1
VIN11: C71.1, C72.1, J34.1, J35.PWR, J36.2, R57.2, U12.P$1
VIN12: C77.1, C78.1, J37.1, J38.PWR, J39.2, R62.2, U13.P$1
VIN13: C83.1, C84.1, J40.1, J41.PWR, J42.2, R67.2, U14.P$1
VIN14: C89.1, C90.1, J43.1, J44.PWR, J45.2, R72.2, U15.P$1
VIN15: C95.1, C96.1, J46.1, J47.PWR, J48.2, R77.2, U16.P$1
VIN16: C101.1, C102.1, J49.1, J50.PWR, J51.2, R82.2, U17.P$1
VIN17: C107.1, C108.1, J52.1, J53.PWR, J54.2, R87.2, U18.P$1
VIN18: C113.1, C114.1, J55.1, J56.PWR, J57.2, R92.2, U19.P$1
VIN19: C119.1, C120.1, J58.1, J59.PWR, J60.2, R97.2, U20.P$1
VIN20: C125.1, C126.1, J61.1, J62.PWR, J63.2, R102.2, U21.P$1
VIN21: C131.1, C132.1, J64.1, J65.PWR, J66.2, R107.2, U22.P$1
VIN22: C137.1, C138.1, J67.1, J68.PWR, J69.2, R112.2, U23.P$1
VIN23: C143.1, C144.1, J70.1, J71.PWR, J72.2, R117.2, U24.P$1

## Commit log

2022-10-06 v01 completed, ready for shrinking to babybuck.
    [SparkFun_Buck_Regulator_AP63357DV-7_Buck5V.brd, SparkFun_Buck_Regulator_AP63357DV-7_Buck5V.sch]
2022-10-10 Added BabyBuck design.
    [SparkFun_Buck_Regulator_AP63357DV-7_BabyBuck5V.brd, SparkFun_Buck_Regulator_AP63357DV-7_BabyBuck5V.sch, SparkFun_Buck_Regulator_AP63357DV-7_Buck5V.brd]
2022-10-10 Added dimensions, ordering instructions, set board stackup.
    [SparkFun_Buck_Regulator_AP63357DV-7_BabyBuck5V.brd, SparkFun_Buck_Regulator_AP63357DV-7_Buck5V.brd, SparkFun_Buck_Regulator_AP63357DV-7_Buck5V.sch]
2022-10-10 Added AOI silk for separating R/Cs easier.
    [SparkFun_Buck_Regulator_AP63357DV-7_Buck5V.brd]
2022-10-10 Renumbered parts to match other schematic.
    [SparkFun_Buck_Regulator_AP63357DV-7_BabyBuck5V.brd, SparkFun_Buck_Regulator_AP63357DV-7_BabyBuck5V.sch]
2022-10-12 v01 changes implemented.
    Schematic:
    Add note for LED jumper
    Add green wire for EN
    Section titles center anchor
    Rename Regulator section
    Layout:
    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
    [SparkFun_Buck_Regulator_AP63357DV-7_BabyBuck5V.brd, SparkFun_Buck_Regulator_AP63357DV-7_BabyBuck5V.sch, SparkFun_Buck_Regulator_AP63357DV-7_Buck5V.brd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]
2022-10-12 Slight component shuffling in prep for protos.
    [SparkFun_Buck_Regulator_AP63357DV-7_BabyBuck5V.brd, SparkFun_Buck_Regulator_AP63357DV-7_Buck5V.brd]
2022-10-12 Remove silk from Power Jack so no silk overhangs.
    [SparkFun_Buck_Regulator_AP63357DV-7_Buck5V.brd, SparkFun_Buck_Regulator_AP63357DV-7_Buck5V.sch]
2022-10-12 Added gerbers for v01, added UVLO text to babybuck sch.
    [SparkFun_Buck_Regulator_AP63357DV-7_BabyBuck5V.GBL, SparkFun_Buck_Regulator_AP63357DV-7_BabyBuck5V.GBO, SparkFun_Buck_Regulator_AP63357DV-7_BabyBuck5V.GBP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]
2022-10-21 Removed unused lib parts. Added PROD_IDs to parts. Updated sch/brd files.
    [SparkFun_Buck_Regulator_AP63357DV-7_BabyBuck5V.brd, SparkFun_Buck_Regulator_AP63357DV-7_BabyBuck5V.sch, SparkFun_Buck_Regulator_AP63357DV-7_Buck5V.brd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]
2022-10-21 Swap POP for UnPOP'd connector.
    [SparkFun_Buck_Regulator_AP63357DV-7_BabyBuck5V.brd, SparkFun_Buck_Regulator_AP63357DV-7_BabyBuck5V.sch]
2022-12-13 Ready for v10 reds.
    1x1 - Thicken silk border on U1
    micro - Move fiducial to increase heat sink size
    both - panelize
    [SparkFun_Buck_Regulator_AP63357DV-7_BabyBuck5V-Panel.brd, SparkFun_Buck_Regulator_AP63357DV-7_BabyBuck5V.brd, SparkFun_Buck_Regulator_AP63357DV-7_BabyBuck5V.sc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]
2022-12-16 Centered schematic section titles.
    [SparkFun_Buck_Regulator_AP63357DV-7_BabyBuck5V.sch, SparkFun_Buck_Regulator_AP63357DV-7_Buck5V.sch]
2022-12-19 Prepare for v10 reds order.
    Change R1/R2 to better match 5V output requirement.
    Repanelize.
    Reorganize Production Folder Structure.
    [SparkFun_Buck_Regulator_AP63357DV-7_BabyBuck5V-Panel.GBL, SparkFun_Buck_Regulator_AP63357DV-7_BabyBuck5V-Panel.GBO, SparkFun_Buck_Regulator_AP63357DV-7_BabyBuc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]
2023-02-03 Reduce paste layer on buck. Repanelize.
    [SparkFun_Buck_Regulator_AP63357DV-7_BabyBuck5V-Panel.GBL, SparkFun_Buck_Regulator_AP63357DV-7_BabyBuck5V-Panel.GBO, SparkFun_Buck_Regulator_AP63357DV-7_BabyBuc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]
2023-02-10 Update dimensions
    Updated dimension layer
    - Fixed incorrect measurement for heat sink pad
    - Used boundary measurement instead of center point to reduce clutter
    [SparkFun_Buck_Regulator_AP63357DV-7_BabyBuck5V.brd]
2023-02-11 Update board dimension
    Move measurements for heat sink onto reference layer and add box outline
    [SparkFun_Buck_Regulator_AP63357DV-7_BabyBuck5V.brd, SparkFun_Buck_Regulator_AP63357DV-7_Buck5V.brd]
2023-02-11 Update Hookup Guide
    Include updated board dimensions
2023-02-17 Quiescent Current
    Added documentation for the quiescent current draw, based on issue #1
2023-03-09 Correct enable pin info
    Added default configuration info
    Added information about bypassing UVLO
2023-03-22 Add QR codes
    Add QR codes for printed hard copies
2023-03-22 Hide video
    QR code should be added for print outs
2023-04-14 New Buck Regs
    Add links for products and tutorial

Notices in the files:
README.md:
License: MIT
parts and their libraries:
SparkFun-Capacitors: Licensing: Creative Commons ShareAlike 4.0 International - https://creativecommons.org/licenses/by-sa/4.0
